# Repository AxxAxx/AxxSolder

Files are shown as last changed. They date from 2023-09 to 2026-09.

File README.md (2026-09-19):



<a href='https://ko-fi.com/axxaxx' target='_blank'>Donate  

Interested in purchasing an AxxSolder 3.2?  
On my website [5Dimensions](https://www.5dimensions.se/) you can purchase assembled and tested AxxSolder 3.2 boards with connectors and hardware.  

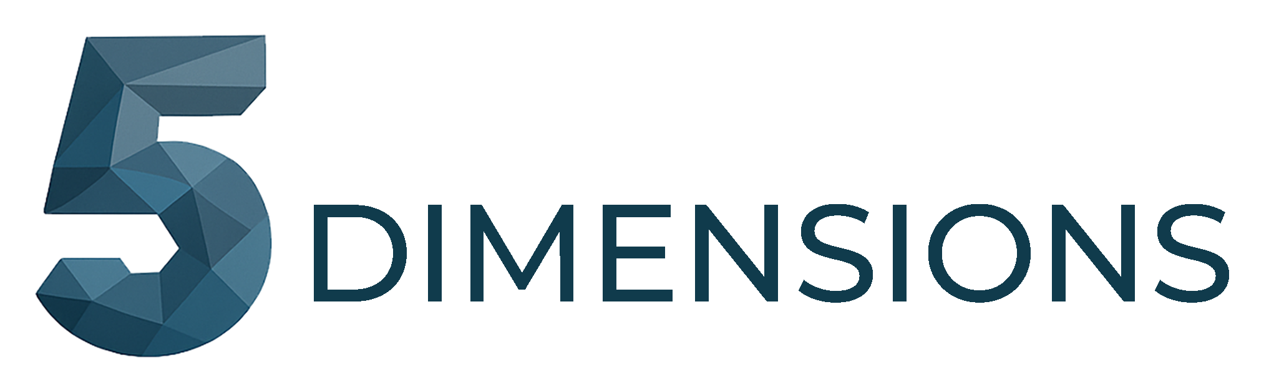
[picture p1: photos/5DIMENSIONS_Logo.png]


# AxxSolder Overview
AxxSolder is a STM32 based soldering iron controller for JBC C115, C210 and C245 style cartridges.  
Two different versions are designed around the same PCB and software - one soldering station based on the [JBC ADS stand](https://www.jbctools.com/ad-sf-stand-for-t210-t245-handles-product-2018.html) and one portable version. The AxxSolder hardware takes a DC input source of 9-24V OR a USB-C Power Delivery source. The recommended power supply is a Meanwell [LRS-150-24](#recommended-power-supply) which can power all compatible JBC irons at full power. If a 65W, 20V USB-PD supply is used then NT115 and T210 handles can be powered at full power and T245 at limited power. The power limiting is automatic and AxxSolder reads the power capability of the USB-PD source during the negotiating phase and reduces the output power accordingly.  
The software is written for the [STM32G431CBT6](https://www.st.com/en/microcontrollers-microprocessors/stm32g431cb.html) and implements a PID controller for temperature regulation, TFT display driver, sleep functions for when the handle is at rest and various user settings to name a few.  
Enclosures for both station and portable versions are 3D printed and design files are available under [/CAD](https://github.com/AxxAxx/AxxSolder/tree/main/CAD). A video showing the AxxSolder station can be found under [DEMO](#DEMO). A *bill of materials* (BOM) with individual component prices can be found under [/bom](https://github.com/AxxAxx/AxxSolder/tree/main/AxxSolder_hardware/bom).  
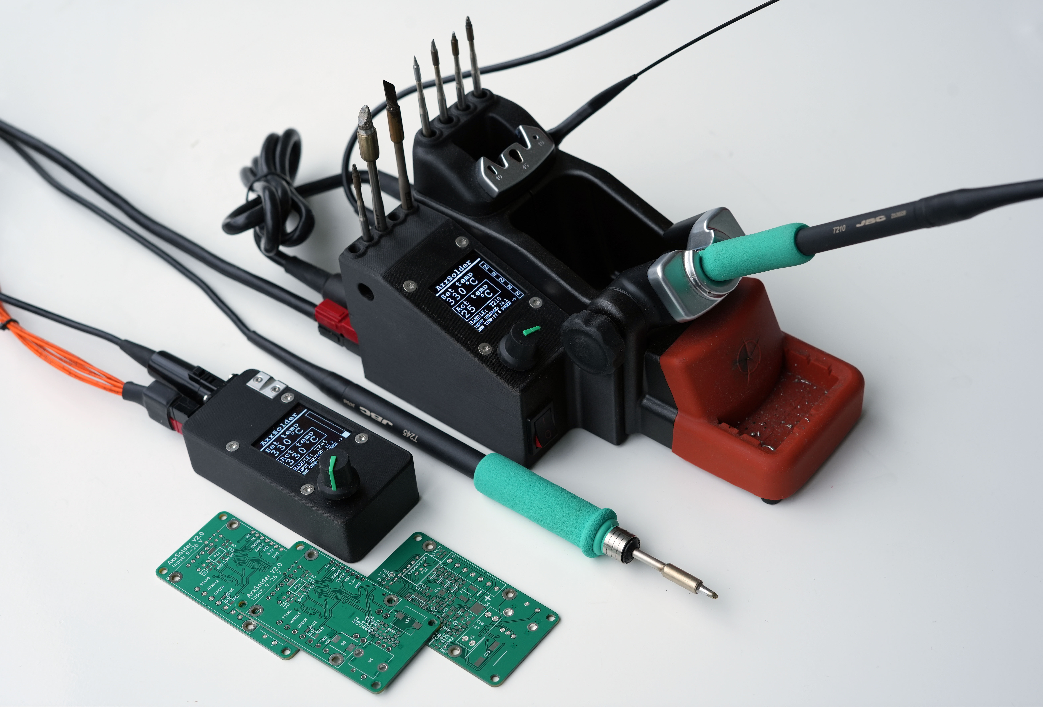
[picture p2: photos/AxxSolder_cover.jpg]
coverphoto


# Questions and support
Please use [Discord](https://discord.gg/AwpHEmsyKj) for build related and general questions.

# Table of Contents
- [AxxSolder Overview](#axxsolder-overview)
- [Questions and support](#questions-and-support)
- [Features](#features)
- [DEMO](#demo)
- [GRAPHING](#graphing)
- [Schematic](#schematic)
- [How AxxSolder works](#how-axxsolder-works)
- [PCB](#pcb)
- [AxxSolder Station](#axxsolder-station)
- [AxxSolder Portable](#axxsolder-portable)
- [Recommended power supply for tip grounding](#recommended-power-supply-for-tip-grounding)
- [Handle identification and connections](#handle-identification-and-connections)
- [Firmware update](#firmware-update)
- [First start up after build](#first-start-up-after-build)
- [Settings](#settings)
- [Profiles](#profiles)
- [PID control](#pid-control)
- [Cartridge differences](#cartridge-differences)
- [Temperature calibration](#temperature-calibration)
- [Temperature measurement](#temperature-measurement)
- [Current measurement](#current-measurement)
- [Disclaimer](#disclaimer)

# Features
- The tip temperature is set by a rotary encoder. Pressing the encoder puts AxxSolder into Sleep mode and heating is turned off, press again to wake up.  
- AxxSolder is capable of driving C115, C210 and C245 style cartridges from JBC. With two handle sense inputs AxxSolder can determine if the connected handle is either a NT115, T210 or T245 and adjust max output power accordingly. The max output power is software limited to 130 W for T245, 65 W for T210 and 22 W for NT115 handles.
- When the handle is put into the stand (connected to Stand_sense) AxxSolder goes into "Standby mode". On the portable version an aluminium plate is mounted in the case and allows the AxxSolder to go into Standby mode when the cartridge or handle rests against it. After 10 min in Standby mode AxxSolder goes into "Sleep mode" and heating is completely turned off. This is similar to what JBC calls [Sleep and Hibernation](https://www.jbctools.com/intelligent-heat-management.html).  
- If AxxSolder is left in normal running mode for longer than 30 min, the station automatically goes into sleep mode after 30 min as a safety feature.  
- Should the temperature ever go higher than 490 °C overheating is detected and the station goes into sleep mode in order to protect the tip.
- At start-up any USB-PD source is detected and the highest possible power is negotiated. AxxSolder limits the soldering iron output power to the max output power of the USB-PD source automatically. The maximum power output is displayed at the top of the power bar graph on the display.
- User settings are stored in non-volatile flash and can be configured via a settings menu described in [SETTINGS](#settings).
- The two buttons are used to store temperature presets, e.g. 330 °C and 430 °C. Both preset temperatures are configurable in the settings menu. The stored preset temperature can be updated to the current set temperature by long-pressing the preset button.
- There is a 3.3 V logic level output (GPIO4) that can be configured to go high when the iron is in Run mode, controlling e.g. fume extractor via a MosFET or relay.
- The TFT display used in this project is a 2 inch 320x240 Color TFT display [2.0" 320x240 Color IPS TFT Display](https://www.adafruit.com/product/4311) and shows information about:
  - Set temperature
  - Actual temperature
  - Current power as a bar graph
  - In case of sleep mode, the power bar shows "ZzZzZz"
  - In case of Standby mode, the power bar shows "STANDBY"
  - Input voltage
  - MCU temperature
  - Current detected handle type
  - Current max power output
  - Current power source USB-PD / DC
  - Graph showing set temperature, current temperature and power

# DEMO
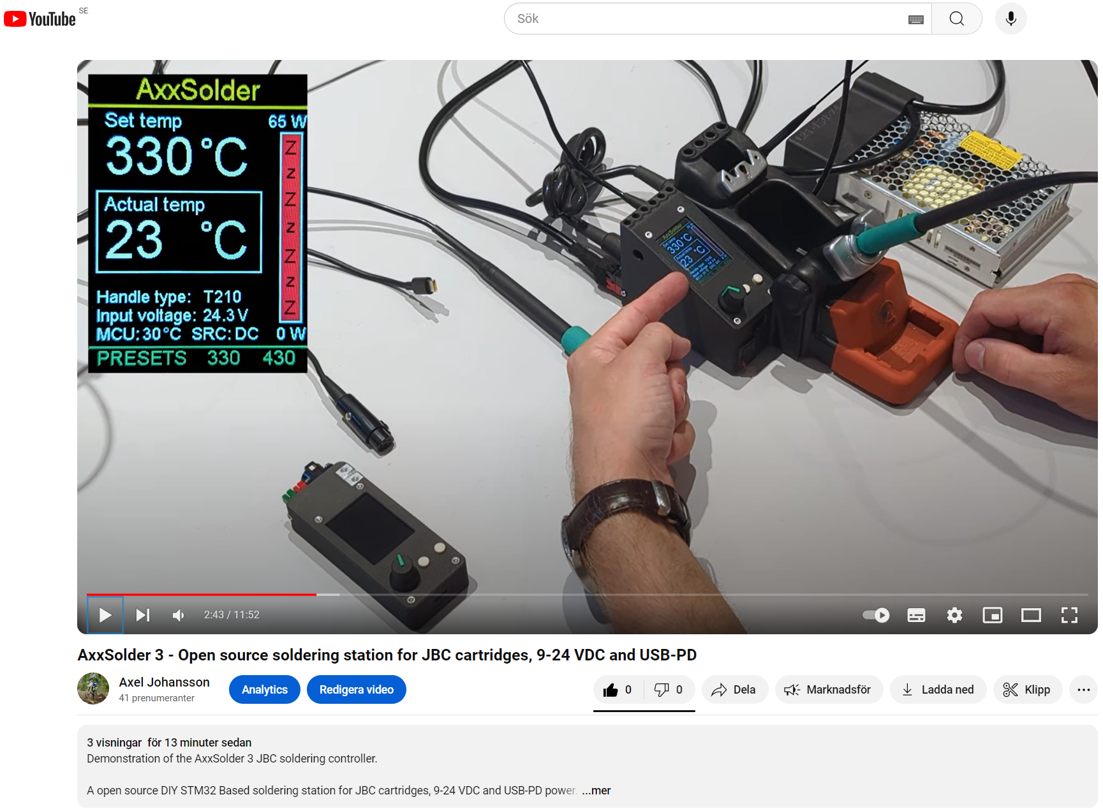
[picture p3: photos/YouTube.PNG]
YouTube (https://www.youtube.com/watch?v=I5uLvEM9wpY)
  
[https://www.youtube.com/watch?v=I5uLvEM9wpY](https://www.youtube.com/watch?v=I5uLvEM9wpY)

# GRAPHING
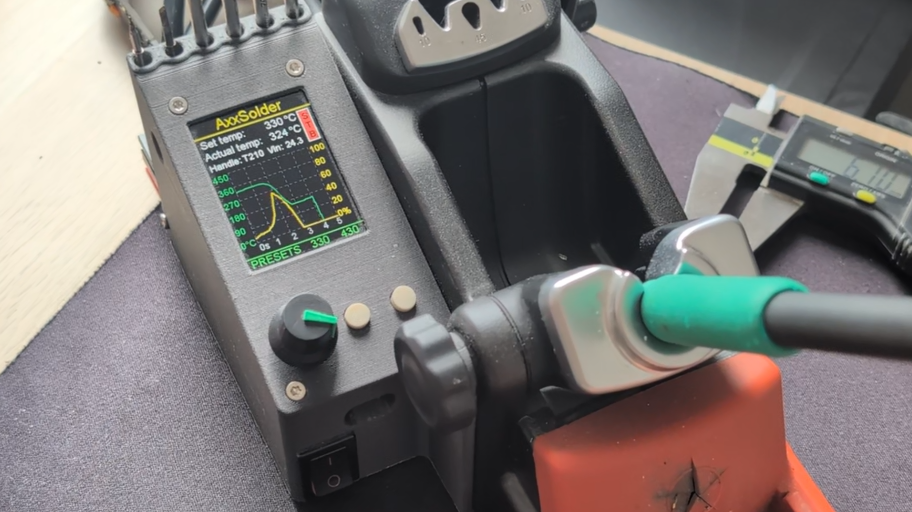
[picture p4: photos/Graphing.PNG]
YouTubeGraph (https://www.youtube.com/watch?v=BTZFAHj0sKs)
  
[https://www.youtube.com/watch?v=BTZFAHj0sKs](https://www.youtube.com/watch?v=BTZFAHj0sKs)

# Schematic
The schematic for AxxSolder is shown below. Both station and portable versions use the same PCB and software. The MCU is a [STM32G431CBT6](https://www.st.com/en/microcontrollers-microprocessors/stm32g431cb.html). 
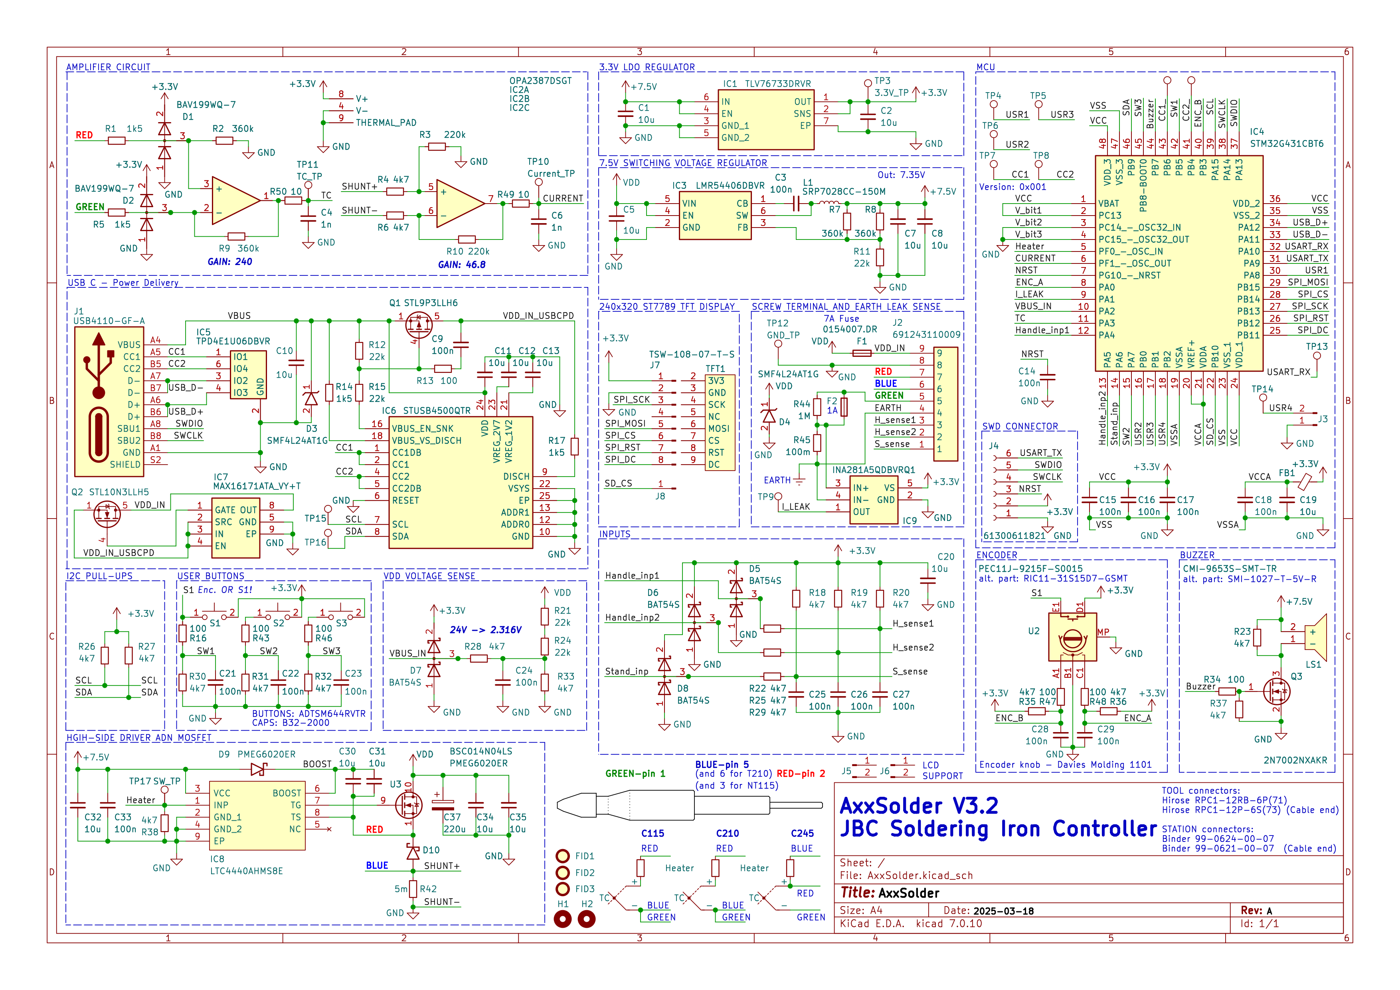
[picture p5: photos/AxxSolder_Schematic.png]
AxxSolder_station


# How AxxSolder works
All JBC cartridges contain a resistive heater element and a thermocouple. To determine how they are arranged internally, cross sections were made of a C210 and a C245 (see [Cartridge differences](#cartridge-differences)). These show that the heater and the thermocouple are connected in series and share the same wires out to the handle, so there is no separate sense pair. This means the station cannot heat and measure at the same time - the thermocouple output is only a few millivolts and is completely covered by the switching noise from the heater.

AxxSolder handles this by alternating between heating and measuring. Forty times a second a timer interrupt turns the heater off, waits 0.5 ms for the signal to settle, and triggers the ADC. The heater is switched back on as soon as the conversion is finished. The measurement window is short compared to the 25 ms between measurements, so very little heating power is lost and the control loop still gets a clean reading every cycle. On a scope you can see the PWM stop, a flat section appear, the ADC sample taken in the middle of it, and the switching resume. This is shown in detail under [Temperature measurement](#temperature-measurement).

## The amplifier
The thermocouple signal is amplified by one half of an **OPA2387** in a difference amplifier configuration, with 1.5 kΩ input resistors and 360 kΩ feedback resistors giving a gain of 240. Low-leakage BAV199 diodes clamp the input between ground and 3.3 V and protect the op-amp against transients from the heater switching. The OPA2387 is a zero-drift type, which matters at this gain: with an ordinary op-amp, the offset drift alone would add tens of degrees of error as the board heats up from the DC/DC converter next to it. The OPA2387 drifts around 0.01 µV/°C. The amplified value is converted to degrees by a second order polynomial fitted for each cartridge family against a Hakko FG-100 tip thermometer, and corrected further by up to six user calibration points, see [Temperature calibration](#temperature-calibration). Two sense pins in the handle connector tell the firmware which handle is connected and therefore which polynomial to use.

## The power stage
The heater is switched by a single **BSC014N04LS**, a 40 V, 1.4 mΩ N-channel MOSFET, on the high side: the drain sits on the supply rail and the source feeds the cartridge, which returns through a 5 mΩ shunt to ground. This is what makes the measurement possible. With the MOSFET off, no current flows and the whole cartridge is pulled to within a few millivolts of ground through the heater element, so the thermocouple sits at a common mode voltage the difference amplifier can work with. A low-side switch would leave the cartridge floating up to the supply rail whenever the MOSFET was off, which is exactly the moment the measurement has to be taken.

A high-side N-channel MOSFET needs a gate voltage above the supply rail, and this is provided by an **LTC4440A-5** bootstrap gate driver. It charges a capacitor from the 7.5 V rail through a Schottky diode while the MOSFET is off, and uses that charge to hold the gate about 7 V above the source when it turns on, with 1.1 A of peak pull-up current so the MOSFET crosses its linear region quickly. Conduction losses are low enough that no heatsink is needed anywhere on the board. The PWM frequency is 20 kHz, chosen to be just above the audible range so the bulk capacitors and the handle cable stay quiet.

## The microcontroller
The MCU is an **STM32G431CBT6**, a 170 MHz Cortex-M4F running from its internal RC oscillator. It is intended for motor control, which suits this application well: fast advanced-timer PWM, two independent 12-bit ADCs and enough DMA to keep sampling away from the CPU. ADC1 runs a circular DMA buffer with three interleaved channels - thermocouple, bus voltage and MCU temperature - which are averaged in software. ADC2 is used for the heater current shunt, so a current measurement can be started from the PWM timer's own interrupt without disturbing the temperature sampling, see [Current measurement](#current-measurement).

## Temperature regulation
Temperature is regulated by a PID controller computing a new output every 25 ms, with parameters stored per cartridge profile. The output sets the heater duty cycle and is bounded between zero and full power, and that bound is what makes a plain PID unsuitable here. A heat-up from room temperature is a 300 °C error, and the duty cycle stays at its maximum for the whole ramp regardless of what the controller asks for - the actuator is saturated. An unmodified integral term keeps accumulating error throughout, even though the additional output has no effect on the plant. This is integral windup. By the time the tip reaches the setpoint, the integral term holds a large value that can only be removed by accumulating error of the opposite sign, so the controller continues driving the heater past the setpoint until it has unwound. A soldering iron is also an asymmetric plant: heating is active, but cooling is only passive loss to the surroundings, so an overshoot takes considerably longer to recover from than an undershoot. Several anti-windup measures are therefore used. Conditional integration blocks the integral term entirely while the error is above 75 °C, so the ramp is driven by P and D alone. Clamping holds integration for a cycle if the update would push the output past its limits while the error is still driving in the same direction, and the accumulated term has its own limit separate from the output limit. The integral gain is raised for negative errors so that an overshoot is unwound faster than it was built up, and the derivative term acts on the measured temperature rather than the error to avoid a derivative kick when the setpoint is changed. A heat-up to 330 °C takes about 1.5 seconds on a C210-002 with very little overshoot, tuned using the firmware's serial stream of setpoint, temperature and the individual P, I and D contributions. The tuning parameters are listed under [PID control](#pid-control).

# PCB
The PCBs are designed in KiCad and manufactured by [PCBWay](https://www.pcbway.com/). PCBWay has sponsored this project with PCBs and stencils. The support and quality from PCBWay is great and therefore PCBWay is the recommended PCB supplier for this project. As some components have a rather fine pitch (0,5 mm as of the LQFP-48 package of the STM32) and some packages are "no lead" with a bottom thermal pad e.g. the WSON-8 package of the OPA2387 it is recommended to use a stencil to apply solder paste and then reflow the board using either a reflow oven or hot-plate. The boards on the image below were reflowed on a hot-plate (a homemade AxxPlate). A microscope is also recommended and helpful during assembly.
Printed Circuit Boards with assembled components are shown in the image below.
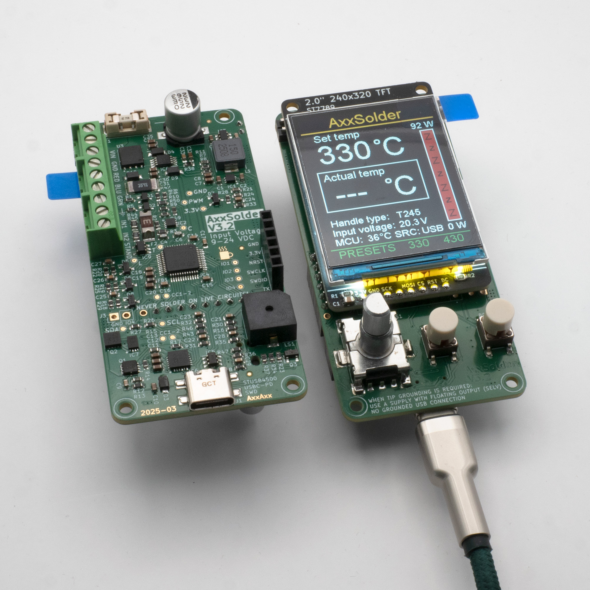
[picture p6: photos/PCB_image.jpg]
PCB_image

A 3D view (front and back) of the AxxSolder PCB is generated with KiCad and shown below. 
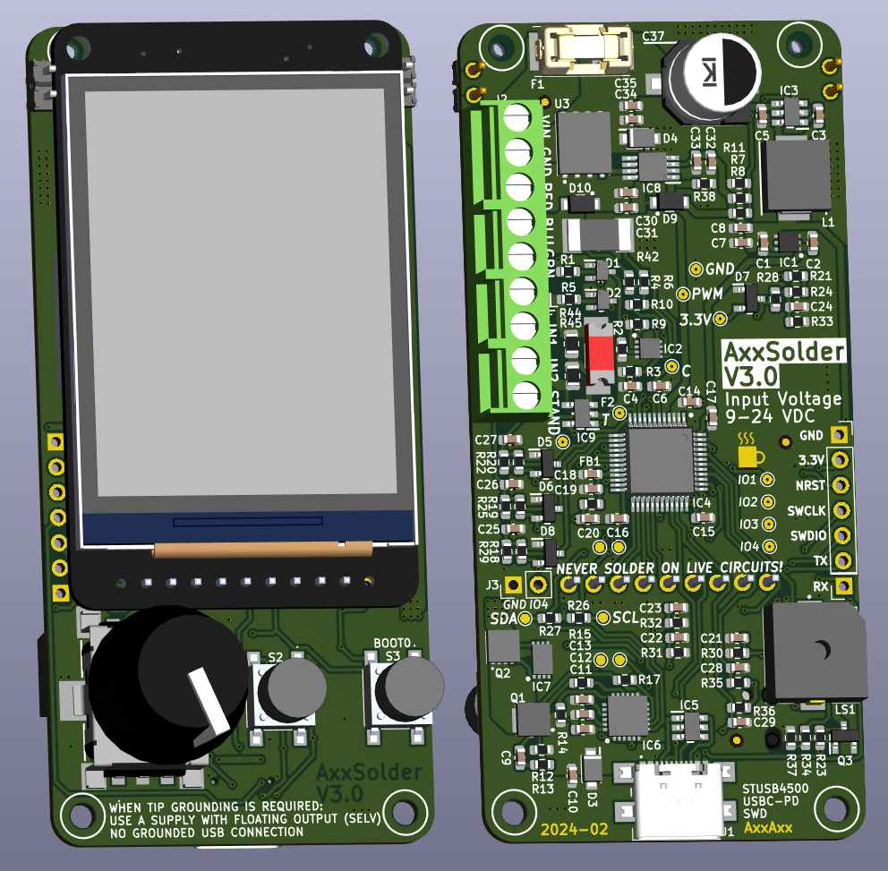
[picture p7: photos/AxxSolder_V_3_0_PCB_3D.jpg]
PCB_3D


# AxxSolder Station
The preferred setup is to pair AxxSolder with the [JBC ADS stand](https://www.jbctools.com/ad-sf-stand-for-t210-t245-handles-product-2018.html). This makes a very nice, compact and powerful soldering station. The JBC ADS stand is paired with a custom 3D printed enclosure for AxxSolder and the PCB is mounted with two mounting brackets. All 3D printed parts are available under [/CAD](https://github.com/AxxAxx/AxxSolder/tree/main/CAD). 
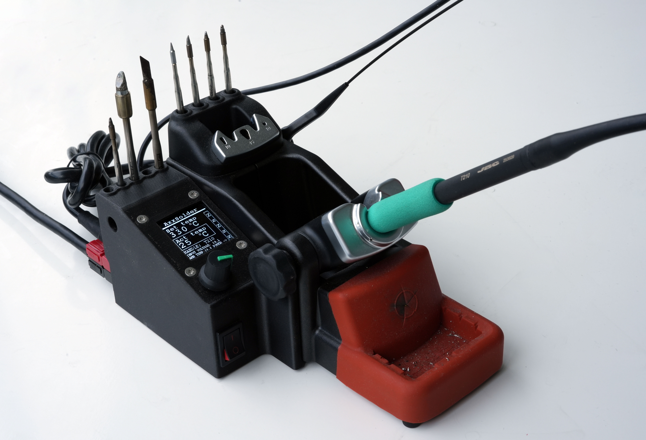
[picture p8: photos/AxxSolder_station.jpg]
AxxSolder_station
  
The JBC ADS stand comes with a silicone cable fitted with two Binder 99-0621-00-07 connectors. In order to use this cable a Binder 99-0624-00-07 is mounted into the AxxSolder enclosure and wired as the image below:  
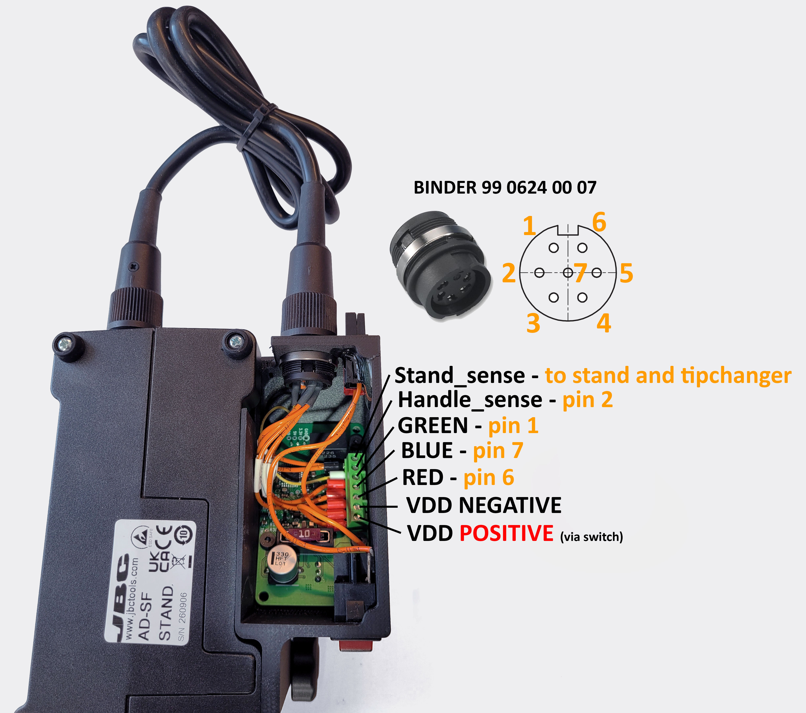
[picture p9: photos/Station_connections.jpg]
AxxSolder_station
  
By default, the stand separates the two signals coming from the "tool rest position" and the "tip change position" and does NOT have two separate connections for tip sensing 1 and 2 as is needed if NT115, T210 and T245 handles should all be automatically detected. Therefore, a modification is done to the PCB inside the JBC ADS stand in order to combine the "tool rest position" and the "tip change position" sense into one connection and separate the two tip sense connections. This is shown in the image above. The stand is held together with two PH0 screws from the side.  
NOTE: This modification of the stand is only needed if you want to be able to use NT115, T210 and T245 with your JBC ADS stand. If you know that you will only be using T210 and/or T245 you can change the user setting: Detect NT115 to "NO" in the settings in order for T210 and T245 to be automatically detected with a un-modified JBC ADS stand.
 
The JBC ADS stand is an expensive piece and thankfully there are many alternatives online for the one who wants to save some money. The community on the AxxSolder Discord channel has created many enclosures for alternative stands such as the GEEBOON SDC02, and some of the AiXun stands. Some of the models are available under [Alternative stands](https://github.com/AxxAxx/AxxSolder/tree/main/CAD/Alternative_enclosures_and_designs) .

# AxxSolder Portable
It is often nice to have a compact and portable soldering iron controller for when you are away from your comfortable desk. A neat powerful package with the same capabilities as your main soldering station. This is why AxxSolder Portable was designed. The only difference between AxxSolder station and Portable is the enclosure.  
As AxxSolder accepts an input of 9-24 V it is compatible with a range of battery options. The author usually use a battery pack consisting of 12 Samsung INR18650 35E in a 3S4P configuration which works very well.  
The portable version has an aluminium tab on the enclosure connected to the same input on the PCB as the "handle rest" on the station version. This allows the user to rest the iron onto the aluminium tab and automatically enter sleep mode.   
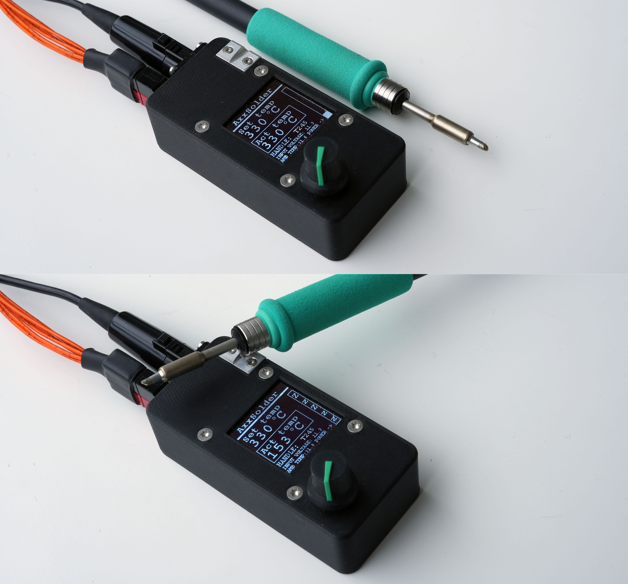
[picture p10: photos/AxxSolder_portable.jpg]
AxxSolder_portable

The connections from the handle to the PCB through the Hirose RPC1-12RB-6P(71) connector is shown below. The Stand_sense in the portable version is connected to the aluminium plate which tells the AxxSolder to go into sleep mode when in contact with the soldering iron.  
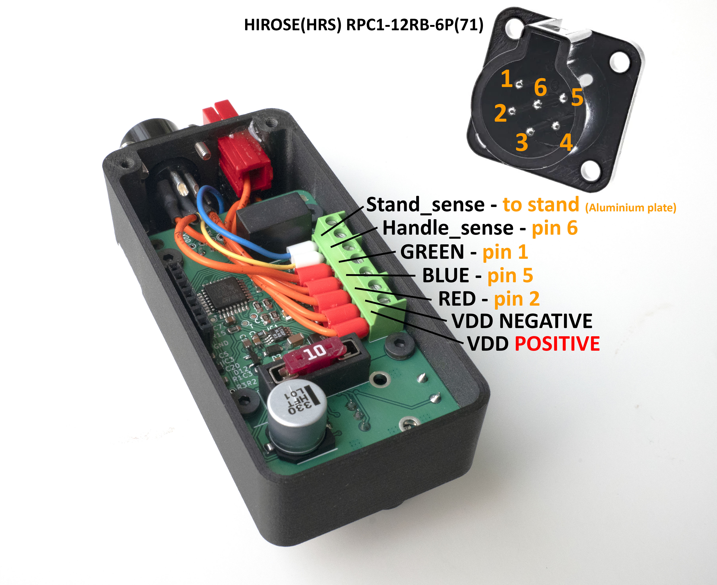
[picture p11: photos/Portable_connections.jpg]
AxxSolder_portable


# Recommended power supply for tip grounding
⚠️ WARNING: Do NOT use power supplies where the DC output is referenced to mains earth (PELV). Due to the internal construction of C245 tips, using a PELV supply can cause a short circuit through the soldering tip. This applies to both DC barrel jack and USB-C power.

In order to be able to ground the tip of the soldering iron the user MUST use a power supply with a floating output (SELV) and connect protective earth to the ground terminal on AxxSolder. No other devices should share this DC power other than AxxSolder itself. A well-suited power supply with floating output (SELV) is the Meanwell LRS-150-24. It is rated for 156 W at 24 V. By using this kind of power supply, AxxSolder can be connected directly its DC output and to mains earth thus keeping the tip of the soldering iron at earth ground potential. There is a 1A fuse after the earth terminal in parallel with a 1M resistor on the AxxSolder.  
A printable cover protecting the terminals of the for LRS-150-24 can be found under [/CAD](https://github.com/AxxAxx/AxxSolder/tree/main/CAD).  
LRS-150-24
Another suitable power supply is the Meanwell XLG-150-24 or the GSM160A24-R7B which has a slightly different form factor, does not have the switching noise as the LRS-150-24 and is fully enclosed.

## USB-C power
Most USB-C chargers have floating outputs and work fine. However, some chargers connect the USB-C shell to mains earth — these must not be used as they create the same problem as a PELV DC supply.
  
# Handle identification and connections
In order for AxxSolder to know which type of handle (NT115, T210, T245) is attached specific pins inside the handle connector must be connected (bridged with a jumper wire). By default, the original JBC handle T245 has NO bridged pins while inside the connector of the original JBC T210 the pins 5 and 6 are bridged with a jumper wire. The original NT115 handle from JBC has a different connector and must be modified accordingly. All the necessary connections are shown in the image below.  
When powering on AxxSolder for the first time after doing these connections inside the handle connector it is wise to attach a handle without its cartridge and ensure that AxxSolder detects and shows the correct handle type on the display.  
Failing to detect the handle type may cause permanent damage to the cartridge as the temperature calibration and max allowed power will be wrong.  
❗WARNING❗ It has been discovered that some JBC clones have different pins bridged by the manufacturer. For example: Some AiXun T210 handles have pin 1 and 6 bridged, instead of pin 5 and 6 as AxxSolder requires for T210 handles. It is however easy to open up the connector and do the required pin connection.      
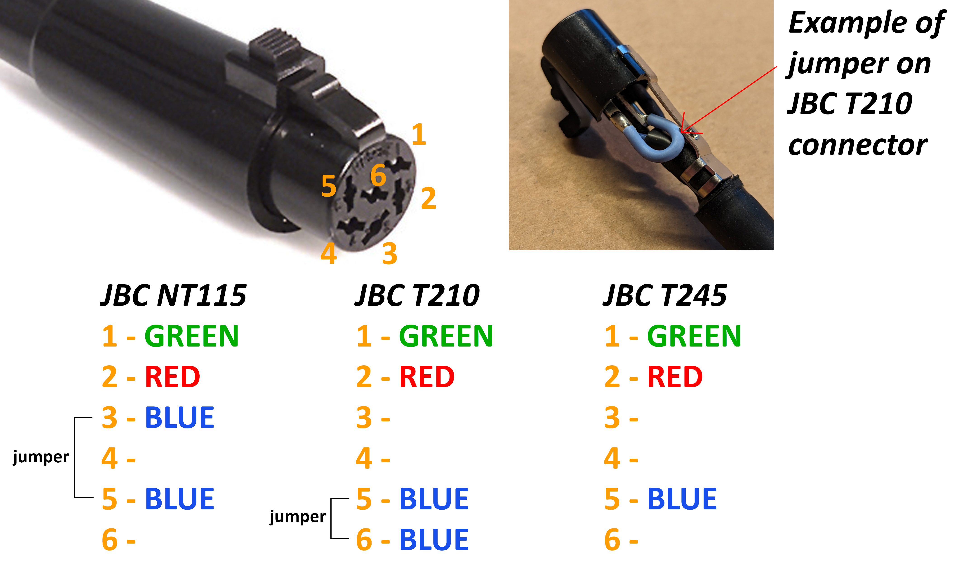
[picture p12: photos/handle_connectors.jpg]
Handle_connections


# Firmware update
Flashing or updating the firmware on the STM32 MCU can be done in two ways, by using a SWD programmer or directly via USB. 

## SWD programmer

These come in a variety of models and are available from several different places online. In the below example a [STLINK-V3MINIE](https://www.st.com/en/development-tools/stlink-v3minie.html) SWD programmer is used. The MCU is programmed by the following steps:
1. Disconnect any soldering iron handles from AxxSolder during the firmware update process.
2. Download the latest `AxxSolder.bin` file from [Releases](https://github.com/AxxAxx/AxxSolder/releases)
3. Connect your SWD programmer to the target MCU with GND, 3.3V, (N)RST, SWCLK and SWDIO (see table below)
4. If your SWD programmer *can not* supply 3.3V it is necessary to power the AxxSolder from an external supply.
5. Start your programming software. [STM32CubeProgrammer](https://www.st.com/en/development-tools/stm32cubeprog.html) is used in this example.
6. Connect to the target by selecting *ST-LINK* and click on *Connect*
7. Load the latest `AxxSolder.bin` downloaded in *Step 2* by clicking *Open file* and select the downloaded binary file.
8. Write the firmware to the MCU by clicking *Download*.
9. If you get the message *File download complete* everything succeeded and the SWD programmer can be disconnected and AxxSolder power cycled once and AxxSolder should boot.
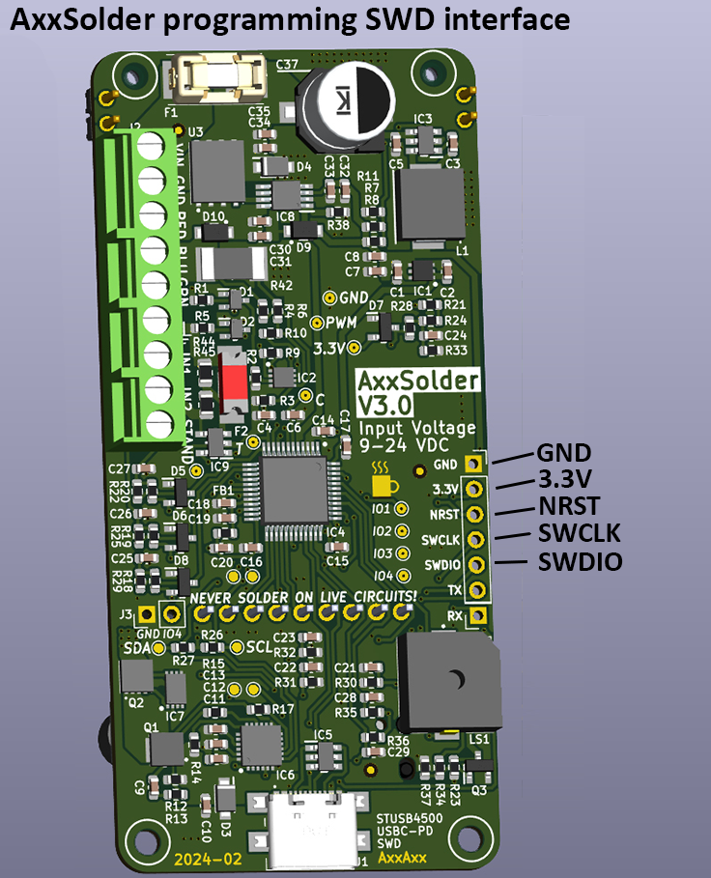
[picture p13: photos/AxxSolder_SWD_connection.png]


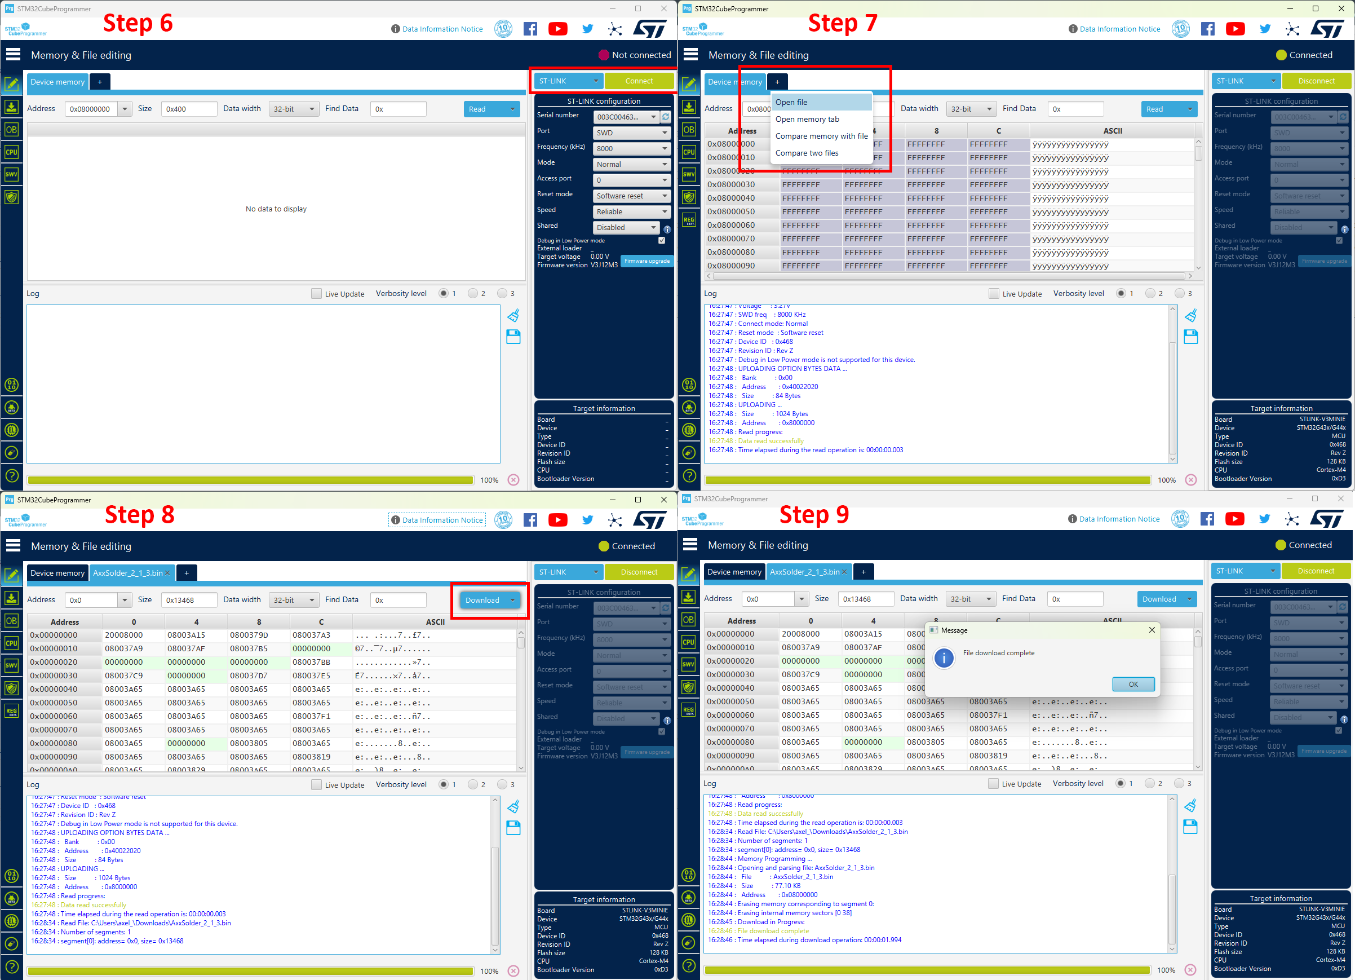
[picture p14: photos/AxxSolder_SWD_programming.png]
AxxSolder_SWD_programming


| STLINK-V3MINIE CN2 | AxxSolder J4 |
|---|---|
| GND | GND |
| VCC | 3.3V |
| RST | (N)RST |
| CLK | SWCLK |
| TMS | SWDIO |

## USB (DFU mode)

1. Disconnect any soldering iron handles from _AxxSolder_ during the firmware update process.
2. Download the latest `AxxSolder.bin` file from [Releases](https://github.com/AxxAxx/AxxSolder/releases)
3. Connect the AxxSolder via USB to a computer that runs [STM32CubeProgrammer](https://www.st.com/en/development-tools/stm32cubeprog.html) - hold down the rightmost button (S3) while plugging in the USB connector in order to enter DFU mode (your safest bet is to use a USB-A to USB-C cable, because in some cases the PD negotiation may mess things up - a USB-C to C cable that is known to **not** support PD negotiation (CC lines unconnected) can alternatively be used).
5. Connect to the target by selecting *USB* and click on *Connect*
6. Load the latest `AxxSolder.bin` downloaded in *Step 2* by clicking *Open file* and select the downloaded binary file.
7. Write the firmware to the MCU by clicking *Download*.
8. If you get the message *File download complete* everything succeeded and the USB cable can be disconnected.
9. Power cycle once and AxxSolder should boot.

# First start up after build
The first start up after you have built your AxxSolder can be intense. Double check all solder connections under a loupe/microscope before applying power. Especially the OPA2387, LTC4440 and the STM32G431 are all small packages with tight pad spacing and can have solder bridges. Do also double check the connections to the soldering iron/stand which are shown in this document under [AxxSolder Station](#axxsolder-station) and [AxxSolder Portable](#axxsolder-portable).  
The first thing to do after you have double-checked everything is to follow the steps under [Firmware update](#firmware-update). It is wise to do the first programming of AxxSolder without any handle piece and with only 3.3 V, not VDD. After the programming is done you can now power up AxxSolder again via 3.3 V, this time you can also attach your handle. This allows you to test that your handle type is detected correctly (the detected handle type NT115/T210/T245 is shown in the display). The Standby feature can also be tested by touching the stand (STAND Input).  
If the handle is detected correctly, the Standby function works and the display works you proceed to test the 7.35V DC/DC. This is done by once again disconnecting the handle, but this time apply current limited 9-24 V VDD. 100 mA at 24 V is enough to check that the display starts and that you can measure the three bus voltages; 3.3 V, 7.35 V and VDD. If the bus voltages looks good and the display shows the main screen you are ready to apply full VDD power and attach the soldering handle.  
If you are not 110% sure about your soldering/connections it is wise to be on the safe side and keep your soldering tip in a water bath in order to prevent it from over-heating in an uncontrolled manner. During the development of AxxSolder this method was used and saved a few of those expensive JBC cartridges..

# Settings
To access the user settings the user holds down the encoder button at start-up or long-press the encoder button. A SETTINGS text is then presented and the button can be released. While in the settings there are several parameters available grouped together under MODE, PRESETS, PROFILES, DISPLAY, SOUND and SYSTEM.
| Group | Setting | Description  | Unit | Default |
|----|---|---|---|---|
|MODE|Startup Temp °C|Default temperature selected after boot|°C|330|
|MODE|Temp Offset °C|Temperature offset applied to measured temperature|°C|0|
|MODE|Standby Temp °C|Temperature to go to after handle is set in stand|°C|150|
|MODE|Standby Delay [s]|Time between putting the handle in the stand to going into standby mode|seconds|0|
|MODE|Standby Time [min]|Time for which standby temperature is held before cooling down|minutes|10|
|MODE|Sleep Time [min]|Time that the iron can be ON before cooling down (safety feature)|minutes|30|
|SOUND|Buzzer Enable|Enable or Disable the buzzer|YES/NO|YES|
|PRESET|Preset Temp 1|Preset temperature for button 1|°C|330|
|PRESET|Preset Temp 2|Preset temperature for button 2|°C|430|
|MODE|GPIO4 ON at run|Enable 3.3V output on GPIO4 when the iron is in run mode|YES/NO|NO|
|DISPLAY|Screen rotation|Rotate the screen|0°, 90°, 180°, 270°|0°|
|MODE|Momentary stand|Use the stand as momentary switch to go between modes (useful on AxxSolder Portable)|YES/NO|NO|
|MODE|I measurement|Measure the heater current|YES/NO|YES|
|SOUND|Startup beep|Beep after startup|YES/NO|YES|
|DISPLAY|Temperature unit|Show temperatures in Celcius or Fahrenheit|°F/°C|°C|
|MODE|Serial DEBUG|Print debug over serial|YES/NO|NO|
|DISPLAY|Displayed temp filter|Moving average filter length|Length|5|
|MODE|Startup temp is previous temp|Startup temp is previous used temp|YES/NO|NO|
|MODE|3-button mode|Use 3-button mode|YES/NO|NO|
|SOUND|Beep at set temp|Beep at set temp|YES/NO|YES|
|SOUND|Beep tone|Beep tone|0,1,2,3|0|
|DISPLAY|Show power|Current power under the bar graph is displayed in this unit|W/%|W|
|MODE|Detect NT115|Detect NT115 handles or not. Useful to turn OFF for un-modified JBC SDA stands|YES/NO|YES|
|TIPS|Limit Power T245 [W]|Limit the output power|"0"=no user limit, "5"=5 W, "10"= 10 W, "15"= 15 W ...|0|
|TIPS|Limit Power T210 [W]|Limit the output power|"0"=no user limit, "5"=5 W, "10"= 10 W, "15"= 15 W ...|0|
|TIPS|Limit Power NT115 [W]|Limit the output power|"0"=no user limit, "5"=5 W, "10"= 10 W, "15"= 15 W ...|0|
|TIPS|Limit Power No name [W]|Limit the output power|"0"=no user limit, "5"=5 W, "10"= 10 W, "15"= 15 W ...|0|
|DISPLAY|Display graph|Display the Graph view|YES/NO|NO|
|MODE|Delta T detect|Detect too large delta temperatures and stop heating|YES/NO|YES|
|MODE|Profile on tip chg.|Show popup when changing tip asking for tip preset|YES/NO|NO|
|MODE|Change Enc. dir.|Changes the direction of the encoder|YES/NO|NO|
|MODE|Enc. step|Changes amount of steps per encoder tick|1,2,5,10|2|
|MODE|Heat at startup|If enabled AxxSolder starts to heat at startup|YES/NO|NO|
|SYSTEM|-Load Default-|Load default parameters|N/A|N/A|
|SYSTEM|-Save and Reboot-|Exit and Save|N/A|N/A|
|SYSTEM|-Exit no Save-|Exit without Save|N/A|N/A|

# Profiles
Under the setting menu Profiles the user can select, adjust and create new profiles for the supported cartridge types. name, PID parameters, calibration data and power limits can be set individually for each profile and are saved to flash. A more detailed instruction can be found under [PROFILES.md](./docs/PROFILES.md)
# PID control
The thermal mass and heat convection differs between different tip designs. Therefore the PID parameters should in theory be adjusted to each different cartridge. This can be done byutilizing custom profiles. The default PID parameters for the supported cartridges has however shown good thermal performance and are a good baseline.

```c
/* Cartridge type specific PID parameters */
#define KP_NT115        5
#define KI_NT115        2
#define KD_NT115        0.3
#define MAX_I_NT115     300

#define KP_T210         7
#define KI_T210         4
#define KD_T210         0.3
#define MAX_I_T210      300

#define KP_T245         8
#define KI_T245         2
#define KD_T245         0.5
#define MAX_I_T245      300

/* General PID parameters */
#define PID_MAX_OUTPUT          500
#define PID_UPDATE_INTERVAL     25
#define PID_ADD_I_MIN_ERROR     75
double PID_NEG_ERROR_I_MULT =   7;
double PID_NEG_ERROR_I_BIAS =   1;

/* Max allowed power per handle type */
#define NT115_MAX_POWER         22
#define T210_MAX_POWER 	        65
#define T245_MAX_POWER 	        130
```
The PID parameters are adjusted to achieve a fast response with minimum overshoot and oscillation. The below image is showing the set temperature, actual temperature response as well as the P, I and D contributions during a heat-up cycle from 25 °C to 330 °C. This heat-up sequence takes ~1.5 seconds for a C210-002 cartridge.  

The below screenshot if from the serial terminal software [AxxTerm](https://github.com/AxxAxx/AxxTerm)  

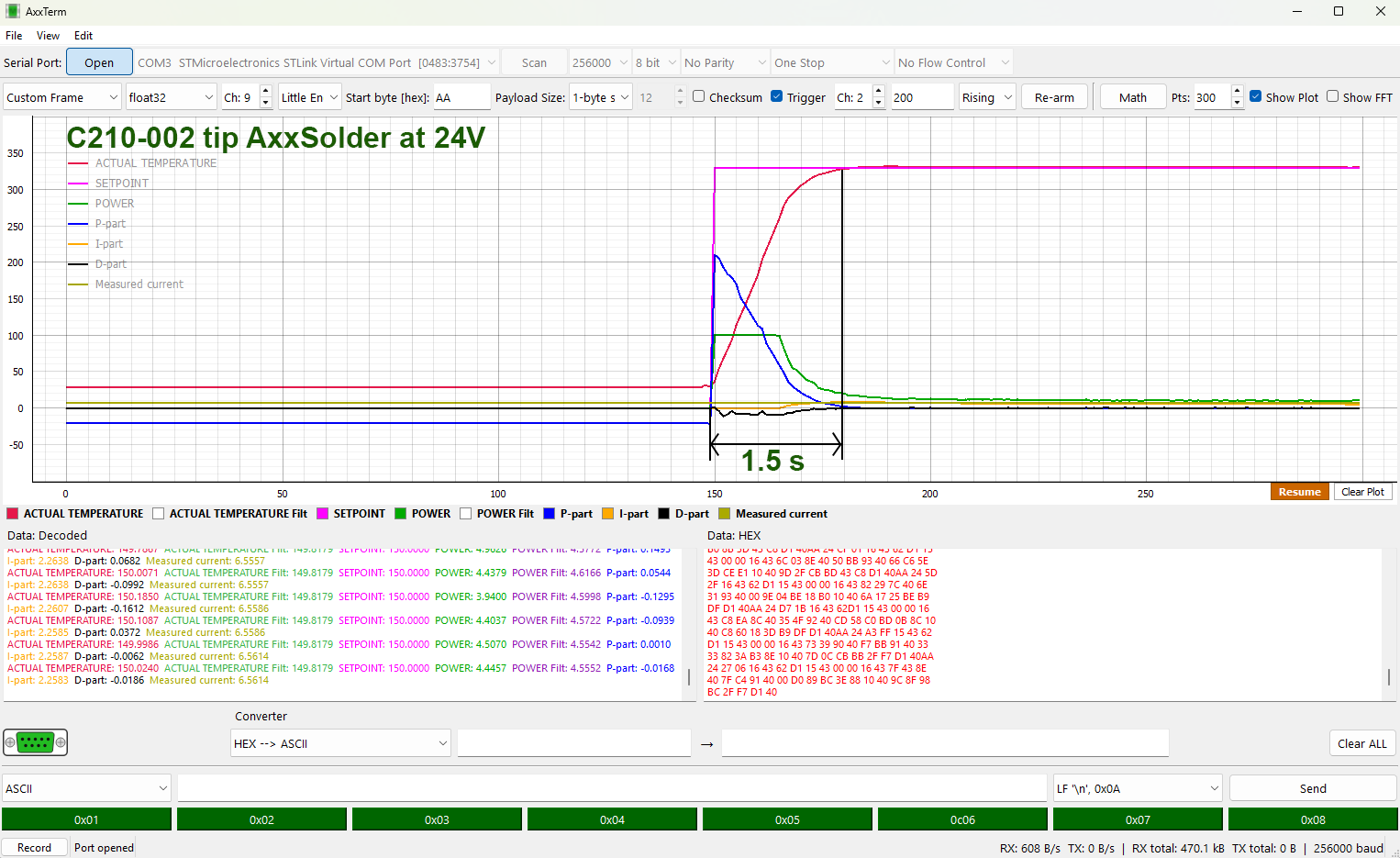
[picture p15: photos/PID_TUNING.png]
AxxSolder_pid
 

# Cartridge differences
Cartridges from JBC do all contain a thermocouple element to read the tip temperature and a resistive heater element. The configuration of thermocouple and heater element differ slightly between cartridge models. In order to determine the internal configuration of the cartridges two cross sections were done. These show clearly how the C210 and C245 cartridges are constructed internally. The images can be seen here: [https://www.eevblog.com/forum/projects/axxsolder-jbc-soldering-controller](https://www.eevblog.com/forum/projects/axxsolder-jbc-soldering-controller/msg5124267/#msg5124267).  
As the thermocouple output also differs (see my measurements [Temperature calibration](#temperature-calibration)) the correct handle/cartridge type has to be set. This is done automatically be the inputs "Handle_sense_1" and "Handle_sense_2" This can be done thanks to the design of the handle connector. For the JCB T210 handle pin 5 and 6 are connected internally in the connector and for NT115 pin 3 and 5 should be connected. This allows AxxSolder to sense which handle is connected and assign correct thermocouple correction, PID parameters and max output power.
 
# Temperature calibration
The voltage from the thermocouple embedded inside the cartridge is amplified by an OPA2387 operational amplifier and then read by the ADC of the MCU. To correlate the measured ADC value to the cartridge temperature experiments were done. A constant power was applied to the heating element of the cartridge and the ADC value was read as well as the actual tip temperature. The tip temperature was measured by a "Soldering Tip Thermocouple" used in e.g. the Hakko FG-100.   
The measured data was recorded and plotted for both the C115, C210 and C245 cartridges. The specific cartridges used were the C115112, C210-007 and C245-945. The measured data were fitted to polynomial equations:  
$Temp_{C115}[deg] =  5.10e^{-5} * ADC^2 + 0.42* ADC + 20.15$  
$Temp_{C210}[deg] =  4.22e^{-6} * ADC^2 + 0.32* ADC + 20.97$  
$Temp_{C245}[deg] = -4.73e^{-7} * ADC^2 + 0.12* ADC + 23.78$  
These are then used in the software to retrieve correct tip temperatures.
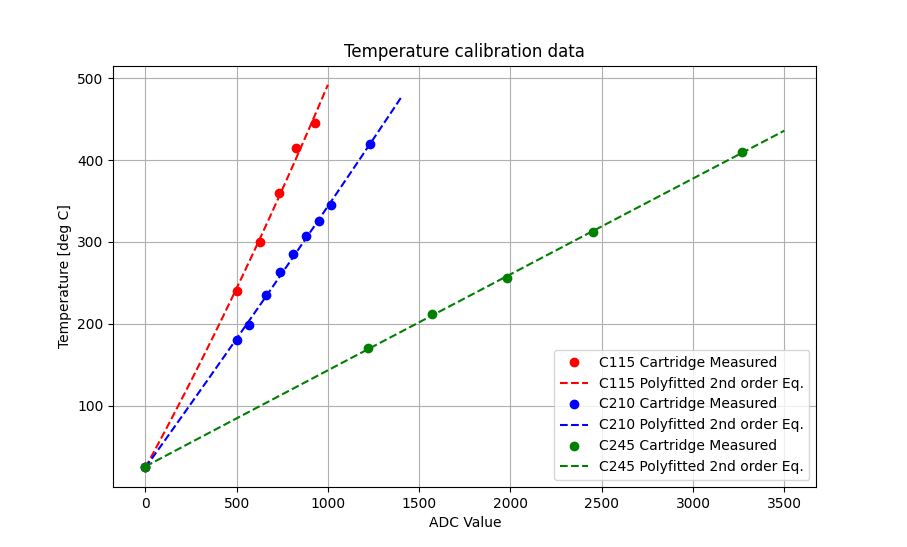
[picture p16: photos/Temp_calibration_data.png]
Temp_calibration


The user can adjust the temperature calibration at 6 points in order to compensate for variations in the cartridge thermocouple.  
To calibrate temperature(s):
- Make sure that the temperature calibration values are at their default nominal values in the settings.
- Set AxxSolder to the temperature that you want to calibrate. for example 300 °C.
- When AxxSolder stabilizes around the setpoint, measure the actual tip temperature by using a soldering tip thermocouple, for example the HAKKO FG-100B.
- Input the actual measured temperature, let's say 302 °C into the 300 °C calibration setting ("Temp cal 300" = 302).
  
AxxSolder will then use this calibration point and correct the temperature accordingly. It will do so linearly between all calibration points.

# Temperature measurement
As the thermocouple and heater element is connected in series inside the JBC cartridges and the thermocouple voltage measures over the same pins as the heating element we have to be careful when to do the temperature measurement. In order to not disturb the thermocouple measurement with heater element switching, the switching is turned off for 0.5 ms just before the temperature measurement is taken. The 0.5 ms delay ensures that the switching is turned off and the thermocouple signal is stabilized around a stable voltage.  
The measured signal over the thermocouple is clamped to 3.3V with a BAV199 low-leakage switching diode in order to protect the op-amp OPA2387. The voltage measurement is taken by the internal ADC in DMA mode with a circular buffer. The buffer holds several measurements which are averaged and filtered in software.  
The yellow curve in the image below (Channel 1) shows the PWM signal driving the gate of the MOSFET.  
The green curve shows the amplified voltage between GREEN and RED wire in the JBC handle at 330 °C and 10% power, and the cyan curve at 100 °C and 100% power (the tip cooled down trying to heat up).  
The blue pulse indicates the wait time of 0.5 ms and the magenta pulse is where the ADC is sampled.
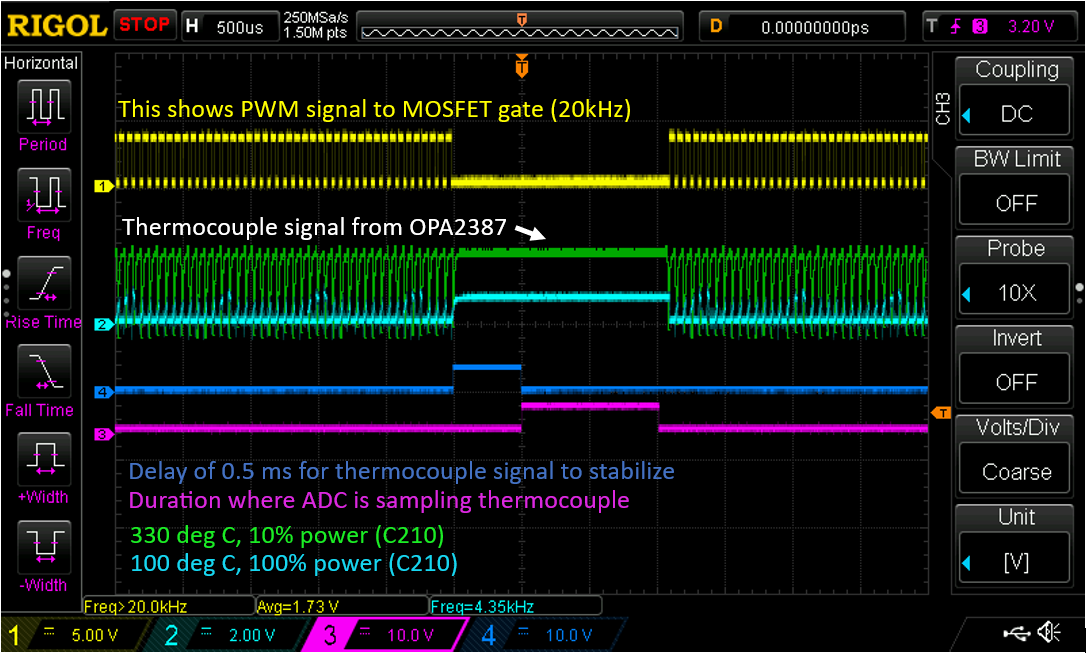
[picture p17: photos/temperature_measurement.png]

# Current measurement
The current is sampled four times per second by a 30 us current pulse through the heater. This is done both to check if there is a functioning tip in the handle (otherwise the display shows "---" at current temp) and to be able to calculate the power drawn by the heater. By knowing how much the heater draws in ampere the actual power can be calculated by knowing the bus voltage and pulse duty cycle. to measure the current the gate to the MOSFET is turned on, 10 us later the voltage over the current shunt is sampled by the ADC and the result is converted. This is shown the image below.
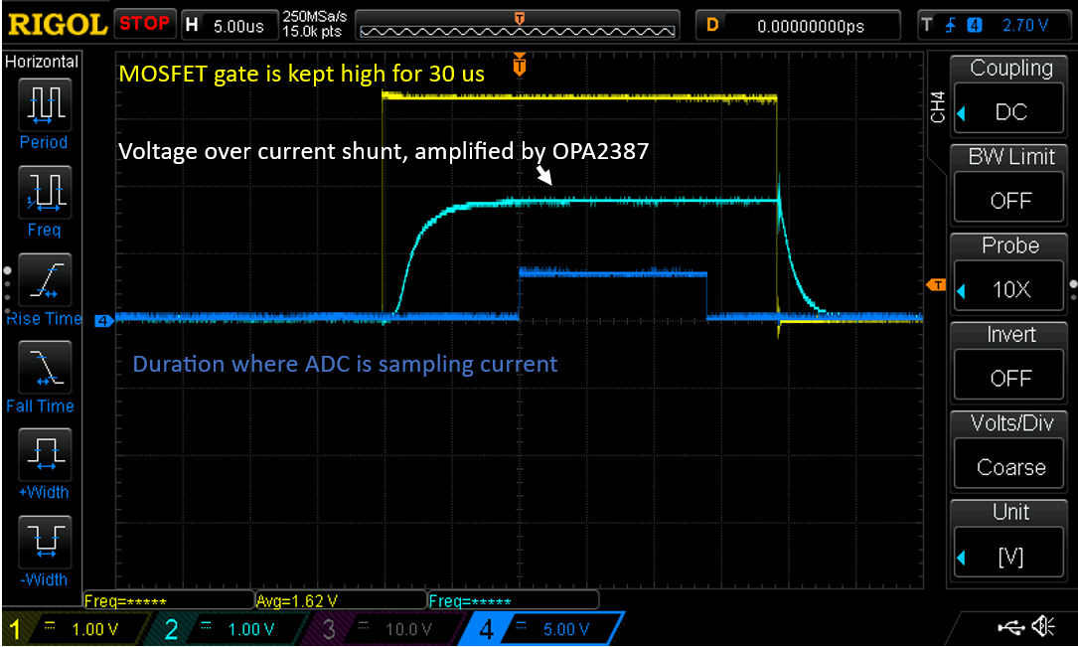
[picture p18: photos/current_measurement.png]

# Disclaimer
AxxSolder is an open source project and has absolutely no warranty, or guarantees on functionality or reliability! The authors of this project accept absolutely no liability for any harm or loss resulting from its use. That said, have fun. :)
## Stargazers over time
Stargazers over time (https://starchart.cc/AxxAxx/AxxSolder)

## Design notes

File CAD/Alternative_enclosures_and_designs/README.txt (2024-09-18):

In this folder you can find alternative CAD models of enclosures that others have designed.

The owner (AxxAxx) of the AxxSolder repo do not take credit nor provide support for these designs. 
But they are probably very nice and of good quality if they have been merged into here! :)

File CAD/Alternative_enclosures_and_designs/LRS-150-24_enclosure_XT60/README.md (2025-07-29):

# Alternative LRS150 enclosure

A slightly different enclosure for MeanWell LRS150, 24 volts in particular.

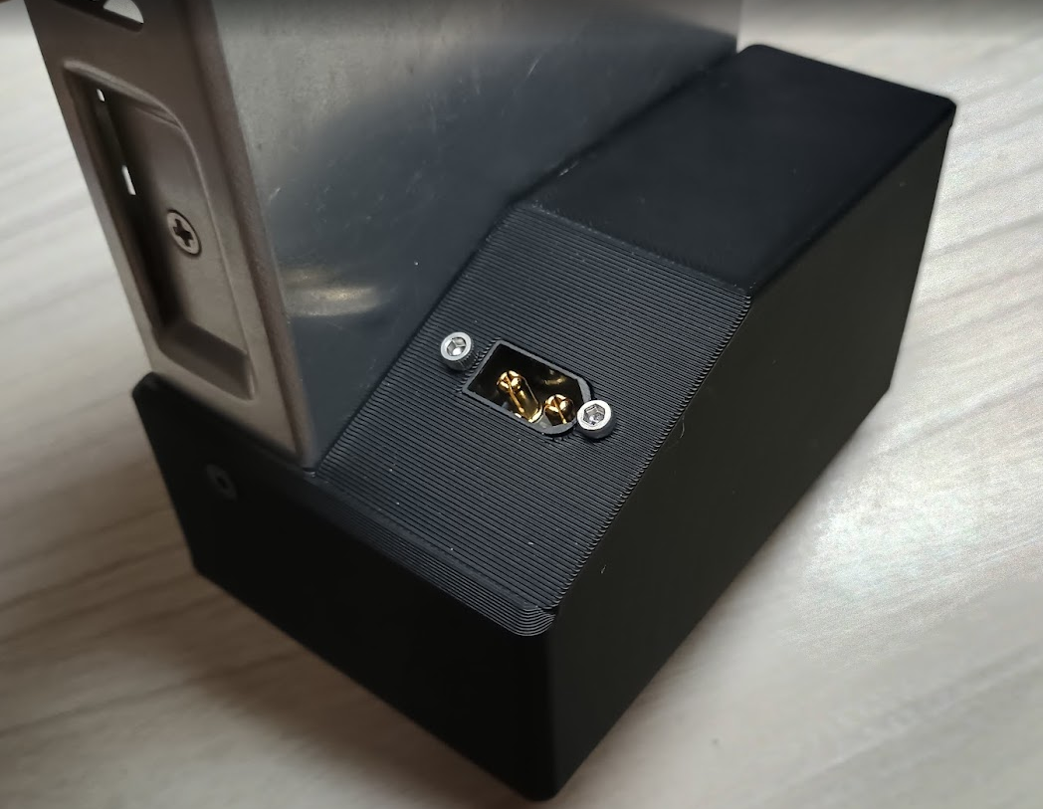
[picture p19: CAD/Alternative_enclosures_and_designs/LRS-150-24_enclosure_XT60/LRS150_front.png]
Front

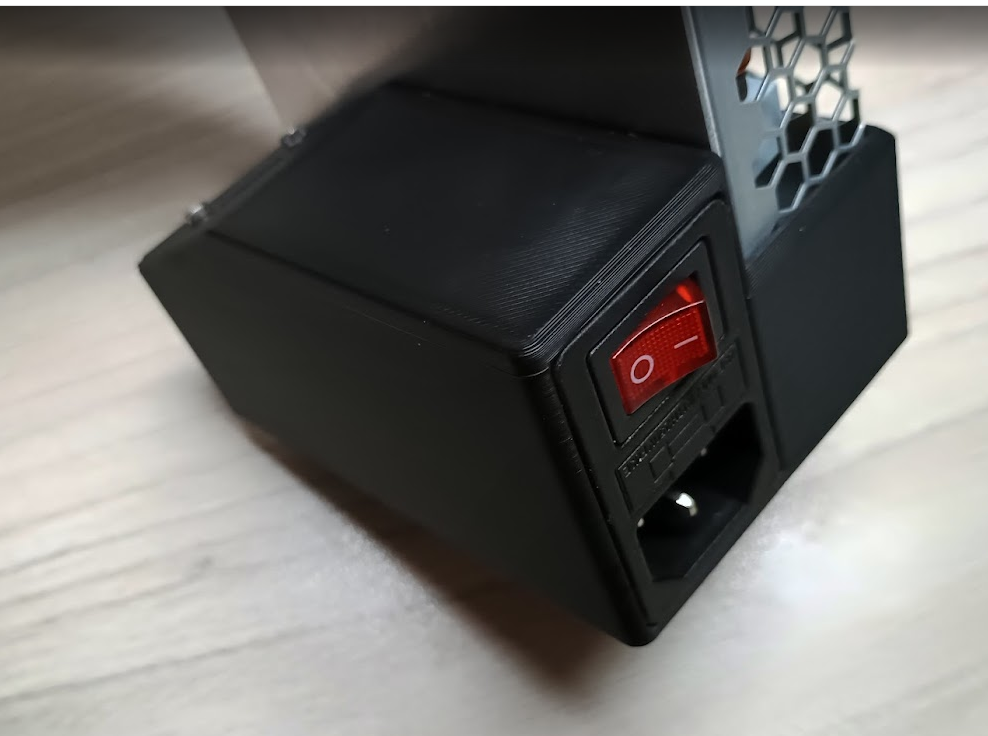
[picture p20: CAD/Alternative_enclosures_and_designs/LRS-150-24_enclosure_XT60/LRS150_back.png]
Back


Designed in FreeCAD.

Modeled around [IEC320 Fused Socket](https://www.sunrom.com/p/ac-power-inlet-socket-with-indicator-switchfuse-holder-snap-mount-iec-60320-c14-2500w-250vx10a) and [XT60(i)M socket](https://www.tme.eu/en/details/xt60ie-m/dc-power-connectors/amass/) to output 24 volts. Requres 1x M3x6 FHCS and 2x M2.5x8 SHCS in addition to sockets (and LRS150 of course). 4x 8mm (diameter) anti-slip pads can be added into slots at the bottom.

Print as is (ABS advised - scale 1% up to adjust for shrinking for ABS), solder wires to XT60 and crimp them on the other side (approx 60mm in length). Insert XT60m and affix it with M2.5x6mm or M2.5x8mm. Wire things up, insert LRS150 into its slot and fix LRS150 with M3x6mm FHCS screw. Glue on pads at the bottom.

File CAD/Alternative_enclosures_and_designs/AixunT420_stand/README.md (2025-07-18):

# Enclosure for Aixun T420 stand

This enclosure is generic enough but was primarily designed for Aixun T420 which I bought at some point.

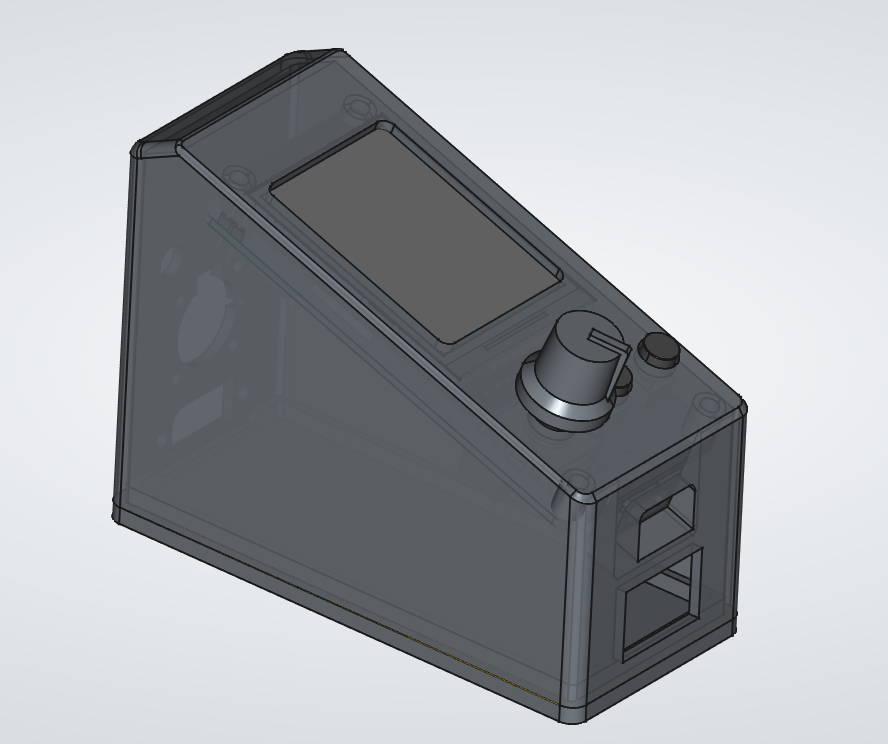
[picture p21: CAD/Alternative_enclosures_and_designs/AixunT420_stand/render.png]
Render


Design was done in FreeCAD. STEP file was generated off original PCB in KiCAD.

## BOM

Links are to sellers where each component was bought. Cheaper options may be available from alternative sources.

| Item | AliExpress Link | Comments |
|---|---|---|
| XT60M | https://www.aliexpress.com/item/1005006996906406.html | Used as power plug |
| C245 replacement socket | https://www.aliexpress.com/item/1005002522875446.html | Found like-hirose connection. Original part was hard to source |
| 2mm banana socket | https://www.aliexpress.com/item/1005008119262551.html | Design was done for M6 thread |
| Aixun T420 Stand | https://www.aliexpress.com/item/1005005982469885.html | Potentially any stand with similar connector will work |
| Aixun Handle | https://www.aliexpress.com/item/1005005081918036.html | Choose option for T420 |
| KCD2 202 6P switch | https://www.aliexpress.com/item/1005008336906735.html | Mounting hole is is 19.2mm x 13mm |
| 8mm anti-slip pads | sourced locally | Mounting pockets are 8mm diamter, 0.6 mm deep |
| M2x3.5x3.0 Heat Insert | https://www.aliexpress.com/item/1005008309060936.html | 4 needed, holes are 3.2mm diameter |
| M2 BHCS | Sourced as part of set | 2x4mm and 2x8 for PCB, 4x8mm and 4 nuts for C245 socket |
| M2.5x8 SHCS | Sourced as part of set | 2 needed to mount XT60M to enclosure |
| 2.8mm Crimp Terminals | https://www.aliexpress.com/item/4000964054489.html | 5 needed |

## Printing Notes

Print in ABS scaling by 1% (i.e. 101% size) to accommodate shrinking . Other materials may work. Can be printed without supports LCD face on the build plate.

## Build Notes

18 AWG has been used for wiring (except stand sense where 22 AWG was used).

Stand doesn't have grounding and banana socket is used to wire stand sense. On Stand side M4x5 has been used to mount wire which plugs into stand sense.

Wiring might be a bit cramped. Solder 2 wires (around 100mm each) to XT60M and crimp them on the other side. These will be used to connect power input from XT60M to rocker switch.

Crimp another pair (approx 100mm each) on one side - they will be used to connect rocker switch to VIN/GND terminals on PCB. Insert rocker switch. Connect rocker switch to pcb.

Cut 50 mm of 22AWG to connect banana socket. Crimp it on one side.
Insert banana socket and affix it to enclosure. Connect crimped wire from step above to PCB.

Cut 50 mm of coloured cable and solder them to C245 connector. Do this outside of enclosure.
Insert C245 Socket. Connect pre-soldered wires to PCB. Carefully insert M2 screws (tweezers recommended) and screw with M2 nuts. Do one at a time. This step is tricky and requires patience.

Insert XT60M (with presoldered and crimped wires) and affix it using M2.5 screws. Connect crimped wires to switch terminals.

Dobule check polarity and check that rocker switch connection is correct.

Attach a length of 22AWG wire and 2mm banana plug to your stand.

Glue in anti-slip pads to the case bottom.

Glue in bottom to the top part.

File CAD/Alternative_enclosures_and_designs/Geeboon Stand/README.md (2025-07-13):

# Geeboon SDC02 Enclosure

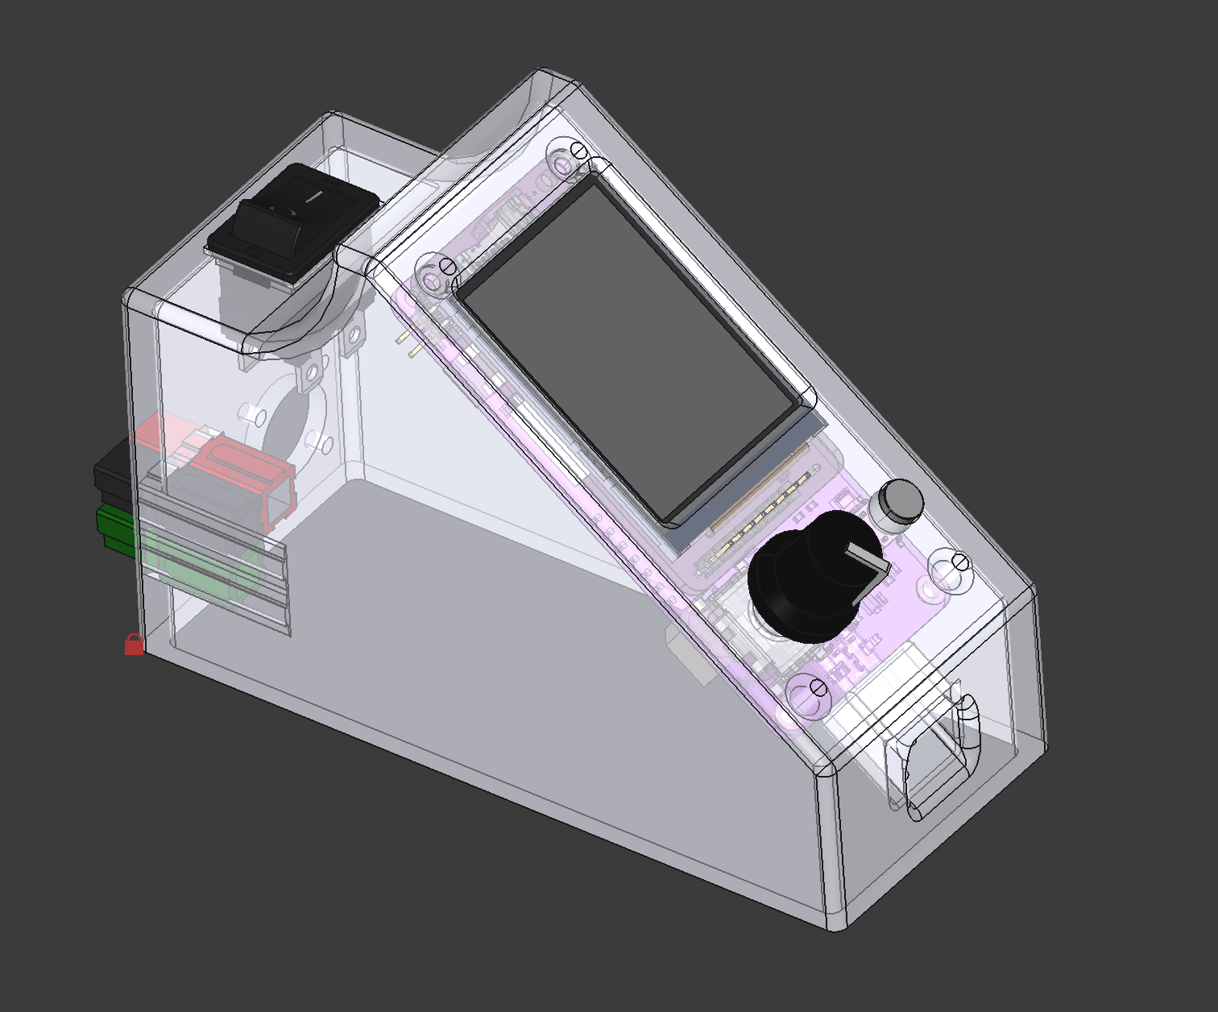
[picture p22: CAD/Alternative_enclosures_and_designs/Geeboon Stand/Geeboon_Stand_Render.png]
Stand_Render


This is an enclosure for AxxSolder which fits the [Geeboon SDC02 handpiece stand](https://www.aliexpress.us/item/3256808635827814.html).

It was [designed in FreeCAD](https://www.freecad.org)

I first fabricated it using an Elegoo Mars 4 DLP resin 3D printer. The Mars 4
DLP has a 50 μm minimum feature size. I don't know how well it'll work if
printed with an FDM 3D printer; fortunately the CAD files and FreeCAD are open
source, and you can modify it to your needs.

I decided a "plain" stand was boring, so I also searched for 3D printable
tabletop diorama terrain, and used my slicer to merge this enclosure with a
wall texture, which I then painted as the Red Rock sandstone in the Colorado
Plateau.

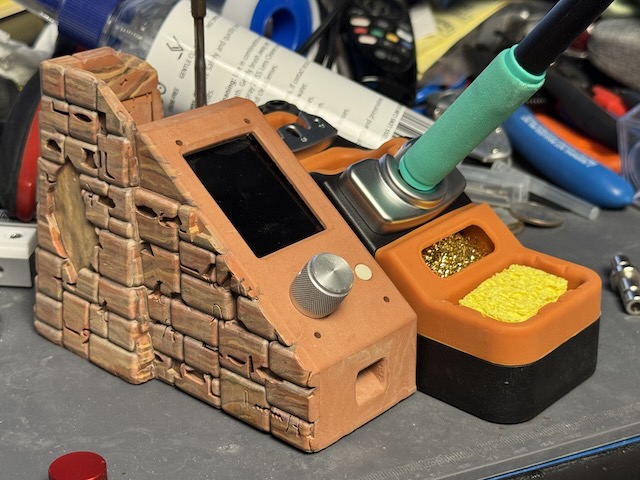
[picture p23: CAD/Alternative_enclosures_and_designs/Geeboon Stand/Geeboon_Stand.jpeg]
Fancy_Stand


I also created a slightly different enclosure for the LRS-150-24, which is able
to accomodate a 14 AWG grounded plug pigtail (as is easily found in a Big Box
Store in North America).

## Hardware Notes:

- This stand uses the same Hirose Connector as the AxxSolder Portable, as the
  Geeboon SDC02 has a plug which connects to the Hirose connector.
- As with the JBC ADS stand, this uses Anderson Power Poles to connect an external power supply
- It's capable of accepting a USB-PD plug in the front of the enclosure.

## Alternative Handpieces:

* The Sugon T-115 handpiece (**without** buttons) needs to be rewired to match the contacts listed in the AxxSolder README. It takes a few minutes.
* The Sugon T-210 and T-245 handpieces (again **without** buttons) are find out of the box.

## Geeboon Stand Rewiring:

The Geeboon Stand doesn't _quite_ follow the standard JBC pinout. 

To open the Geeboon SDC02 stand:
1. Remove the rubber feet. Each rubber foot covers a screw.
2. In the center of the bottom label, there's an indentation. Cut or punch a hole in the label, and the final screw is underneath.

The pinout for the Geeboon Stand (as-sold) is as follows:

AxxSolder Pinout | Geeboon Stand Internal | Geeboon Stand Handpiece Output |
|---|---|---|
1 (Green) | Green | 1
2 (Red) | Clear | 2
3 (Handle_sense_2) | Yellow: Sleep - Metallic contacts for cradle, back-screw for T115 | No Connection
4 (Stand_Sense) | Red: Shutdown for Changing Tips | No Connection
5 (Blue)| White | 5
6 (Handle_Sense_1) | Black | 6

The AxxSolder doesn't have a "Shutdown" pin, and needs to use pin 3 to identify the handpiece. 

Start by desoldering the wire from the "Sleep" pad and the "Shutdown" pads on the PC Board.

We'll fix the handpiece identification by moving the Geeboon's yellow "input" wire so it connects to Pin 3 on the output connector directly.

Next, we need to rewire pin 4 -- the "shut" (shutdown) pad on the PCB -- to connect to the "Sleep" pad on the PCB. This will allow the sleep function on the AxxSolder to work. 

Additionally: The tip changing section has a contact (Geeboon uses it to shutdown the tip when changing tips). AxxSolder doesn't have an equivalent contact, and it makes sense to have the AxxSolder go to sleep when it contacts the tip changer, so I added a jumper wire from the "shut(down)" net to to the "sleep" net on the PC Board.

When done, it should look like the following: 

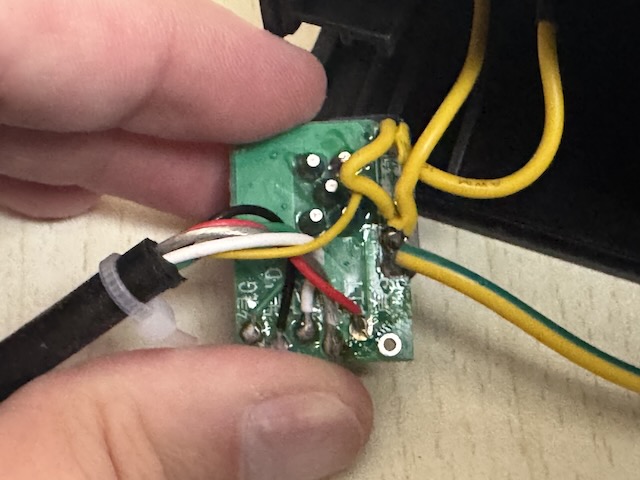
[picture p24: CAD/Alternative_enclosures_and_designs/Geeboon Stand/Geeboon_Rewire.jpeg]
Geeboon Rewired


The pinout should be:

AxxSolder Pinout | Geeboon Stand Internal | Geeboon Stand Handpiece Output |
|---|---|---|
1 (Green) | Green | 1
2 (Red) | Clear | 2
3 (Handle_sense_2) | None | Handle_Sense
4 (Stand_Sense) | Sleep + Shutdown (joined) | No Connection
5 (Blue)| White | 5
6 (Handle_Sense_1) | Black | 6

TODO: Update the LRS-150-24 enclosure to swap which side the wire hump is on.

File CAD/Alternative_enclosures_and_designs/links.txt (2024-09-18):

https://www.printables.com/model/894013-mini-iron-man-soldering-station-for-jbc-handpieces
https://www.printables.com/model/875115-25u-19-inch-rack-front-panel-mount-for-axxsolder-3

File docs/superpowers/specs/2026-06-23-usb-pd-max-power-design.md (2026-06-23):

# USB-PD: negotiate the maximum power the charger can provide

Date: 2026-06-23
Status: Approved
Area: `AxxSolder_firmware` — `power_source.c`, `stusb4500.c/.h`

## Problem

The STUSB4500 exposes only **3 sink PDOs**, and PDO1 is forced to 5 V by spec.
The current firmware advertises a fixed-current ladder:

- PDO3 = 20 V / 5 A
- PDO2 = 15 V / 5 A
- PDO1 = 5 V / 3 A

USB-PD only matches a sink PDO when the source can supply the **requested
current** at that voltage. A 20 V / 3 A (60 W) charger cannot satisfy 20 V/5 A
*or* 15 V/5 A, so negotiation falls all the way to PDO1 and the iron runs at
**5 V**. With only two usable high-voltage slots, a fixed-current ladder cannot
cover every charger's current rating.

A previous dynamic implementation read the source capabilities and rewrote PDO2,
but when the capability poll returned nothing it wrote a **0 V PDO** and
soft-reset again, thrashing the contract and **browning out marginal boards**
(iron powered up, then died). That regression is why the dynamic path was
removed.

## Goal

Request the **highest-power** profile the charger actually advertises, capped at
the STUSB4500's 20 V ceiling — without ever writing a 0 V / empty PDO.

Expected results: 20 V/5 A charger → 100 W, 20 V/3 A → 60 W, 15 V/3 A → 45 W,
dead-comms charger → safe 5 V, DC barrel → unchanged.

## Decisions

- **Selection metric:** highest power (V × I), capped at V ≤ 20 V.
- **Fallback when source caps cannot be read:** hold a guaranteed 5 V/3 A
  contract (USB powered, low power). Never write a 0 V PDO. The iron simply will
  not reach high power until reconnected.

## Design

### `power_source_init()` flow

1. **Connect / init / attach checks** — unchanged. Return `POWER_DC` if the
   STUSB4500 is absent or no sink is attached.
2. **Baseline contract** — write PDO1 = 5 V/3 A, valid count = 1, one
   `stusb_soft_reset()`. Guarantees a safe 5 V rail (MCU stays powered) and
   triggers the source to (re)send its capabilities.
3. **Poll source capabilities** — call `poll_source()` in a retry loop with a
   ~500 ms timeout until it captures the source PDO list (`numPDOs > 0`).
4. **Select & request best (caps read OK):** choose the highest-wattage source
   PDO with V ≤ 20 V, write it into PDO2, valid count = 2, one
   `stusb_soft_reset()`. Then run the existing VBUS-settle loop, confirm an
   explicit RDO contract (`Object_Pos != 0`), prime the bus-voltage filter, and
   derive the heater power limit from **measured VBUS × negotiated current**.
5. **Safe fallback (caps unreadable):** leave the 5 V/3 A baseline in place
   (`POWER_USB`, low power), never write a 0 V PDO, log a warning.

Worst case is two soft-resets (baseline → high power), both to valid non-zero
contracts.

### Driver change (`stusb4500.c` / `.h`)

Add one encapsulated selection function so `power_source.c` never touches the
driver's internal `pdos` global:

```c
/* Scan the last-received source capabilities; return the highest-power
 * fixed PDO at or below max_voltage_mv. false if none / none read. */
bool stusb_find_highest_power_pdo(uint16_t max_voltage_mv,
                                  uint16_t *voltage_mv, uint16_t *current_ma);
```

Reuses the existing wattage math; converts units (source PDO is 50 mV / 10 mA).

Remove the now-redundant `stusb_set_highest_pdo()` (currently unused, lacks the
20 V cap, performs its own delay/reset) to avoid two competing selection paths.

### Unchanged

VBUS settle loop, voltage-filter priming (`sensors_prime_bus_voltage` /
`sensors_get_bus_voltage`), RDO-based power-limit derivation, and
`USB_PD_POWER_REDUCTION_FACTOR`.

## Testing / verification

No host test harness (bare-metal STM32G4). Verification is on-hardware:

- 100 W (20 V/5 A) charger → negotiates 20 V, ~100 W limit shown.
- 60 W (20 V/3 A) charger → negotiates 20 V, ~60 W limit shown.
- ~45 W (15 V/3 A) charger → negotiates 15 V, ~45 W limit shown.
- Marginal / dead-comms charger → stays at 5 V, no brown-out cycling.
- DC barrel input → `POWER_DC`, unchanged behavior.

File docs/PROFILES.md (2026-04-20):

# Tip Profiles

Tip profiles let you save per-tip PID tuning, power limits, and temperature calibration points. Each profile is bound to a handle type and can be set as the active profile for that handle.

---

## Data model

### `TipProfile` (72 bytes)

| Field | Type | Description |
|---|---|---|
| `name` | `char[24]` | Display name |
| `handle_type` | `uint8_t` | `NT115 / T210 / T245 / No_name` |
| `kp / ki / kd` | `float` | PID coefficients |
| `max_i` | `float` | Integrator clamp (±) |
| `power_limit` | `float` | Watts cap; `0` = use the global setting |
| `temp_cal[6]` | `float[6]` | Calibration offsets at 100 / 200 / 300 / 350 / 400 / 450 °C |

### `ProfileStore` (1744 bytes)

Stored in flash as a single block:

```
magic (4) | version (1) | count (1) | active_idx[4] (4) | reserved (6) | TipProfile[24] (1728)
```

- `magic` = `0x54495031` ("TIP1") — used to detect an uninitialised page.
- `count` — number of valid profiles (0–24).
- `active_idx[4]` — one active profile index per handle slot (`0xFF` = none).
  - slot 0 → NT115, slot 1 → T210, slot 2 → T245, slot 3 → No_name.

Up to **24 profiles** total across all handle types (`MAX_PROFILES = 24`).
Total store size: 16 + 24 × 72 = **1744 bytes** — fits in the 2 KB `PROFILES` flash page.

---

## Storage

Profiles are stored in a dedicated flash section (`PROFILES` linker region, 2 KB). The backend is selected at build time via a CMake cache variable:

```cmake
cmake -DSTORAGE_PROFILES=FLASH ..   # default
cmake -DSTORAGE_PROFILES=EEPROM ..
cmake -DSTORAGE_PROFILES=SDCARD ..
```

On first boot (magic mismatch or version change), four built-in default profiles are written — one per handle type.

The flash write driver appends an 8-byte CRC after the payload. The internal write buffer is 2048 bytes, which covers the full `ProfileStore` (1744 bytes data + 8 bytes CRC = 1752 bytes).

---

## Initialisation

```c
tip_profiles_init(const StorageDriver *drv);
```

Called from `main()` after the storage driver is ready. Reads the stored block; falls back to defaults if the block is missing or version-mismatched.

---

## Active profile per handle

Each handle type has one active profile index stored in `active_idx[]`.

```c
tip_profiles_set_active(enum handles h, uint8_t idx);
uint8_t tip_profiles_get_active(enum handles h);   // returns 0xFF if none
```

When a handle is detected:
- `tip_profiles_apply_pid()` — loads `kp / ki / kd / max_i` into the PID controller.
- `tip_profiles_get_power_limit()` — returns the per-profile watt cap.
- `tip_profiles_get_cal(h, cal_index)` — returns the calibration value for a given temperature point (0 = 100 °C … 5 = 450 °C).

If no profile is active for a handle, the functions fall back to the first profile whose `handle_type` matches, then to identity values.

---

## CRUD API

```c
uint8_t     tip_profiles_count(void);
TipProfile *tip_profiles_get(uint8_t index);
StoreResult tip_profiles_add(const TipProfile *p);      // STORE_ERR_FULL if count == MAX_PROFILES
StoreResult tip_profiles_update(uint8_t index, const TipProfile *p);
StoreResult tip_profiles_delete(uint8_t index);
StoreResult tip_profiles_save(void);
```

All writes operate on the in-RAM cache. Call `tip_profiles_save()` to persist to flash.

### Delete behaviour

When the deleted profile is the active one for a handle slot, `tip_profiles_delete` automatically reassigns that slot to the first remaining profile with the same handle type. If no such profile exists the slot is cleared (`0xFF`). Remaining `active_idx` references with higher indices are decremented to stay valid after the array compaction.

---

## Menu

### Profiles menu (`Settings → Profiles`)

Lists all profiles. Each entry shows the profile name; the currently active profile for the attached handle is marked `[A]`. The header shows `[count:max]` (e.g. `[4:24]`) right-aligned.

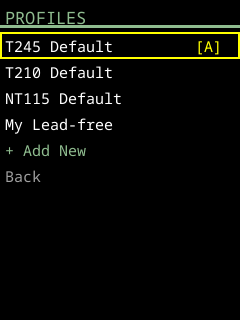
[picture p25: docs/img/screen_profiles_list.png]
Profiles list


| Action | How |
|---|---|
| Open profile editor | Press encoder on a profile |
| Add new profile | Select `+ Add New` (hidden when 24 profiles exist) |
| Return | Select `Back` |

A new profile is pre-filled with T245 defaults and named `Profile N`. All fields can be changed in the editor before saving.

### Profile editor fields

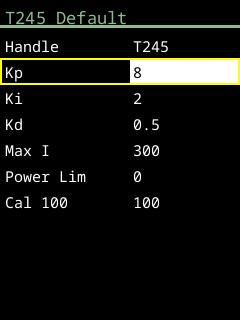
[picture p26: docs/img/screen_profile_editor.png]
Profile editor


| Field | Behaviour |
|---|---|
| Name `[...]` | Press to open the name editor (see below) |
| Handle | Cycles NT115 → T210 → T245 → No_name on press |
| Kp / Ki / Kd / Max I / Power Lim | Encoder increments/decrements; press to confirm |
| Cal 100 … Cal 450 | Same encoder edit |
| `-Set Active-` | Saves edits and sets this profile as active for its handle |
| `-Delete-` | Deletes the profile; active slot is reassigned automatically |
| `Back` | Saves edits, returns to the profile list |

### Name editor

A full-screen character-by-character editor. The current character is shown inverted; a scrolling 12-character window (using the standard menu font) keeps the cursor visible for names up to 23 characters long. `[...]` indicators appear at the left or right edge when the name extends beyond the visible window.

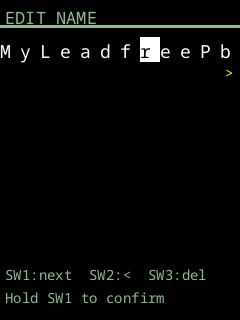
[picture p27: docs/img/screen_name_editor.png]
Name editor


Character set: `(space) A–Z a–z 0–9 - _ .`

| Control | Action |
|---|---|
| Encoder | Cycle through character set at cursor position |
| SW_1 (short) | Accept character, advance cursor right |
| SW_2 (short) | Move cursor left |
| SW_3 (short) | Delete character at cursor (shift tail left) |
| SW_1 (long) | Confirm name and exit |

Trailing spaces are trimmed on exit. An empty result is replaced with `"Profile"`.

### Quick-select popup

When a new handle is detected and `Profile on tip chg` is enabled in Settings, a popup lists all profiles matching the new handle type:

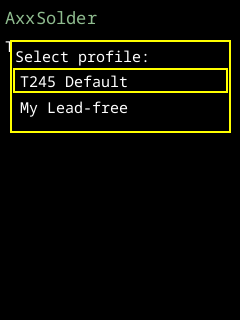
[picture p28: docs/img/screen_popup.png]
Quick-select popup


- **1 match** — selected automatically, no popup shown.
- **2+ matches** — popup appears; encoder chooses, press confirms. SW_2 cancels (keeps current active profile).
- **0 matches** — popup skipped.

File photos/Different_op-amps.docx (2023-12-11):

Current – OPA2333 – 12V (2.5 mOhm)

Current – OPA2333 – 12V (5 mOhm)

Current – OPA2333 – 24V (2.5 mOhm)

Current - New Op-Amp – 12V (5 mOhm)

Current - New Op-Amp – 24V (5 mOhm)

Current – OPA2333 – 24V (5 mOhm)

PWM signal

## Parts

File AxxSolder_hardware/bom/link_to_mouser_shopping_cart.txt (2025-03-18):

https://eu.mouser.com/ProjectManager/ProjectDetail.aspx?AccessID=aea6f0f97b

Note that this is components for the PCB + caps for tactile switches and rotary encoder. 

You might need to purchase components other than these, eg. power connectors, connectors for the soldering iron and screws. See BOM for a complete list.

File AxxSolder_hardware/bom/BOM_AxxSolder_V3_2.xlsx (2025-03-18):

AxxSolder V3.2 | Prises as per 2024-02-20 | Parts for AxxSolder Portable
 |  | Parts for AxxSolder Station
References | Value | Footprint | Manufacturer | MPN | Mouser Part Number | Quantity | Price per part | Price total | Price total inc tax
C3, C9, C14, C15, C16, C17, C18, C21, C22, C23, C24, C25, C26, C27, C28, C29, C33 | 100n | C_0603_1608Metric | KEMET | C0603C104J5RACTU | 80-C0603C104J5R | 17 | 0.04 € | 0.73 € | 0.91 €
C1, C2, C5, C7, C8, C10, C11, C12, C13, C19, C20, C30, C31, C32, C34, C35 | 10u | C_0603_1608Metric | Murata Electronics | GRM188R6YA106MA73J | 81-GRM188R6YA106MA3J | 16 | 0.18 € | 2.83 € | 3.54 €
C4, C6 | 1n | C_0603_1608Metric | KEMET | C0603C102K3GAC | 80-C0603C102K3G | 2 | 0.09 € | 0.19 € | 0.23 €
C37 | 220u | CAPAE830X1050N | KEMET | EEV227M035A9MAA | 80-EEV227M035A9MAA | 1 | 0.61 € | 0.61 € | 0.77 €
R4, R6, R18, R19, R20, R22, R23, R25, R26, R27, R28, R29, R30, R31, R32, R33, R35, R36, R37, R38 | 4k7 | R_0603_1608Metric | Panasonic | ERJ-3RBD4701V | 667-ERJ-3RBD4701V | 20 | 0.12 € | 2.50 € | 3.12 €
R11, R12, R15, R21, R24 | 22k | R_0603_1608Metric | Panasonic | ERJ-UP3J223V | 667-ERJ-UP3J223V | 5 | 0.14 € | 0.70 € | 0.88 €
R1, R5, R14, R17 | 1k5 | R_0603_1608Metric | Panasonic | ERJ-H3ED1501V | 667-ERJ-H3ED1501V | 4 | 0.21 € | 0.86 € | 1.07 €
R2, R7, R8, R9 | 360k | R_0603_1608Metric | Panasonic | ERJ-3RED3603V | 667-ERJ-3RED3603V | 4 | 0.12 € | 0.48 € | 0.60 €
R3, R10 | 220k | R_0603_1608Metric | Panasonic | ERJ-3RED2203V | 667-ERJ-3RED2203V | 2 | 0.12 € | 0.24 € | 0.30 €
R13, R16, R34, R43, R46, R47, R48 | 100 | R_0603_1608Metric | Panasonic | ERJ-P03F1000V | 667-ERJ-P03F1000V | 7 | 0.31 € | 2.15 € | 2.69 €
R42 | 5m | RESC6432X89N | Vishay | WSLP25125L000FEA | 71-WSLP25125L000FEA | 1 | 0.75 € | 0.75 € | 0.94 €
R44 | 1M | R_0805_2012Metric | Panasonic | ERJ-6GEYJ105V | 667-ERJ-6GEYJ105V | 1 | 0.09 € | 0.09 € | 0.12 €
R45 | 100m | R_0805_2012Metric | Panasonic | ERJ-6DSFR10V | 667-ERJ-6DSFR10V | 1 | 0.41 € | 0.41 € | 0.51 €
R49,R50 | 10 | R_0603_1608Metric | Panasonic | ERJ-3RED10R0V | 667-ERJ-3RED10R0V | 2 | 0.12 € | 0.24 € | 0.30 €
L1 | SRP7028CC-150M | INDPM7366X300N | Bourns | SRP7028CC-150M | 652-SRP7028CC-150M | 1 | 0.75 € | 0.75 € | 0.94 €
D5, D6, D7, D8 | BAT54S | SOT95P230X110-3N | Diotec Semiconductor | BAT54S | 637-BAT54S | 4 | 0.11 € | 0.45 € | 0.56 €
D1, D2 | BAV199WQ-7 | SOT65P210X110-3N | Diodes Incorporated | BAV199WQ-7 | 621-BAV199WQ-7 | 2 | 0.20 € | 0.39 € | 0.49 €
D3, D4 | SMF4L24AT1G | SODFL3619X98N | LITTELFUSE | SMF4L24AT1G | 576-SMF4L24AT1G | 2 | 0.40 € | 0.80 € | 1.00 €
D9, D10 | PMEG6020ER | PMEG6020ER115 | Nexperia | PMEG6020ER,115 | 771-PMEG6020ER-115 | 2 | 0.37 € | 0.74 € | 0.93 €
TFT1 | Adafruit_240x320_TFT | Adafruit_240x320_TFT | Adafruit | 4311 | 485-4311 | 1 | 18.55 € | 18.55 € | 23.19 €
U2 | RIC11-31S15D7-GSMT | RIC11-31S15D7-GSMT | CUI Devices (https://eu.mouser.com/manufacturer/cui-devices/) | RIC11-31S15D7-GSMT | 179-RIC1131S15D7GSMT | 1 | 2.37 € | 2.37 € | 2.96 €
U3 | BSC014N04LS | BSC014N04LS | Infineon Technologies | BSC014N04LSATMA1 | 726-BSC014N04LSATMA1 | 1 | 1.60 € | 1.60 € | 2.00 €
F1 | 0154007.DR | 0154100DR | LITTELFUSE | 0154007.DR | 576-0154007.DR | 1 | 2.55 € | 2.55 € | 3.19 €
F2 | SF-2410FP100W-2 | SF2410FP100W2 | Bourns | SF-2410FP100W-2 | 652-SF-2410FP100W-2 | 1 | 0.72 € | 0.72 € | 0.91 €
S2, S3 | ADTSM644RVTR | ADTSM644RVTR | Apem | ADTSM644RVTR | 642-ADTSM644RVTR | 2 | 0.55 € | 1.10 € | 1.37 €
FB1 | BLM18HE601SN1D | R_0603_1608Metric | Murata Electronics | BLM18HE601SN1D | 81-BLM18HE601SN1D | 1 | 0.18 € | 0.18 € | 0.22 €
IC1 | TLV76733DRVR | SON65P200X200X80-7N | Texas Instruments | TLV76733DRVR | 595-TLV76733DRVR | 1 | 0.38 € | 0.38 € | 0.48 €
IC2 | OPA2387DSGT | SON50P200X200X80-9N | Texas Instruments | OPA2387DSGT | 595-OPA2387DSGT | 1 | 4.40 € | 4.40 € | 5.50 €
IC3 | LMR54406DBVR | SOT95P280X145-6N | Texas Instruments | LMR54406DBVR | 595-LMR54406DBVR | 1 | 0.97 € | 0.97 € | 1.21 €
IC4 | STM32G431CBT6 | QFP50P900X900X160-48N | STMicroelectronics | STM32G431CBT6 | 511-STM32G431CBT6 | 1 | 5.65 € | 5.65 € | 7.06 €
IC5 | TPD4E1U06DBVR | SOT95P280X145-6N | Texas Instruments | TPD4E1U06DBVR | 595-TPD4E1U06DBVR | 1 | 0.33 € | 0.33 € | 0.41 €
IC6 | STUSB4500QTR | QFN50P400X400X100-25N-D | STMicroelectronics | STUSB4500QTR | 511-STUSB4500QTR | 1 | 2.52 € | 2.52 € | 3.15 €
IC7 | MAX16171ATA_VY+T | SON50P300X200X80-9N | Analog Devices | MAX16171ATA/VY+T | 700-MAX16171ATA/VY+T | 1 | 2.64 € | 2.64 € | 3.30 €
IC8 | LTC4440AHMS8E | SOP65P490X110-9N | Analog Devices | LTC4440AHMS8E-5#PBF | 584-C4440AHMS8E-5PBF | 1 | 5.22 € | 5.22 € | 6.52 €
IC9 | INA281A5QDBVRQ1 | SOT95P280X145-5N | Texas Instruments | INA281A5QDBVRQ1 | 595-INA281A5QDBVRQ1 | 1 | 2.74 € | 2.74 € | 3.43 €
LS1 | CMI-9653S-SMT-TR | CMI9653SSMTTR | CUI Devices | CMI-9653S-SMT-TR | 490-CMI-9653S-SMT-TR | 1 | 2.71 € | 2.71 € | 3.39 €
Q1 | STL9P3LLH6 | STL9P3LLH6 | STMicroelectronics | STL9P3LLH6 | 511-STL9P3LLH6 | 1 | 0.99 € | 0.99 € | 1.24 €
Q2 | STL10N3LLH5 | STL10N3LLH5 | STMicroelectronics | STL10N3LLH5 | 511-STL10N3LLH5 | 1 | 0.97 € | 0.97 € | 1.21 €
Q3 | 2N7002NXAKR | SOT95P230X110-3N | Nexperia | 2N7002NXAKR | 771-2N7002NXAKR | 1 | 0.13 € | 0.13 € | 0.16 €
J5, J6 | TSW-102-07-T-S | TSW-102-XX-YY-S | SAMTEC | TSW-102-07-T-S | 200-TSW10207TS | 2 | 0.09 € | 0.19 € | 0.23 €
J1 | USB4110-GF-A | USB4110GFA | GCT | USB4110-GF-A | 640-USB4110-GF-A | 1 | 1.26 € | 1.26 € | 1.57 €
J2 | 691243110009 | 691243110009 | Wurth Elektronik | 691243110009 | 710-691243110009 | 1 | 3.70 € | 3.70 € | 4.62 €
J4 | 61300611821 | RHDR6W97P0X254_1X6_1574X250X865P | Wurth Elektronik | 61300611821 | 710-61300611821 | 1 | 0.34 € | 0.34 € | 0.42 €
J7 | TSW-108-07-T-S | TSW-108-XX-YY-S | SAMTEC | TSW-108-07-T-S | 200-TSW10807TS | 1 | 0.59 € | 0.59 € | 0.74 €
SUM Components |  |  |  |  |  |  |  |  | €98.40
Hardware |  |  |  |  |  |  | Price inc tax
PCB (Development was done with PCBs from PCBWay, 2 layer, Immersion gold(ENIG) (1U")) + stencil |  |  |  | 1 | €12.62 | €12.62 | €15.77
Connector for JBC stand (binder 99-0624-00-07) |  |  |  | 1 | €5.11 | €5.11 | €6.39
Connector for soldering iron (HIROSE(HRS) RPC1-12RB-6P(71)) |  |  |  | 1 | €6.11 | €6.11 | €7.64
Power connector (Anderson PP15) BLACK | https://eu.mouser.com/ProductDetail/Anderson-Power-Products/1395G1?qs=yoCgdRjoRtHp7gSzhBTdjg%3D%3D |  |  | 2 | €0.95 | €1.90 | €2.37
Power connector (Anderson PP15) RED | https://eu.mouser.com/ProductDetail/Anderson-Power-Products/1395?qs=yoCgdRjoRtFIuHO4SWqMZA%3D%3D |  |  | 2 | €1.37 | €2.74 | €3.43
Power connector (Anderson PP15) GREEN | https://eu.mouser.com/ProductDetail/Anderson-Power-Products/1395G3?qs=yoCgdRjoRtE1BBke6hIRPA%3D%3D |  |  | 2 | €0.84 | €1.68 | €2.10
Rotary encoder knob | https://eu.mouser.com/ProductDetail/Davies-Molding/1101?qs=byeeYqUIh0PVJzrDf6EcyQ%3D%3D |  |  | 1 | €0.88 | €0.88 | €1.09
Tactile button caps | https://eu.mouser.com/ProductDetail/Omron-Electronics/B32-2000?qs=ZP3UR5XsUocRMlsFF2GtPw%3D%3D |  |  | 2 | €0.86 | €1.71 | €2.14
Rocker Switch | https://eu.mouser.com/ProductDetail/Wurth-Elektronik/471001264143?qs=YCa%2FAAYMW03bZZ%252BoQThfXw%3D%3D |  |  | 1 | €3.45 | €3.45 | €4.31
3D printed housing |  |  |  | 1 | €5.00 | €5.00 | €6.25
Screws - M2.5x12mm countersunk | To mount the PCB to enclosure |  |  | 4 | €0.10 | €0.40 | €0.50
Screws - M2.5x20mm | To mount PP15 connectors |  |  | 1 | €0.10 | €0.10 | €0.12
Screws - M4x8mm | For enclosure to JBS stand |  |  | 1 | €0.20 | €0.40 | €0.50
Screws - M2.5x6mm | To mount HIROSE(HRS) RPC1-12RB-6P(71) |  |  | 4 | €0.10 | €0.40 | €0.50
Screws - M2x8mm + nuts | For the aluminium rest |  |  | 2 | €0.10 | €0.20 | €0.25
Aluminium plate 15x10x2 mm | For the aluminium rest (not mandatory) |  |  | 1 | €1.00 | €1.00 | €1.25
SUM Hardware (portable) |  |  |  |  |  |  | €43.42
JBC stand
JBS Stand | https://www.jbctools.com/ad-sf-stand-for-t210-t245-handles-product-2018.html | https://eleshop.eu/jbc-ad-sf-stand-for-t245-and-t210.html |  | 1 | €171.40 | €171.40 | 214.25
Non-genuine Stand
Non-brand Stand | https://www.aliexpress.com/i/1005005756505193.html |  |  | 1 | €17.00 | €17.00 | €21.25
JBC T210 handle piece
T210 handle piece | https://www.jbctools.com/t210-a-precision-handle-product-48.html |  |  | 1 | €66.34 | €66.34 | €82.93
c210-008 tip | https://www.jbctools.com/c210008-chisel-cartridge-13-x-06-product-183.html |  |  | 1 | €38.34 | €38.34 | €47.93
Non-genuine JBC T210 handle piece
Aixun T210 handle piece | https://www.aliexpress.com/item/1005005081918036.html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 |  |  | 1 | €18.00 | €18.00 | €22.50
Aixun c210-008 tip | https://www.aliexpress.com/item/1005005879501637.html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 |  |  | 1 | €17.00 | €17.00 | €21.25

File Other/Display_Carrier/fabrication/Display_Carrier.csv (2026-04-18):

Reference | Value | Footprint | Manufacturer_Part_Number | Qty
C1 | 10u | Capacitor_SMD:C_0805_2012Metric | EMK212BB7106KG-T | 1
R1 | 10k | Resistor_SMD:R_0805_2012Metric | CR0805-FX-1002ELF | 1
R2 | 10 | Resistor_SMD:R_0805_2012Metric | CR0805-FX-10R0ELF | 1

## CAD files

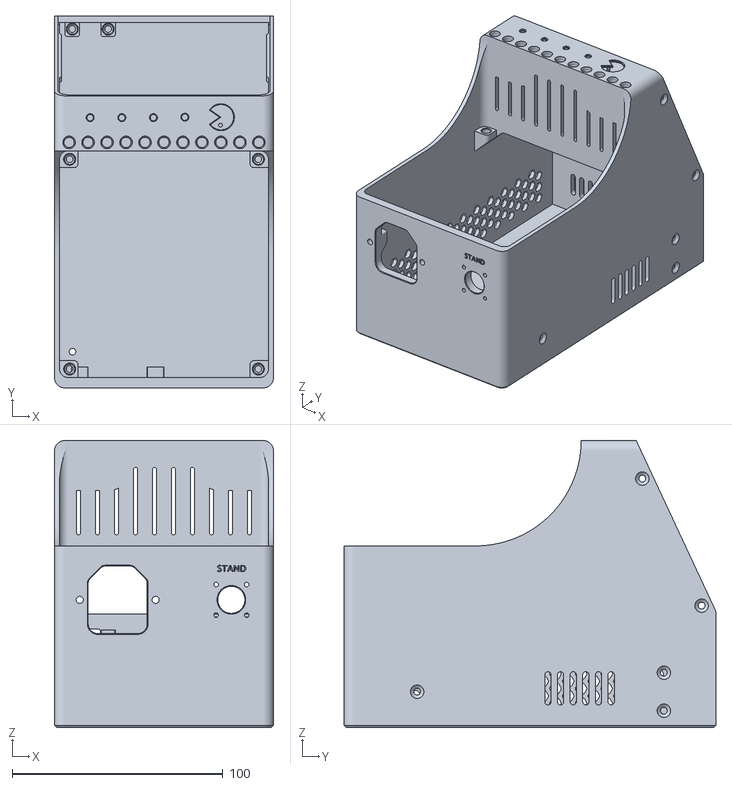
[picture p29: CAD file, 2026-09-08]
CAD/Alternative_enclosures_and_designs/AxxSolder-SDC02-Stand/STLs/main_body.stl
103.9 x 176.4 x 136.1

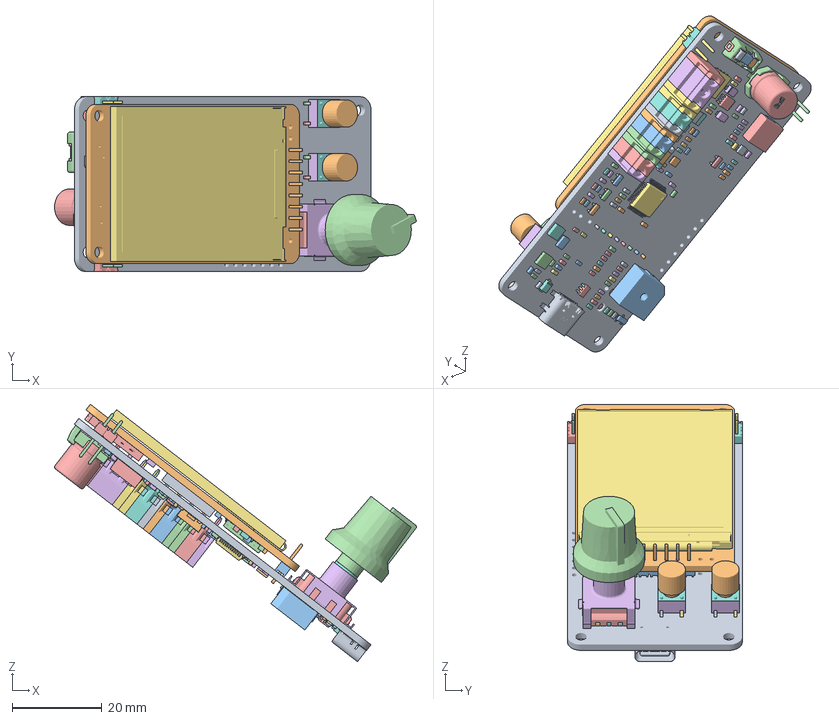
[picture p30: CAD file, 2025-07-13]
CAD/Alternative_enclosures_and_designs/Geeboon Stand/Geeboon_Stand-AssemblyAxxSolder.3mf
80.8 x 39.1 x 57.5 mm

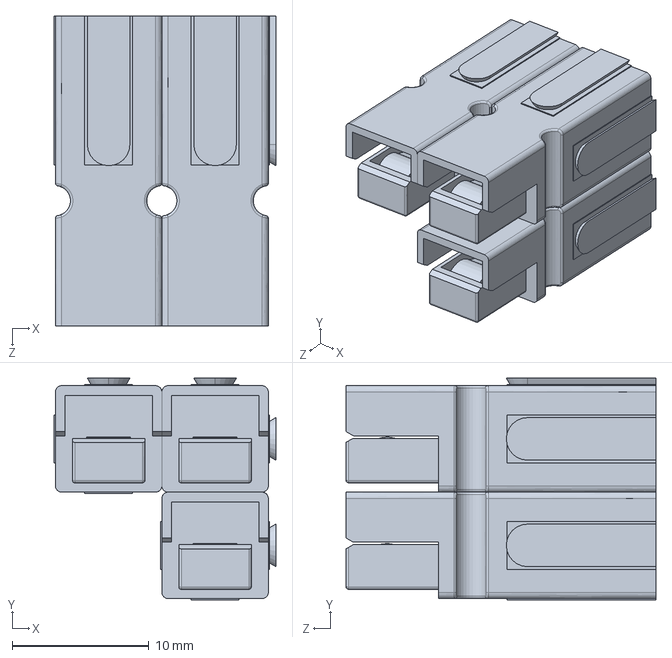
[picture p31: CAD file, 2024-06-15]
CAD/AxxSolder_JBC-ADS_stand/Anderson_PowerPole.SLDASM
16.2 x 16.2 x 22.7 mm
powerpole 15-45A housing.step x 3

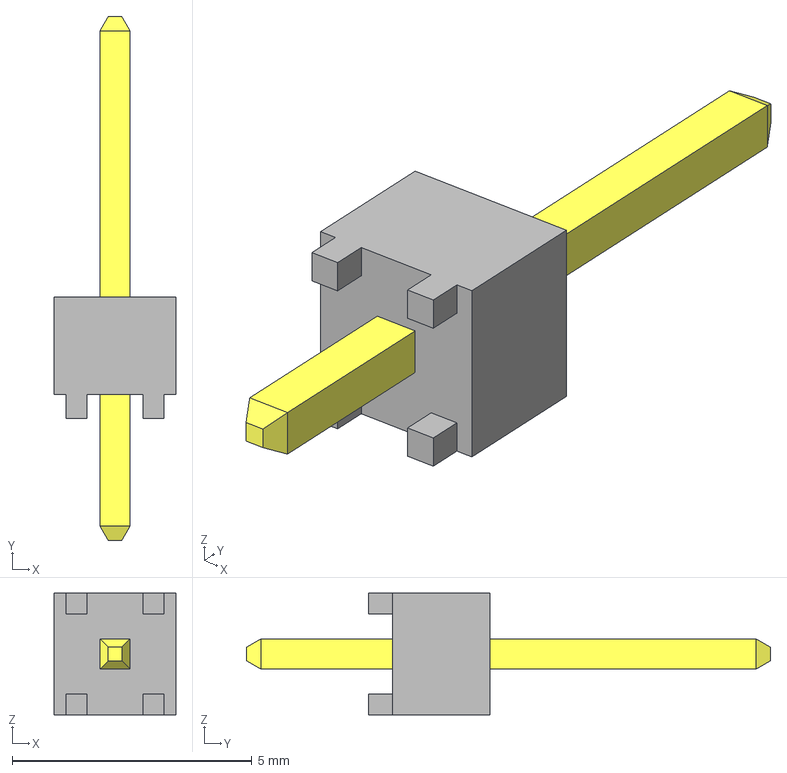
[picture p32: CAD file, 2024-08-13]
AxxSolder_hardware/3rd-parties-libraries/3D-models/TSW-101-07-T-S.stp
2.54 x 10.9 x 2.54 mm
TSW-101-07-L-S_body
T-1S6-07-TSW-1-07-1-S

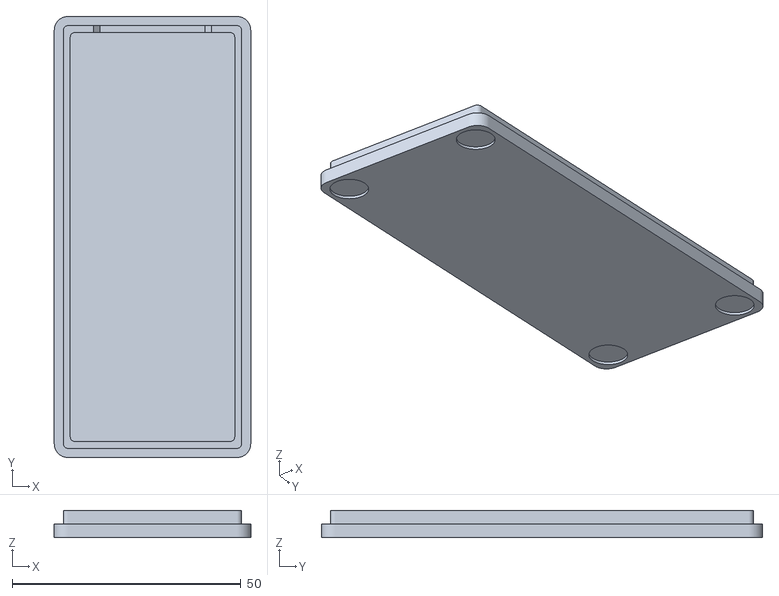
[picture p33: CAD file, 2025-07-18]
CAD/Alternative_enclosures_and_designs/AixunT420_stand/axxsolder_bottom.stl
43.0 x 96.5 x 6.00

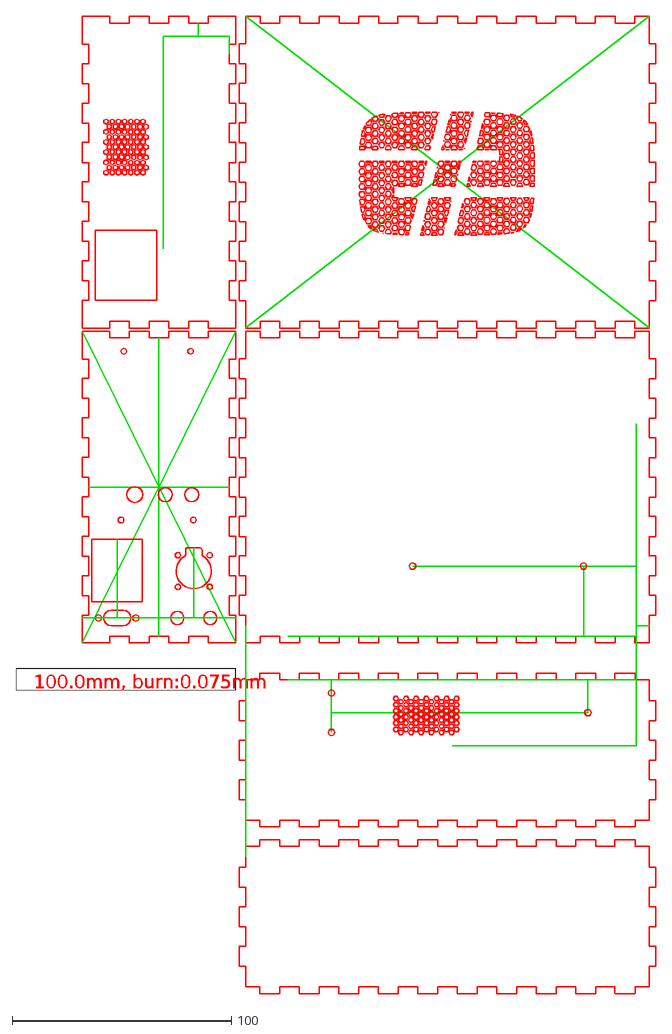
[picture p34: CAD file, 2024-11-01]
CAD/Alternative_enclosures_and_designs/AxxSolder-LaborStation/axxsolder-laborstation.dxf
100.0mm, burn:0.075mm

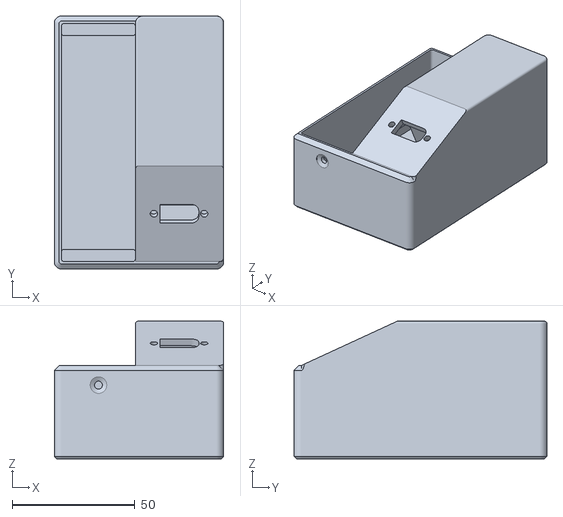
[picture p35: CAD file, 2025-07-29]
CAD/Alternative_enclosures_and_designs/LRS-150-24_enclosure_XT60/lrs150_stand-StandV1.stl
69.0 x 103.0 x 56.0

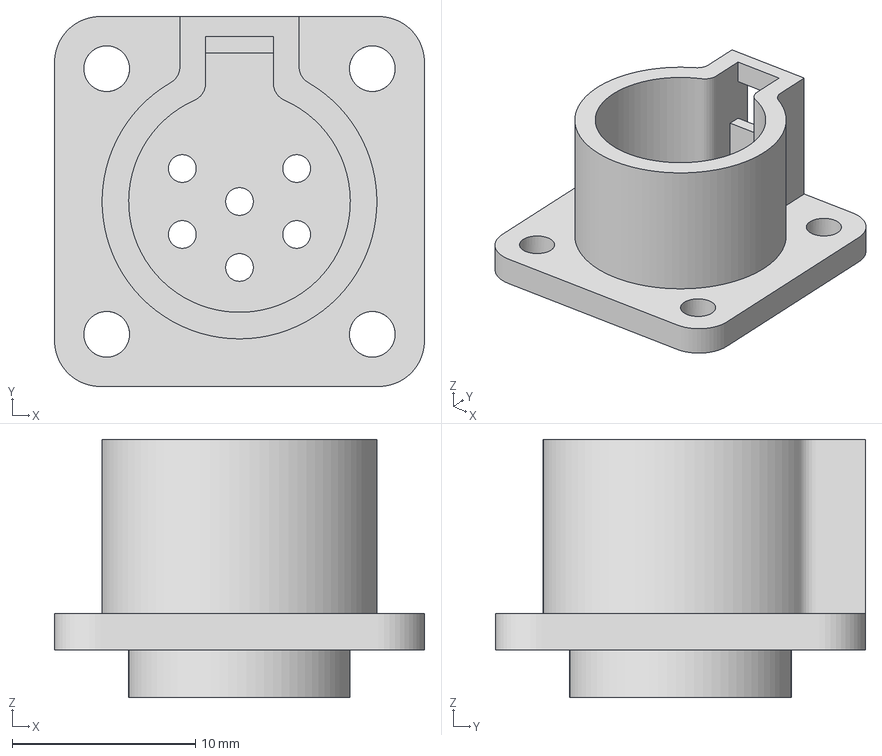
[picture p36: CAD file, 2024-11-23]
CAD/Alternative_enclosures_and_designs/RPC1-12RB-6P_3D_print/RPC1-12RB-6P.3mf
20.2 x 20.2 x 14.1 mm

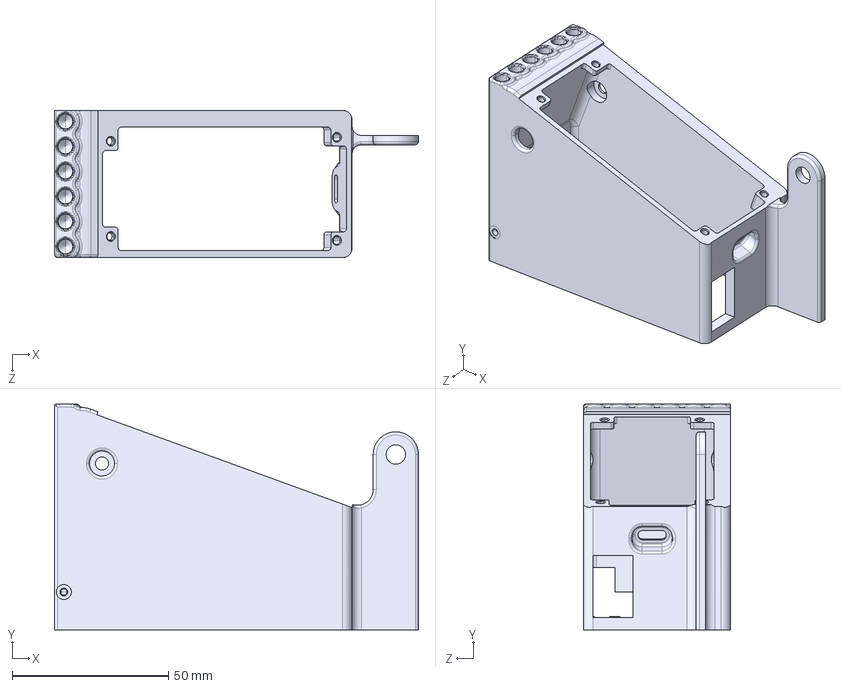
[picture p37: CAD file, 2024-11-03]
CAD/AxxSolder_JBC-ADS_stand/Encolsure_JBC-AD-SF_SEPARATED_TOP_bottom.STEP
116.5 x 72.2 x 47.1 mm

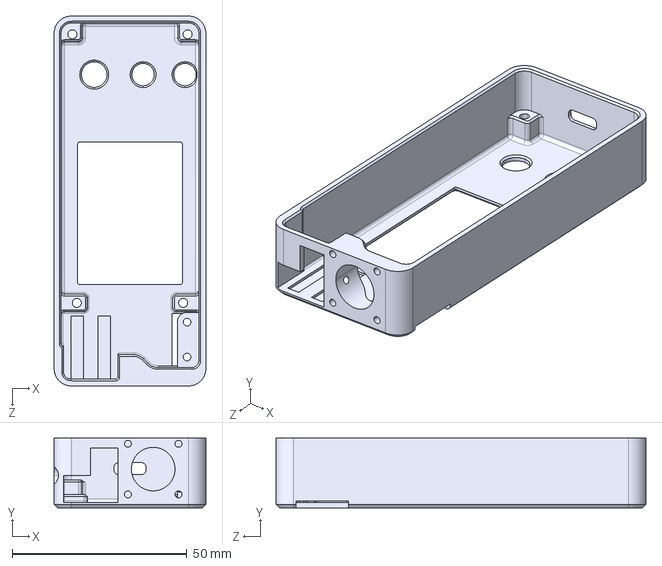
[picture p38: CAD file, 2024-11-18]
CAD/AxxSolder_Portable/AxxSolder_Encolsure_Portable_Top_Earth_Stand.STEP
43.5 x 20.0 x 106.0 mm

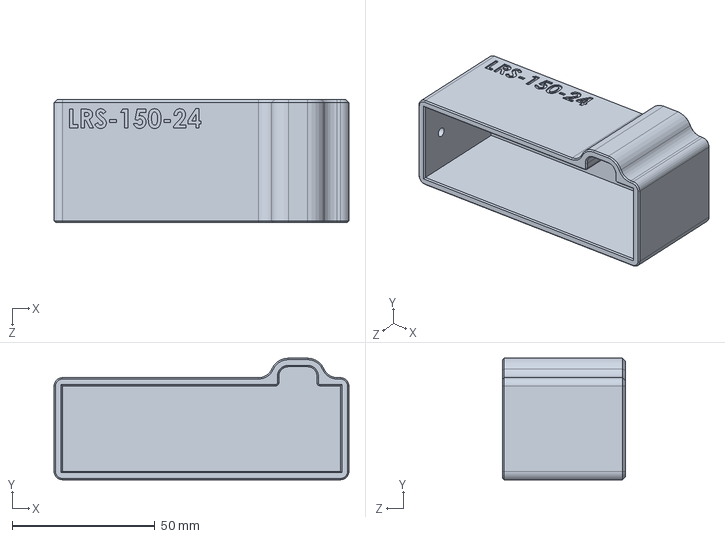
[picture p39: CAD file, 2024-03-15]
CAD/LRS-150-24_enclosure/LRS-150-24_case.SLDPRT
103.5 x 42.7 x 43.0 mm

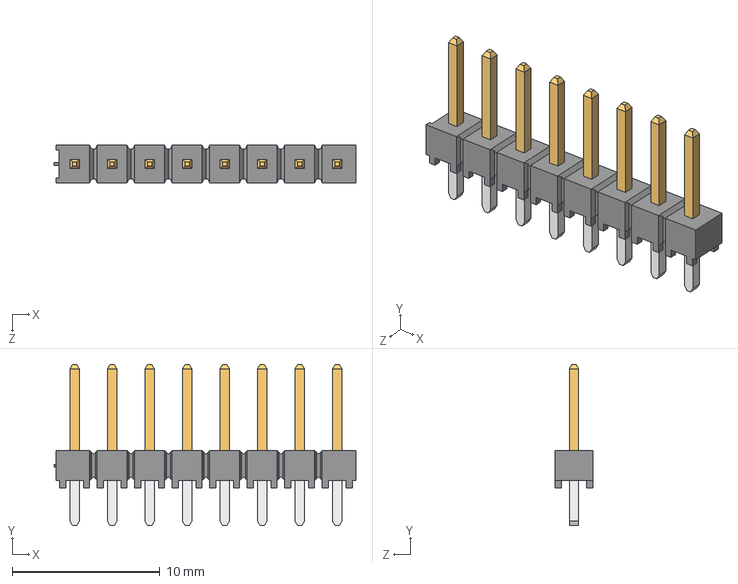
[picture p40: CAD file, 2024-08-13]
AxxSolder_hardware/3rd-parties-libraries/3D-models/TSW-108-07-T-S.stp
20.4 x 10.9 x 2.54 mm
T-1S6-07-TSW-1-07-8-S
TSW-108-07-F-S_body

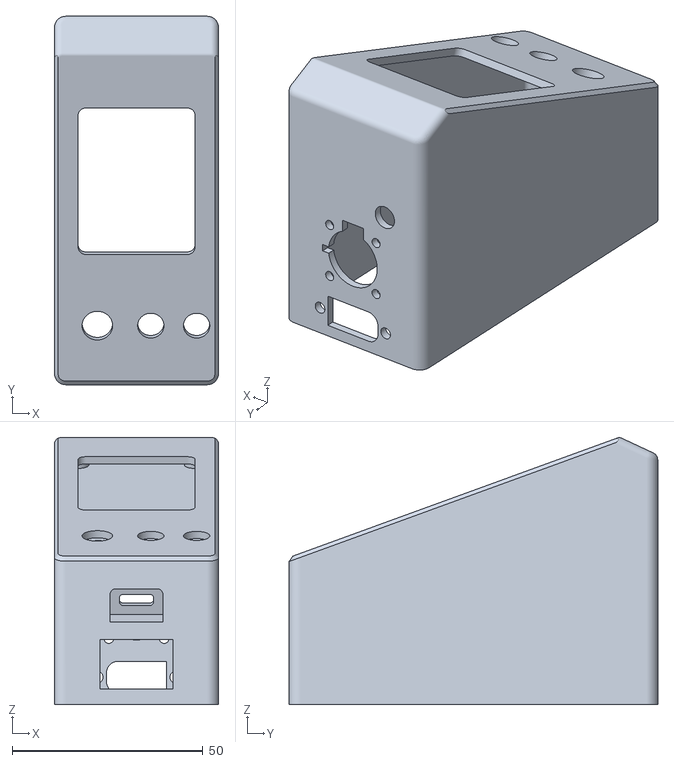
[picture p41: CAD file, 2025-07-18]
CAD/Alternative_enclosures_and_designs/AixunT420_stand/axxsolder_top.stl
43.0 x 96.5 x 69.9

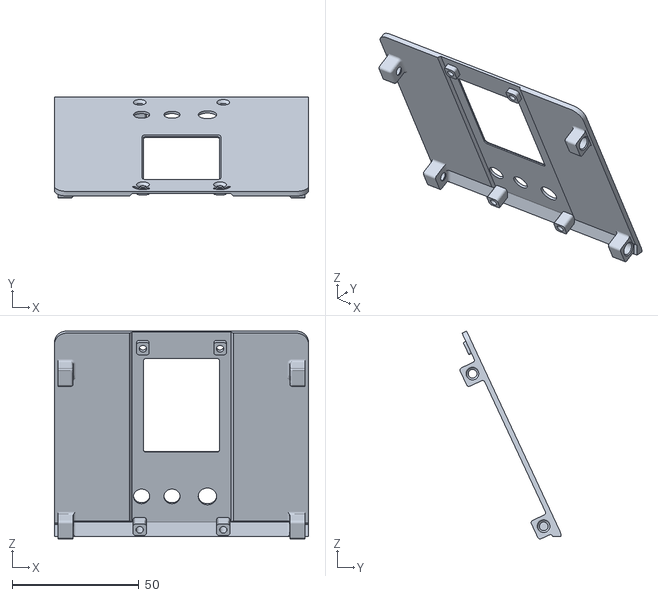
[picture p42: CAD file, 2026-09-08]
CAD/Alternative_enclosures_and_designs/AxxSolder-SDC02-Stand/STLs/faceplate.stl
100.3 x 39.9 x 82.1

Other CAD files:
CAD/AxxSolder_Portable/Anderson_PowerPole.SLDASM
CAD/Alternative_enclosures_and_designs/Geeboon Stand/Geeboon_Stand-0.3.3mf
CAD/Alternative_enclosures_and_designs/LRS-150-24_enclosure_XT60/lrs150_stand.FCStd
CAD/AxxSolder_JBC-ADS_stand/Encolsure_JBC-ADS.SLDPRT
AxxSolder_hardware/3rd-parties-libraries/3D-models/0154007.DRTL.stp
AxxSolder_hardware/3rd-parties-libraries/3D-models/0476001.MRSN.stp
AxxSolder_hardware/3rd-parties-libraries/3D-models/2N7002NXAKR.stp
AxxSolder_hardware/3rd-parties-libraries/3D-models/61300611821.stp
AxxSolder_hardware/3rd-parties-libraries/3D-models/691243110008.stp
AxxSolder_hardware/3rd-parties-libraries/3D-models/691243110009.stp
AxxSolder_hardware/3rd-parties-libraries/3D-models/ADTSM6.STEP
AxxSolder_hardware/3rd-parties-libraries/3D-models/ADTSM6.stp
AxxSolder_hardware/3rd-parties-libraries/3D-models/BAT54S,215.stp
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

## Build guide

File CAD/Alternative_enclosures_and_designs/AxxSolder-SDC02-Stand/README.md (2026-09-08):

# Axxsolder SDC02 Stand

<table>
  <tr>
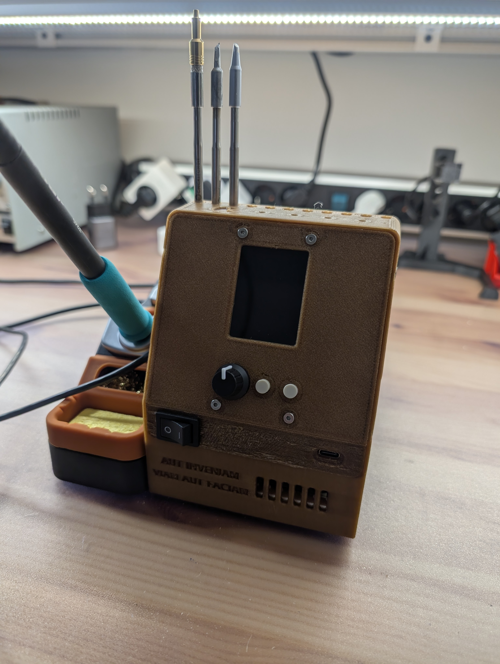
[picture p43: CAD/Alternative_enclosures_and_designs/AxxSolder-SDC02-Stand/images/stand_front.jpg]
Axxsolder Stand Front
    <td></td>
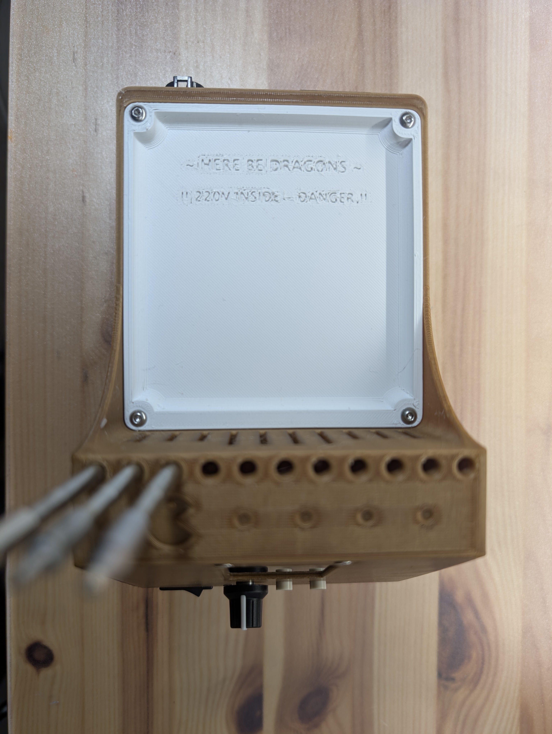
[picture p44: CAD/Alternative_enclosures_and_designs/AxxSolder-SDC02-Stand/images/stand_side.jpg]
Axxsolder Stand Side
    <td></td>
  </tr>
</table>

## Description

This is an enclosure for the [Axxsolder](https://github.com/AxxAxx/AxxSolder/tree/main) soldering iron (v3.5.2) which works with the [Geeboon SDC02](https://aliexpress.com/item/1005008822142566.html) stand.

In order to minimise the amount of clutter and cables, the enclosure integrates not only the Axxsolder electronics but also a MeanWell LRS-150-24 power supply.

The stand includes a handy tray to store soldering wicks or soldering wire, as well as a place on top to store any soldering tips that are not in use.

> **⚠️ Warning:** This project requires you to work with 230V power. **A mistake can potentially create a fire hazard at best or be life-threatening at worst.** If you do not know what you are doing, then please seek the support from a knowledgeable person or do not attempt to do this at all.

## AxxSolder

Axel has done an amazing job putting together an open-source, reasonably priced, high-performance soldering iron that is compatible with the JBC cartridge ecosystem.

Pleasesupport the creator of the AxxSolder by purchasing an assembled PCB from his website, [https://www.5dimensions.se/](https://www.5dimensions.se/). 

## 3D Printed Parts

The STL and STEP files can be found in this repository. All parts can be printed without supports, just make sure that your 3D printer has enough cooling to print the long bridge on the base of the stand. Most printers do.

The sample pictures were printed on a Voron/DoomCube 2.4 with the A4T toolhead.

### Suggested Print Settings

- **Material:** PLA (have not tested with others, but ABS/ASA is likely prone to significant warping due to the length of the base)
- **Brim:** on the main body, only if you have warping issues (recommended for ASA/ABS)
- **Perimeters:** 3 or 4
- **Layer height:** 0.2 - 0.3 mm
- **Infill:** 20-30%
- **Top/bottom layers:** 3-5

Note that the design in the pictures is from the prototype version, where the rocker switch was incorporated in the faceplate. As this was very hard to print with good quality (you can see the blistering on the sample pictures), and was tricky to assemble, I have modified the stand to have the rocker switch on the base plate (current version 1.0).

## Tools Required

The following tools are required to build this stand:

- Soldering iron + soldering consumables
- M3 heat insert tip (preferred, but you can use most soldering iron tips)
- Hex keys (size 1.5, 2, 2.5)
- Wire stripper
- Ferrule crimping tool (optional)
- Insulated terminal crimping tool

## Bill of Materials

| Item | Quantity  | Link | Comment |
| :--- | :--- | :--- | :--- |
| Hirose Connector | 1 | [AliExpress](https://aliexpress.com/item/1005005894421782.html) | |
| IEC Socket with fuse | 1 | [Mouser](https://eu.mouser.com/ProductDetail/Qualtek/719W-00-04?qs=jRuttqqUwMRju8%2Fk0Jvsog%3D%3D) | Qualtek 719W-00-04 or equivalent |
| LRS-150-24 | 1 | [Mouser](https://eu.mouser.com/ProductDetail/MEAN-WELL/LRS-150-24?qs=vDxCgdWo2h%252Bym5KOpEI%252Bpw%3D%3D) | |
| Axxsolder PCB | 1 | [GitHub](https://github.com/AxxAxx/AxxSolder?tab=readme-ov-file) | |
| Rocker switch | 1 | [Mouser](https://eu.mouser.com/ProductDetail/710-471001264143) | Wurth 471001264143 |
| USB-C breakout board (optional) | 1 | [Mouser](https://eu.mouser.com/ProductDetail/SparkFun/BOB-15100?qs=0lSvoLzn4L%2Fxowego0yb1A%3D%3D) | Optional, if you want to use USB-C |
| M3 x 6 mm CSK screws | 4 | | Faceplate to base |
| M3 x 6 mm CSK screws | 3 | | Base to power supply |
| M3 x 6 SCHS/SBHS | 2 | | Base to USB-C breakout board |
| M3 x 12 mm CSK/SBHS | 4 | | Tray to base |
| M3 x 12 mm CSK/SBHS | 2 | | IEC plug to base |
| M2.5 x 12 mm CSK screws | 4 | | Faceplate to Axxsolder PCB |
| M2.5 x 8 mm SCHS | 4 | | Base to Hirose connector |
| M3 x 5 x 4 heatset inserts | 10 | [CNC Kitchen](https://cnckitchen.store/products/made-for-voron-gewindeeinsatz-threaded-insert-m3x5x4-100-stk-pcs) | |
| M2.5 hex nuts | 4 | | Faceplate to Axxsolder PCB |
| 22 or 24AWG wire | as needed | | For the 24V and signal wiring |
| 16 or 18 AWG wire | as needed | | For the 230V wiring |
| Quick connect insulated terminals (for 16 or 18AWG wire) | 5 | | For 230V wiring |
| Spade insulated terminals (for all wire gauges) | 6 | | For power supply wiring (230V and 24V) |
| Ferrules for AWG22 or 24 wires (optional) | 9 | | For 24V and signal wiring connection to Axxsolder terminal block |
| Low-profile right-angle USB cable (optional) | 1 | [Amazon](https://www.amazon.nl/dp/B08HWKVHMK) | To connect Axxsolder USB to USB breakout board |
| 90 Degree USB-C adapter (optional) | 1 | [Amazon](https://www.amazon.nl/dp/B0CNGFZ1JD) | To connect Axxsolder USB to USB breakout board. Only necessary if you cannot find a low-profile right-angle cable with less than 13mm thickness. |

**Abbreviations:**

- **SBHS** = Socket Button Head Screw
- **SCHS** = Socket Cap Head Screw
- **CSK** = Counter Sunk Screw

## Preparing the SDC02 Stand

The SDC02 stand needs to be rewired, as in its as-sold configuration it does not support the Axxsolder's sleep features, as it doesn't really follow the same pinout as the more expensive JBC stand.

The first step is to disassemble the stand. This can be done by removing the four rubber feet and unscrewing the 4 underneath screws, plus the screw that is below the label at the bottom of the stand (the label needs to be pierced with the screwdriver).

Once the stand is open, expose the small PCB that we will need to re-wire.

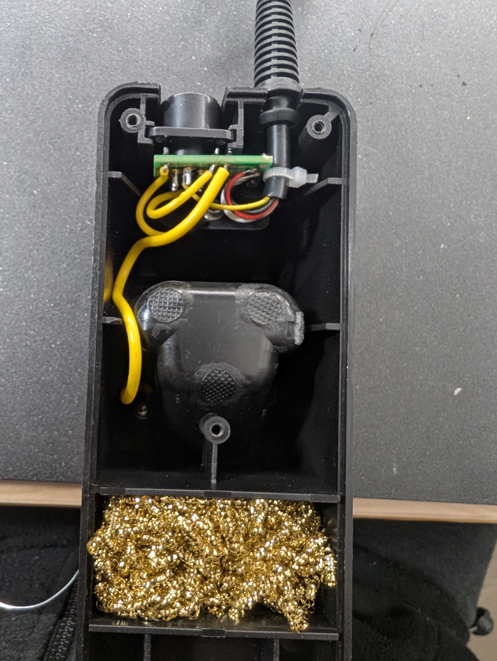
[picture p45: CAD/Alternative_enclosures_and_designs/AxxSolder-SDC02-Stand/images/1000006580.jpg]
SDC02 PCB


### Original Pinout (As-Sold)

[Thanks to ttelford for figuring this out](https://github.com/AxxAxx/AxxSolder/tree/main/CAD/Alternative_enclosures_and_designs/Geeboon%20Stand)

| AxxSolder Pinout | SDC02 Stand | SDC02 Stand Handpiece Output |
| :--- | :--- | :--- |
| 1 (Green) | Green | 1 |
| 2 (Red) | Clear | 2 |
| 3 (Handle_sense_2) | Yellow ("sleep") | n/a |
| 4 (Stand_Sense) | Red ("shutdown") | n/a |
| 5 (Blue) | White | 5 |
| 6 (Handle_Sense_1) | Black | 6 |

### Modifications

Make the following modifications:

1. Desolder the yellow wire from the PCB pad and solder it directly to pin 3 on the Hirose connector.
   - This fixes the handpiece identification.
2. Shunt the "shutdown" and "sleep" nets by soldering a metallic wire between the pad with the red wire and the pad which previously had the yellow wire.
   - Since the Axxsolder does not support shutdown, this modification makes it so that when the tip contacts the tip changer part of the stand, the Axxsolder goes into sleep. This modification is optional if you do not want the sleep on tip change function.

The final result should look like the pictures below:

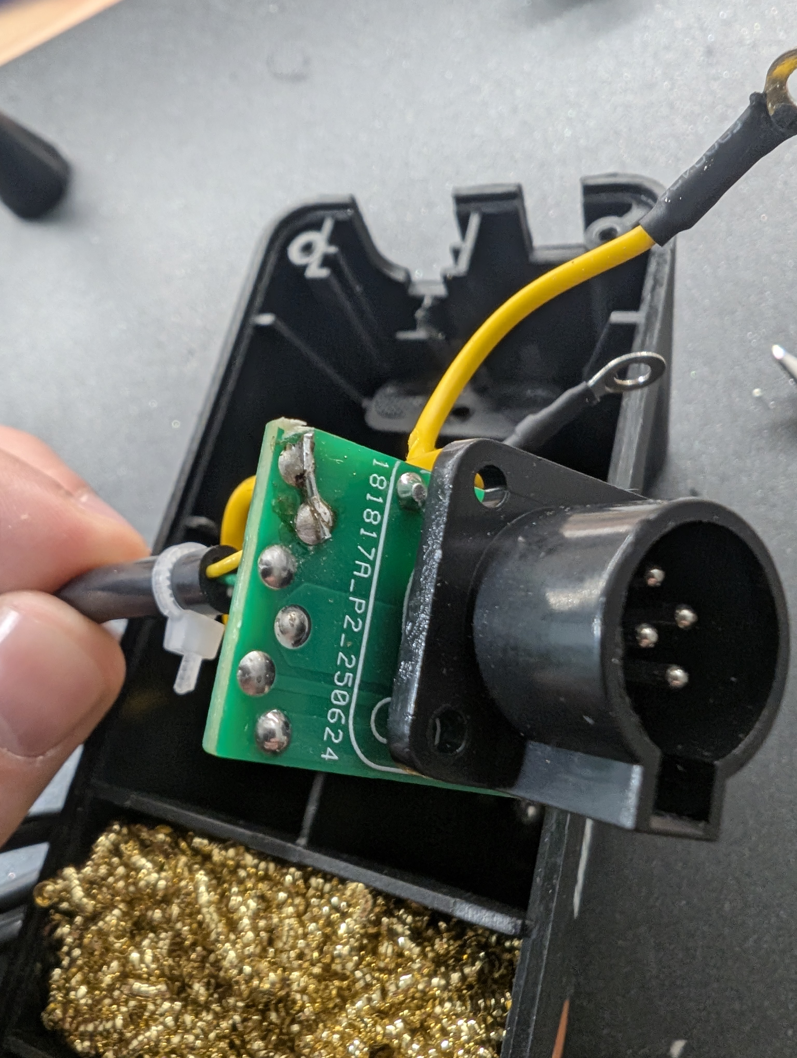
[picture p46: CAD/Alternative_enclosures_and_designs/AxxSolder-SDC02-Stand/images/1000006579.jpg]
Modified PCB 1

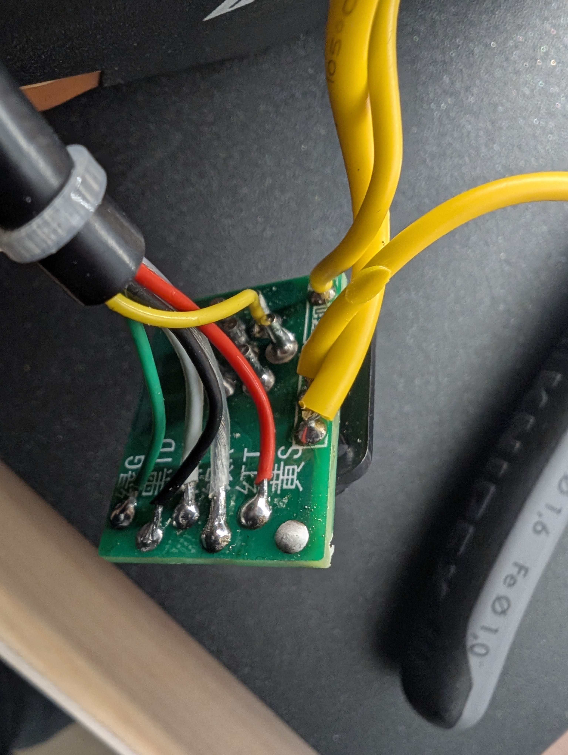
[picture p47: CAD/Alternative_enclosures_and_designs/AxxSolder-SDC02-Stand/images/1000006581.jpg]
Modified PCB 2


### Final Pinout

| AxxSolder Pinout | SDC02 Stand | SDC02 Stand Handpiece Output |
| :--- | :--- | :--- |
| 1 (Green) | Green | 1 |
| 2 (Red) | Clear | 2 |
| 3 (Handle_sense_2) | None | Handle_Sense (pin 3) |
| 4 (Stand_Sense) | Sleep + Shutdown (joined) | 4 |
| 5 (Blue) | White | 5 |
| 6 (Handle_Sense_1) | Black | 6 |

Once done, close the SDC02 stand and we can move on to the assembly of the 3D printed stand.

## Preparing the Base

**Before installing the different components**, it's necessary to prepare the base by inserting all the M3 heatset inserts.

Using a soldering iron at 190°C, insert the 10 heatset inserts into the different locations in the stand (shown below).

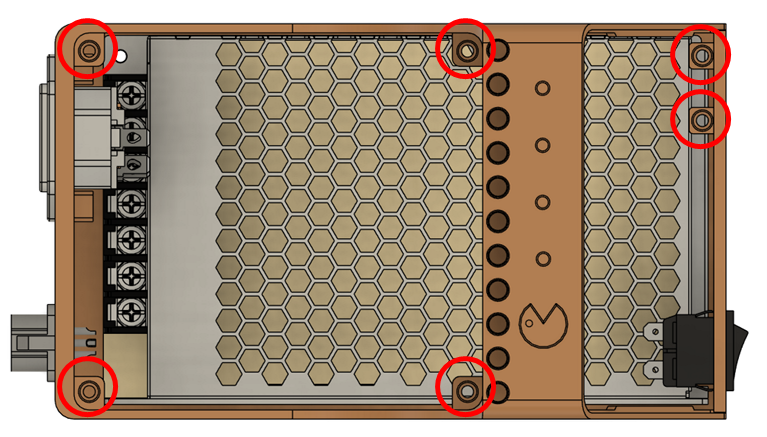
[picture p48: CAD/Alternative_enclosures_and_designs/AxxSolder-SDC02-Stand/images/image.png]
Base heatset locations 1

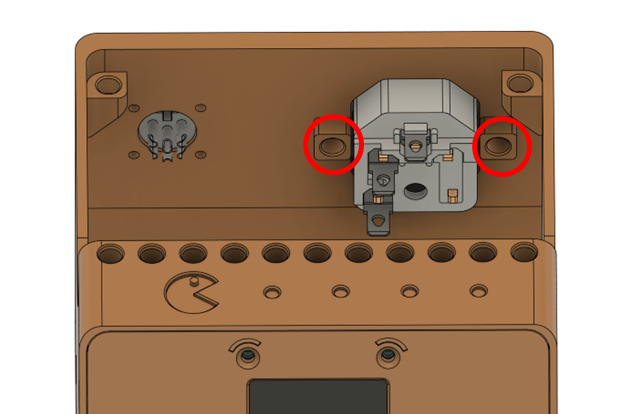
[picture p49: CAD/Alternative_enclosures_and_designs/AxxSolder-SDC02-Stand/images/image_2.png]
Base heatset locations 2

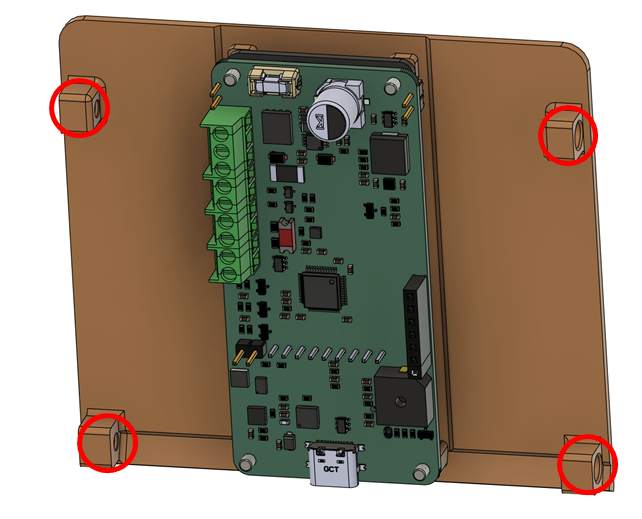
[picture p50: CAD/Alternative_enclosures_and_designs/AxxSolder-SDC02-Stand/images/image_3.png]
Base heatset locations 3


## Wiring Diagram

The wiring of the stand is shown in the diagram below.

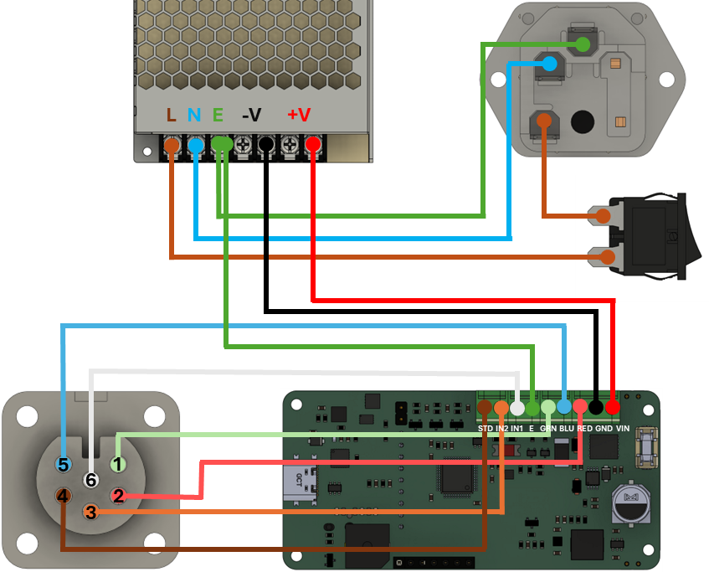
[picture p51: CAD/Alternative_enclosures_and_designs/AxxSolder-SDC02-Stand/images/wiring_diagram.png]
Wiring Diagram


### Important Notes

- It is recommended to use ferrules to connect the wires to the Axxsolder terminal blocks.
- It is mandatory to use proper insulated terminals for the 230V wiring! Never clamp just the wire to the PSU or to the IEC plug/rocker switch, and do not attempt to solder to the plug/switch unless you know exactly what you are doing. Any mistakes can result in injury or fire.
- Make sure all 230V connections are properly secured before switching anything on.
- Earth connection should be provided to the Axxsolder, but it is optional.

## Installing the 24V PSU

Connect all the necessary harness to the PSU terminals, and then slide the PSU in through the back opening of the stand.

### PSU Terminal Connections

| PSU Terminal | Wire | Color (recommended) |
| :--- | :--- | :--- |
| V+ | 24V to AxxSolder | Red |
| V- | GND to AxxSolder | Black |
| Earth | Earth to AxxSolder + Earth to IEC plug | Green and Green/Yellow |
| L | Line to Rocker Switch | Brown |
| N | Neutral to IEC Plug | Blue |

Make sure to verify that the connections are properly done and will not come out easily. **Any loose cables could create a safety hazard!**

Secure the PSU with **3 M3 x 6 mm CSK screws**, installed from the left side of the stand.

## Installing the Hirose Connector

The wiring of the Hirose connector should be done following the pinout of the SDC02 stand. See the picture below for the expected result.

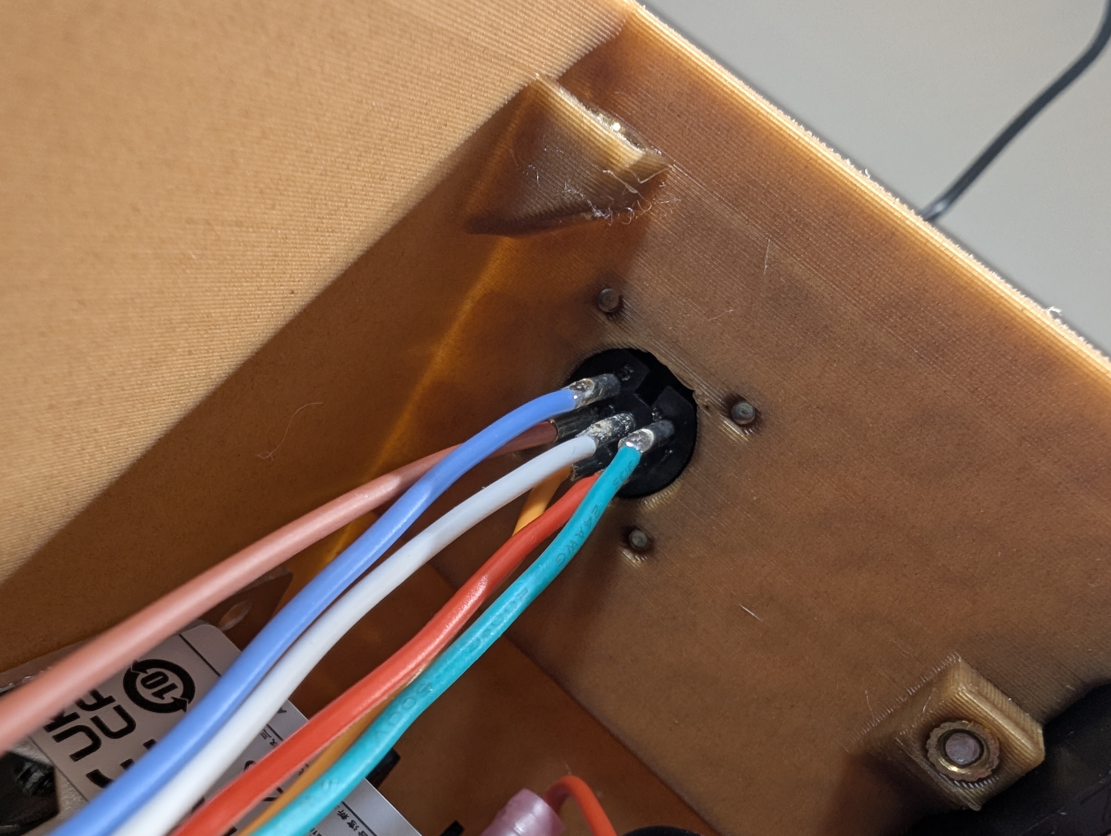
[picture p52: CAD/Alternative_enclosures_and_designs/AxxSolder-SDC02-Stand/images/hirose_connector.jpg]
Hirose Connector Wiring


| Hirose Connector Pin Number | Axxsolder Pin  | Wire Color (in picture above) |
| :--- | :--- | :--- |
| 1 | Green | Green |
| 2 | Red | Red |
| 3 | Handle_Sense_2 | Orange |
| 4 | Stand_Sense | Brown |
| 5 | Blue | Blue |
| 6 | Handle_Sense_1 | White |

Once the wires have been soldered, install the connector on the stand using **4 M2.5 x 8 mm SCHS**. As the screws are threading into plastic, be careful not to overtighten them.

If you do overtighten them, simply install longer screws and use M2.5 nuts.

## Installing the IEC Plug

Slide in the IEC plug and secure it with **2 M3 x 12 mm CSK/SBHS screws** to the stand.

Then, wire the IEC plug as shown below.

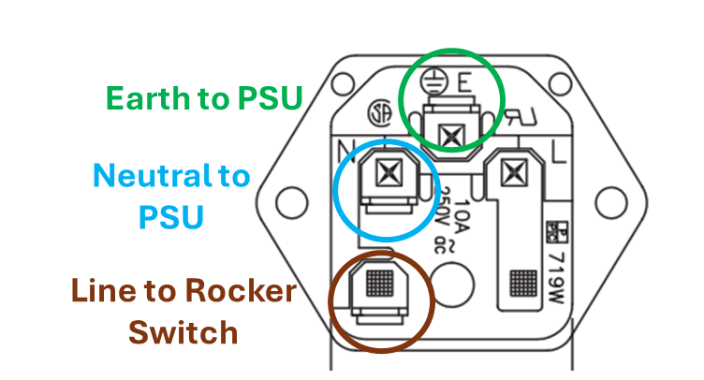
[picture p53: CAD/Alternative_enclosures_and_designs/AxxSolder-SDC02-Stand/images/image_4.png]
IEC Plug Wiring Diagram

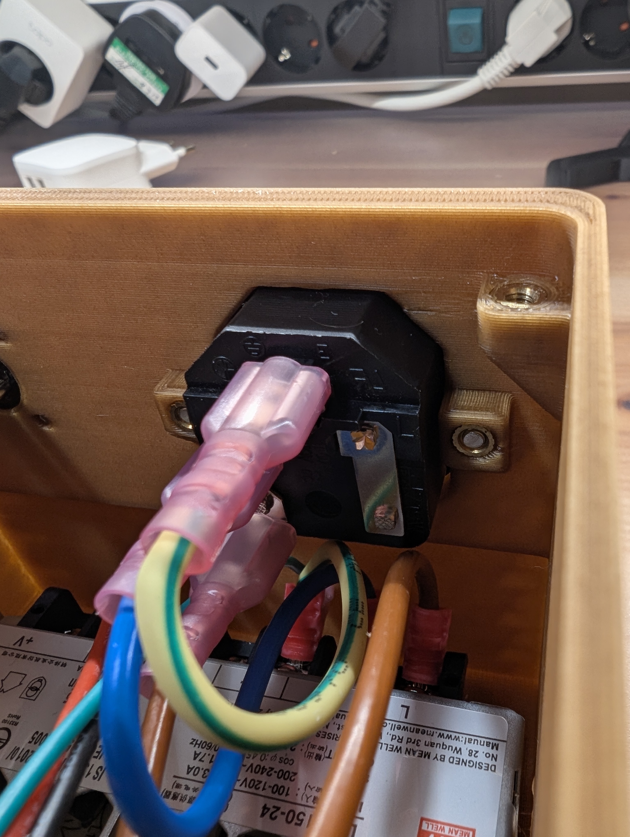
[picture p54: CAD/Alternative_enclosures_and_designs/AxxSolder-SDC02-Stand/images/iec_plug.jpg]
IEC Plug Installed


Make sure to verify that the connections are properly done and will not come out easily. **Any loose cables could create a safety hazard!**

At this point the assembly should look roughly like the pictures below.

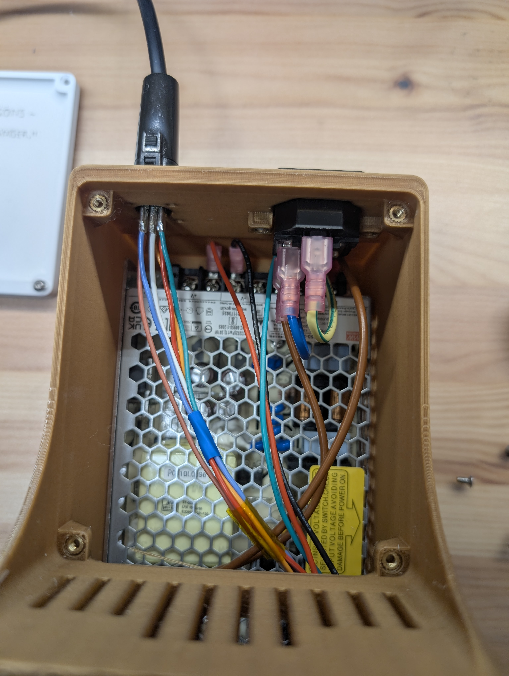
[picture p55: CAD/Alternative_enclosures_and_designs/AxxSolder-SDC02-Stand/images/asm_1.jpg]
Assembly Progress 1

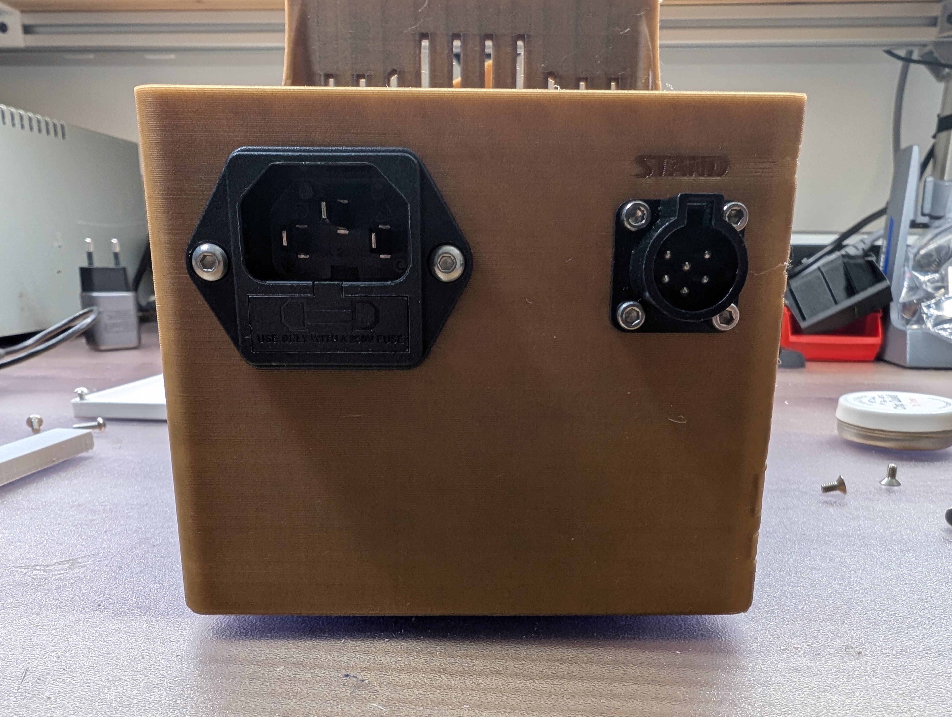
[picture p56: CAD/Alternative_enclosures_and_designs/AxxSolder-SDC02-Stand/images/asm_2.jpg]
Assembly Progress 2

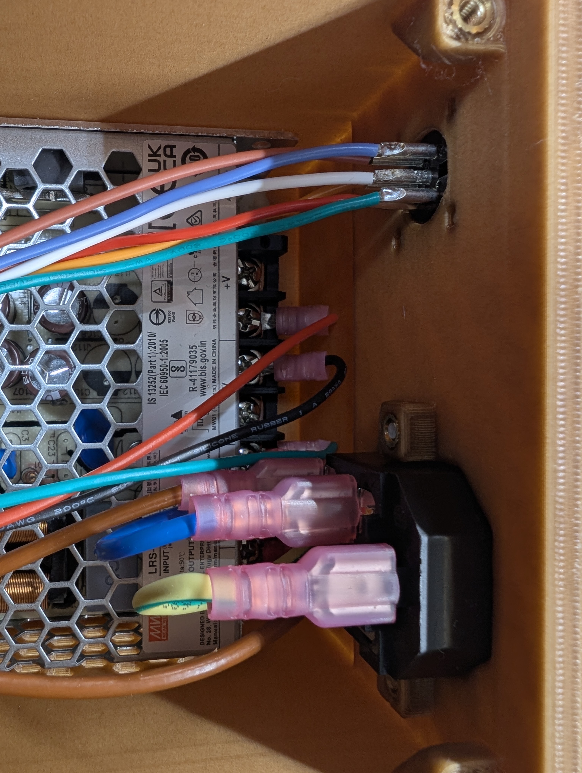
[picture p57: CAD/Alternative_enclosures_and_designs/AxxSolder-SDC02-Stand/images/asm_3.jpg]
Assembly Progress 3


## Installing the Rocker Switch

Install the rocker switch on the stand by pressing it in from the outside until it clicks into place. Verify that it is not loose.

Once done, **connect the two Line (brown wires) coming from the IEC plug and the 24V PSU to the rocker switch.**

As the switch is simply on/off, it does not matter which wire goes in which pin.

> **⚠️ Important:** Do not connect using the Neutral (blue wire)!! If for some reason there is a failure of the insulation on the switch, this could be dangerous.

## (Optional) Installing the USB-C Breakout

There is space in the stand to install a USB-C breakout board, which can then be connected to the Axxsolder via a USB-C cable.

This enables:

- Easier firmware updates, as you do not have to disassemble the lid to connect the USB cable to the AxxSolder directly.

I am using a USB-C breakout board as that is what I had available and I did not want to spend more funds on this project. There are simpler solutions, such as panel-mounted USB-C modules that come already with the cable, but you will need to modify the CAD to fit those (should be very simple).

If you do not need this capability, keep it simple and skip this step.

The USB-C does not work for power delivery (yet), as the breakout board I am using only supports 5V 1.5A connections, and the AxxSolder needs 19-24V. This is for the next version.

### Step 1 - Prepare the Cable

Find a short (10-15cm), low-profile (< 13mm) right-angle cable that will fit in the space between the AxxSolder and the stand.

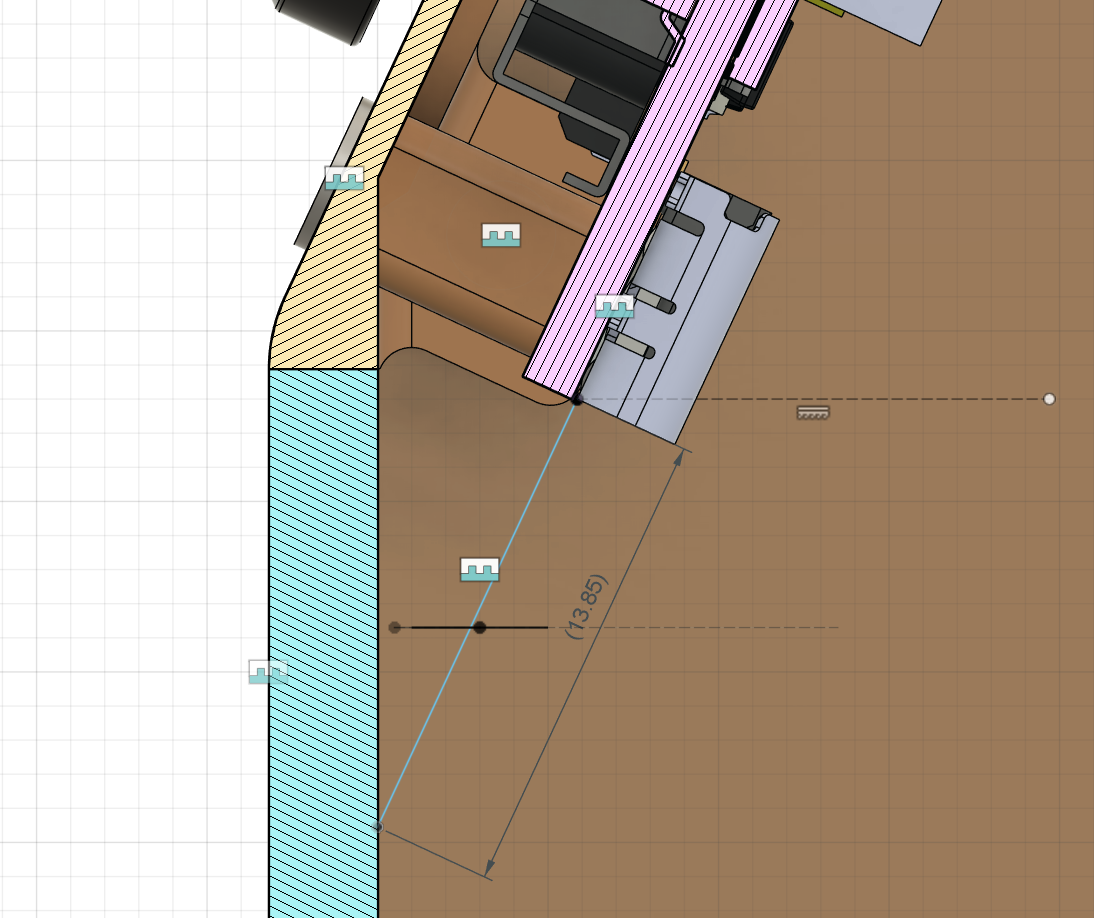
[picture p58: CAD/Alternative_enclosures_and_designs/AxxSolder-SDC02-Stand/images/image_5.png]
USB Cable Clearance


I have placed a suggestion in the BOM. If you cannot find such a cable, another option is using a 90-degree USB-C adapter and then using a regular cable.

Cut the cable to the right length and strip one end of it, then solder the wires to the breakout board as per the USB-C standard pinout.

### Step 2 - Install the USB-C Breakout Board

Install the USB-C board to the stand by using **2 M3 x 6 SCHS/SBHS screws**.

### Step 3 - Connect the Cable to the AxxSolder

Connect the USB-C cable to the AxxSolder.

## Installing the Axxsolder

Now that the base is wired, the last step is to install the Axxsolder PCB and complete the connections for the stand.

Prior to the installation of the AxxSolder, ensure that the firmware has already been flashed, either via USB or via the STLink Programmer. For more information, check the [Axxsolder readme](https://github.com/AxxAxx/AxxSolder).

To begin with, install the AxxSolder PCB to the faceplate with **4 M2.5 x 12 mm CSK screws and 4 M2.5 nuts**. Do not overtighten to prevent damage.

Then, cut the wires coming from the Hirose connector and from the PSU, strip them and optionally crimp them with ferrules (recommended).

### Axxsolder Terminal Connections

| AxxSolder Pin | Wire Origin  | Wire Color |
| :--- | :--- | :--- |
| VIN | PSU V+ | Red |
| GND | PSU V- | Black |
| RED | Hirose Pin 2 | Red |
| BLU | Hirose Pin 5 | Blue |
| GRN | Hirose Pin 1 | Green |
| EARTH | PSU EARTH | Green |
| IN1 | Hirose Pin 6 | White |
| IN2 | Hirose Pin 3 | Orange |
| STAND | Hirose Pin 4 | Brown |

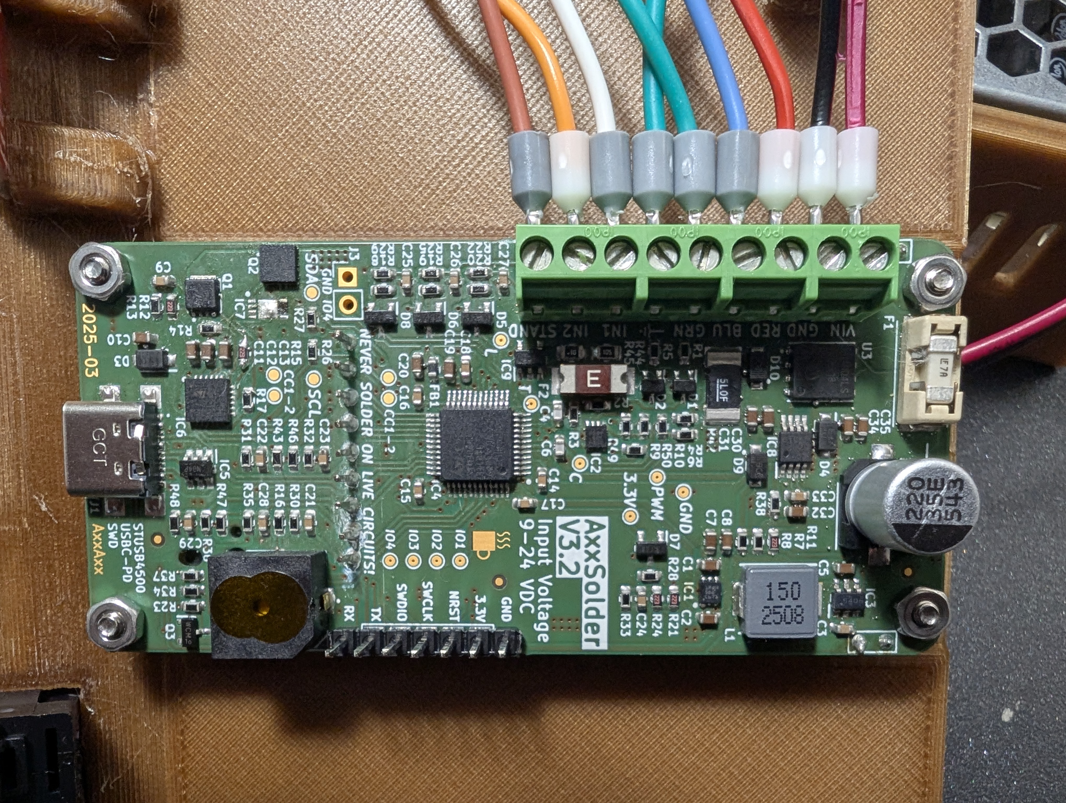
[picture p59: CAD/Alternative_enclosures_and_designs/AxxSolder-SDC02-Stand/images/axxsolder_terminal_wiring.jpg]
Axxsolder Terminal Wiring


Next, install the faceplate on the stand using the **4 M3 x 6 mm CSK screws**, to be installed from the side of the stand.

Finally, install the encoder and button caps.

## Installing the Tray

The final step is to install the tray. This can be done with **4 M3 x 12 mm CSK/SBHS screws**.

This tray has two functions:

1. It allows you to store solder, soldering wick, etc, on top of the stand for easy access.
2. It provides easy access to the wiring in case of need, for inspection or modifications, all while preventing users from touching the 230V wiring during operation.

**⚠️ Safety Warning:** For your safety, **NEVER open the tray while the AxxSolder is plugged in to the MAINS!!**

**This completes the assembly of the AxxSolder SDC02 stand with integrated PSU.**

<table>
  <tr>
    <td>Completed Stand Front</td>
    <td>Completed Stand Side</td>
  </tr>
</table>

## TODO

- [ ] Change USB design to enable USB-C power delivery to be able to take the stand on-the-go with a compatible power bank. Need to find or make a proper USB-C PD break-out board.

## Credits

- Axxsolder design by [AxxAxx](https://github.com/AxxAxx/AxxSolder)
- SDC02 stand pinout figured out by [ttelford](https://github.com/AxxAxx/AxxSolder/tree/main/CAD/Alternative_enclosures_and_designs/Geeboon%20Stand)

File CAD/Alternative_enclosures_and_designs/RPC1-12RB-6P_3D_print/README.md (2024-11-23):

# 3D Printed Housing
The parts can be sources from JLC3DP.com With the following parameters:
- MJF (NYLON)
- with PA12-HP Nylon
 
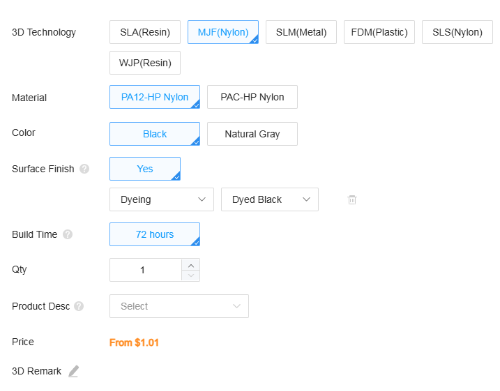
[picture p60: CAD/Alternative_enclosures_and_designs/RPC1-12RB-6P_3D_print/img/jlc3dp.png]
3d print at JLC3DP


# PCB
The gerber files and Easy EDA PCB is available in the PCB subfolder. There is no corresponding schematic, this was done by just placing vias on the PCB directly. The PCB is a 2 layer board, thickness 1.6mm.

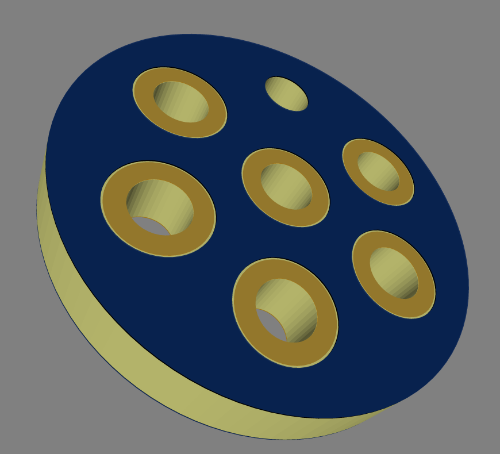
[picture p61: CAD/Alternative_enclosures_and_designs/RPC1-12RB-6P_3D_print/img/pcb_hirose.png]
pcb


## Pins
Mill-Max 1460-9-00-80-00-00-03-0 can be used to connect the PCB to the housing. The pins are available at 
[Mouser](https://www.mouser.de/ProductDetail/Mill-Max/1460-9-00-80-00-00-03-0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).

# Assembly
You have to make sure that the pins connect to the handle connector properly while not preventing the housing from being pushed all the way in.
A connector can be pushed into the 3D printed part for aligning the pins and the PCB. While still having everything put together the pins can soldered to the PCB. When having a HT Nylon part, the housing should be able to withstand soldering quickly.

Assembling the PCB apart from the housing is not recommended, since the tolerances of the housing and the handpiece connector are quite tight. It would be hard to get everything aligned properly. 

After assembly just use some wire cutters and trim the pins to the desired length.

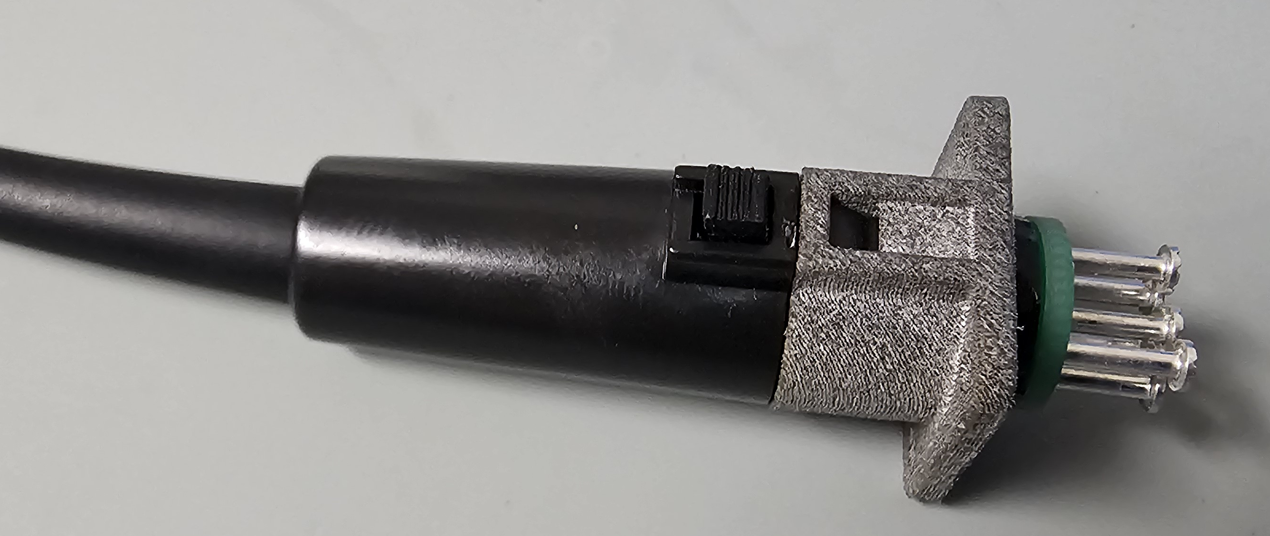
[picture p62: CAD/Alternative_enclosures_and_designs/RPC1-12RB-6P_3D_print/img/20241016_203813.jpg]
connector assembled

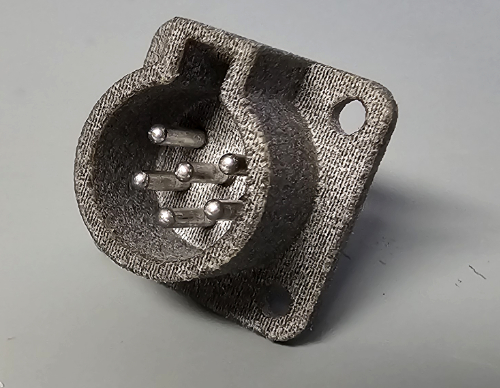
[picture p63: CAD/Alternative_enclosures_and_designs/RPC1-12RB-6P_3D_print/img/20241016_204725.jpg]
connector front

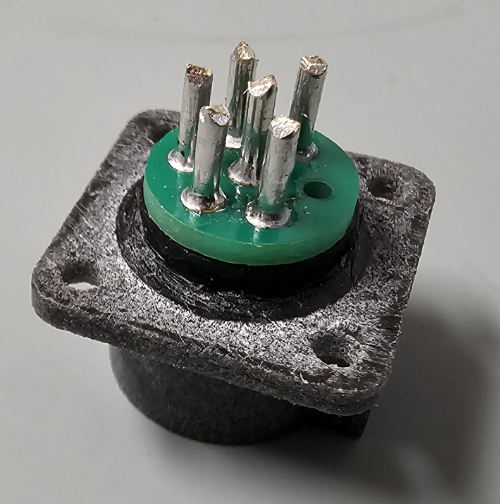
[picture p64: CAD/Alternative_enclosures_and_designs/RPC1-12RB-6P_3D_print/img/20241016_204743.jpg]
connector back


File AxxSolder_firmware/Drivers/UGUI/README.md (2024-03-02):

This is a forked version adding several enhancements:<br>
- Code reworked using [0x3333](https://github.com/0x3333/UGUI) UGUI fork.
- New font structure and functions.<br>
Fonts no longer require sequential characters, now they can have single chars and ranges, also support UTF8.<br>
This allows font stripping, saving a lot of space.<br>
- Add triangle drawing
- Add bmp acceleration (So the bmp data can be send using DMA), or use FILL_AREA driver if available.<br>
- Add 1BPP bmp drawing.
- 1BPP fonts can be drawn in transparent mode.<br>
- Modify FILL_AREA diver to allow passing multiple pixels at once.
- Font pixels are packed and only drawed when a different color is found.<br>
  This greatly enhances speed, removing a lot of overhead, specially when drawing big fonts.<br>

# Introduction
## What is µGUI?
µGUI is a free and open source graphic library for embedded systems. It is platform-independent
and can be easily ported to almost any microcontroller system. As long as the display is capable
of showing graphics, µGUI is not restricted to a certain display technology. Therefore, display
technologies such as LCD, TFT, E-Paper, LED or OLED are supported.

## µGUI Features
* µGUI supports any color, grayscale or monochrome display
* µGUI supports any display resolution
* µGUI supports multiple different displays
* µGUI supports any touch screen technology (e.g. AR, PCAP)
* µGUI supports windows and objects (e.g. button, textbox)
* µGUI supports platform-specific hardware acceleration
* Custom fonts can be added easily, several included by default, including cyrillic.
* TrueType font converter available: [ttf2uGUI](https://github.com/deividalfa/ttf2ugui)
* integrated and free scalable system console
* basic geometric functions (e.g. line, circle, frame etc.)
* can be easily ported to almost any microcontroller system
* no risky dynamic memory allocation required

## µGUI Requirements
µGUI is platform-independent, so there is no need to use a certain embedded system. In order to
use µGUI, only two requirements are necessary:
* a C-function which is able to control pixels of the target display.
* integer types for the target platform have to be adjusted in ugui_config.h.

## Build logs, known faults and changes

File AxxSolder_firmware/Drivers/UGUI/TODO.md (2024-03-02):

# Todo List

## Components

* Add Radio Group
* Add Slider
* Add Menu Bar
* Add Scroll Bar
* Add Listbox
* Add rounded borders capabilities to all components

## Functionality

* Add FrameBuffer
    * Add dirty pages function, draw only changed pages
* Add support for more BMP formats
* Generalize functions, too much repeated code
* Create components by size, currenlty you need to give coordinates
* Allow a component to have components, like a Frame
* Allow better window management(Currently, you can't delete an active window)

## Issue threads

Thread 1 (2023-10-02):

Add BOM with component cost

AxxAxx, 2023-10-02:

AxxAxx, 2023-10-03:
Solved with commit e5a98a49e9020199b92ceb11a6f21cf830e13e3f

Closed 2023-10-03.

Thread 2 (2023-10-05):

Replace expensive DC/DC to cheaper alternative

AxxAxx, 2023-10-05:
Replace expensive TRACO Power TSR 2-2450 DC/DC to cheaper alternative.

Perhaps on-board DC/DC solution designed around the TPS54302DDCT
https://www.ti.com/product/TPS54302/part-details/TPS54302DDCT

Closed 2023-10-06.

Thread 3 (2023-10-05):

Remove unused ambient temperature sensor

AxxAxx, 2023-10-05:
The ambient temperature sensor TMP236AQDBZRQ1 is unused and could be removed from PCB to reduce cost and complexity.
Firmware needs to be updated to not show ambient temperature anymore

AxxAxx, 2023-10-07:
The temp sensor and capacitors are cheap (0.73 Euro), better leave it on PCB. It might come handy to have in the future.

AxxAxx, 2023-10-07:
closed

wfkbsse, 2023-11-08:
LTC4440A-5 is too expensive. Can you exchange it for a cheaper one

?

Closed 2023-10-07.

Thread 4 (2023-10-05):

Utilize current measurement for "no-tip-detection"

AxxAxx, 2023-10-05:
The board is equipped with a current shunt. The voltage over the shunt is amplified with the on-board OP-amp and measured with the STM32 ADC.

By measuring the current it should be possible to detect if a tip is missing and/or broken. This requires some clever timing and measurement during the high-phase of the PWM.

At the moment the actual temp shows ~567 deg C when no tip is attached. It would be nice if AxxSolder detected a "no-tip" status.

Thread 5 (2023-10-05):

Enable stand-by/sleep with buttonpress

AxxAxx, 2023-10-05:
Especially for the portable version, it would be nice to have the iron cool down with a press on the encoder. The iron could heat up again from the next press. It would act like toggling sleep mode which can now only be done by resting the iron on the AxxSolder.

AxxAxx, 2023-10-09:
Solved with e4a5cdaa7cb3eda2c4c0b2f66ff122b722759787

Closed 2023-10-09.

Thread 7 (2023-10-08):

Implement automatic detection of handle T210/T245

AxxAxx, 2023-10-08:
This can be done as the T210 has pin 5 and 6 connected internally in the handle connector.

Use one of the inputs.

Now the tipchanger and stand has one input each. That is not necessary.

AxxAxx, 2023-10-09:
Solved with 784f87159bda4c6acbb9f1e3f80c7e201c178e74

Closed 2023-10-09.

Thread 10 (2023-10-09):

Implement READ/WRITE to EEPROM

AxxAxx, 2023-10-09:
By utilizing EEPROM one could for example:
- **Remember SET Temperature** - Save the current _SET Temperature_ and automatically use that same value next time AxxSolder is powered on.
- **Adjust EMERGENCY_SLEEP_TIME** - Set the time for when AxxSolder will automatically go into sleep mode, currently set to 30 min.
- **Set tuning parameters** - allow the user to calibrate the temperature of AxxSolder and save the settings.

AxxAxx, 2023-11-18:
Closed - solved

Closed 2023-11-18.

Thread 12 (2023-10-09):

Power via USB-C PD

AxxAxx, 2023-10-09:
Implement a USB-C Power delivery negotiation circuit.
Today USB-C PD can deliver up to 100W, whis is enough for C210 cartridges which draw up to ~60W.
C245 cartridges on the other hand draw ~120W and can not be powered of such a solution (as of today).

AxxAxx, 2023-11-21:
Move to AxxSolder_fw repo as this is a hardware related issue.

Closed 2023-11-21.

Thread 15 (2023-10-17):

Connect tip of soldering iron to protective earth (PE). This reduces the risk of ESD damage

AxxAxx, 2023-10-17:

AxxAxx, 2023-11-21:
Move to AxxSolder_fw repo as this is a hardware related issue.

Closed 2023-11-21.

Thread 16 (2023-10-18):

Replace big automotive fuse with something smaller and SMD

AxxAxx, 2023-10-18:
For example: https://www.littelfuse.com/products/fuse-blocks-fuseholders-and-fuse-accessories/fuse-blocks/154.aspx

AxxAxx, 2023-11-21:
Move to AxxSolder_fw repo as this is a hardware related issue.

Closed 2023-11-21.

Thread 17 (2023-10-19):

Stand temperature instead of full cooldown

blackfield3k, 2023-10-19:
First of all, thank you for this awesome project and the support you provided via email. First station is done and working!

I noticed that the iron fully cools down in the stand. As i remember the JBC stations just reduce the temperature to 150°C or something. Someone told me that would reduce the stress and oxidation of the tips. I can´t confirm that but it sounds plausible.

After 10-15 minutes the JBCs shut off the heaters completly.

AxxAxx, 2023-10-20:
Nice! Thanks! You are the first one I know to have built one, nice with some user-input!

Yes!
JBC calls this  "Sleep & Hibernation" and write:

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
It prevents the dissolution of the tip’s iron coating into molten solder.
>
>**Hibernation Mode**
>After a configurable period of tool inactivity in the stand (10 min factory default), the tool enters into Hibernation Mode.
It cuts off the power supply making the tip reach room temperature thus preventing oxidation and saving energy.

A graph can be seen here: https://www.jbctools.com/top10.html

I never really thought about shutting off completely as an issue, I underatand that elevated temperatures for a long time reduced the lifetime.
Thermal cycling and fatigue is also a thing of course...
But okay, I assume JBS has put a lot of thought into this.

It should be fairly staright forward to implement.

AxxAxx, 2023-10-20:
I added a few lines to the code.
Lets call the ´new mode "STANDBY"
After the iron is placed into the stand the temperature is set to STANDBY_TEMPERATURE (default 150 deg C) for X amount of time (default 10 min). After that the iron goes into sleep mode and switched off heating completely.

I will test the new implementation a bit more before I push it into the main branch.
If you want to test you can find the BINARY here:
https://github.com/AxxAxx/AxxSolder/tree/17-stand-temperature-instead-of-full-cooldown/Software/AxxSolder/Debug

AxxAxx, 2023-10-20:
Dont know if it is a feature or not but now you can get out from STANDBY to SLEEP with a buttonpress:
https://github.com/AxxAxx/AxxSolder/commit/6ba68a1f9d676d600e40142af75eae9afbca315f

You find the new AxxSolder.bin in the same place as before.

Good luck! :)

Closed 2023-10-22.

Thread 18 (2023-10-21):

Filter buttonpress input as handle input and stand input

AxxAxx, 2023-10-21:
Sometimes Axxsolder goes into sleep mode when changing themperature with the knob. This is probably due to noice on the encoder button, this signal should be filtered. Have to look into this

Closed 2023-10-22.

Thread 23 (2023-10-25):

Update enclosure to better fit/hold power connector

AxxAxx, 2023-10-25:
At the moment the PP45 power connector has to be glued with epoxy in place.
This solution should be reworked where mounting and selection of connector is considered.

Closed 2024-02-21.

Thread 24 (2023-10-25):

Rework station enclosure design

AxxAxx, 2023-10-25:
Improvement of station enclosure to have a proper closed enclosure, good locations for screw threads where needed.

f616, 2023-11-12:
Could you provide us with CAD files than can be edited in Fusion360?

f616, 2023-11-12:
This is in what I'm working now.

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

Wasn't yet printed and tested. If anyone finds value on this, and assuming the tests will be OK, please let me know and I can share the Fusion360 files.

AxxAxx, 2023-11-18:
> Could you provide us with CAD files than can be edited in Fusion360?

The CAD designs was all made in SolidWorks. Therefore I do not have any Fusion compatible design files. The best I have for you to build on is .STEP, which are availible at  https://github.com/AxxAxx/AxxSolder/tree/main/CAD

bennymeg, 2024-02-01:
It's also possible to import SolidWorks assemblies and parts directly into Fusion 360 now.

AxxAxx, 2024-03-01:
fixed in AxxSolder 3.0

Closed 2024-03-01.

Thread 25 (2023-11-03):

LCSC.com Part Numbers for v2.1 and v2.2

f616, 2023-11-03:
Hi,

Those are the part numbers for v2.1 and v2.2 from [LCSC](https://lcsc.com)

| Part (v2.1)                                               | Part (v2.2)                                                         | LCSC.com/JLCPCB Part # | Footprint                            | Comment             |
| --------------------------------------------------------- | ------------------------------------------------------------------- | ---------------------- | ------------------------------------ | ------------------- |
| C1, C6, C12, C14, C19                                     | C1, C6, C12, C14, C19                                               | C15850                 | Capacitor_SMD:C_0805_2012Metric      | 10u                 |
| C2, C3, C5, C7, C8, C9, C10, C11, C13, C20, C21, C22, C24 | C2, C3, C5, C7, C8, C9, C10, C11, C13, C20, C21, C22, C24, C28, C29 | C49678                 | Capacitor_SMD:C_0805_2012Metric      | 100n                |
| C4, C17, C18                                              | C4, C25, C27                                                        | C12891                 | Capacitor_SMD:C_1206_3216Metric      | 22u                 |
| \--                                                       | C17, C18                                                            | C6119901               | Capacitor_SMD:C_0805_2012Metric      | 22u                 |
| C25                                                       | \--                                                                 | C45783                 | Capacitor_SMD:C_0805_2012Metric      | 22u                 |
| C15, C16                                                  | C15, C16                                                            | C46653                 | Capacitor_SMD:C_0805_2012Metric      | 1n                  |
| C23                                                       | C23                                                                 | C310841                | EMZR500ARA331MJA0G:CAPAE1030X1050N   | 330u                |
| C26                                                       | C26                                                                 | C113832                | Capacitor_SMD:C_0805_2012Metric      | 75p                 |
| D1, D3, D5, D6, D12                                       | D1, D3, D5, D6, D12                                                 | C916425                | BAT54S,215:SOT95P230X110-3N          | BAT54S              |
| D2                                                        | D2                                                                  | C2687553               | PMEG6020ER,115:PMEG6020ER115         | PMEG6020ER          |
| D4                                                        | D4                                                                  |                        |                                      |                     |
| D7                                                        | D7                                                                  | C503376                | PMEG10030ELPX:SODFL4725X110N         | PMEG10030ELPX       |
| D8                                                        | D8                                                                  | C707996                | SMCJ24CA:DIONM7969X262N              | SMCJ24CA            |
| F1                                                        | F1                                                                  | C352820                | 3557-2:3557-2                        | 10AFuse             |
| IC1                                                       | IC1                                                                 | C688540                | LTC4440AHMS8E-5#PBF:SOP65P490X110-9N | LTC4440AHMS8E-5#PBF |
| IC2                                                       | IC2                                                                 | C529357                | STM32G431KBT6:QFP80P900X900X160-32N  | STM32G431KBT6       |
| L1                                                        | L1                                                                  | C2847543               | INDPM7366X300N                       | SRP7028CC-100M      |
| IC3                                                       | IC3                                                                 | C2869735               | TMP236AQDBZRQ1:SOT95P237X112-3N      | TMP236AQDBZRQ1      |
| IC4                                                       | IC4                                                                 | C882727                | OPA2333AIDRBR:SON65P300X300X100-9N-D | OPA2333AIDRBR       |
| J1                                                        | J1                                                                  |                        |                                      |                     |
| J4                                                        | J4                                                                  |                        |                                      |                     |
| LS1                                                       | LS1                                                                 | C391032                | CMI-9653S-SMT-TR:CMI9653SSMTTR       | CMI-9653S-SMT-TR    |
| PS1                                                       | PS1                                                                 | C115288                | SOT230P700X190-4N                    | LD1117AS33TR        |
| IC6                                                       | IC6                                                                 | C311983                | SOT95P280X110-6N                     | TPS54302DDCR        |
| Q2                                                        | Q2                                                                  | C551416                | 2N7002NXAKR:SOT95P230X110-3N         | 2N7002NXAKR         |
| R1, R5, R6, R17, R25, R26                                 | R1, R5, R6, R17, R25, R26                                           | C17673                 | Resistor_SMD:R_0805_2012Metric       | 4k7                 |
| R2                                                        | R2                                                                  | C17713                 | Resistor_SMD:R_0805_2012Metric       | 47k                 |
| R3                                                        | R3                                                                  | C17772                 | Resistor_SMD:R_0805_2012Metric       | 6k8                 |
| R8, R9, R11, R12, R13, R14, R16, R18                      | R8, R9, R11, R12, R13, R14, R16, R18                                | C17414                 | Resistor_SMD:R_0805_2012Metric       | 10k                 |
| R10                                                       | R10                                                                 | C346458                | WSLP25122L500FEA:RESC6432X89N        | 2m                  |
| R15                                                       | R15                                                                 | C17557                 | Resistor_SMD:R_0805_2012Metric       | 220                 |
| R19, R20                                                  | R19, R20                                                            | C4310                  | Resistor_SMD:R_0805_2012Metric       | 1k5                 |
| R21, R22                                                  | R21, R22                                                            | C17709                 | Resistor_SMD:R_0805_2012Metric       | 470k                |
| R23, R24                                                  | R23, R24                                                            | C17556                 | Resistor_SMD:R_0805_2012Metric       | 220k                |
| R27                                                       | R27                                                                 | C17720                 | Resistor_SMD:R_0805_2012Metric       | 49.9                |
| R28                                                       | R28                                                                 | C149504                | Resistor_SMD:R_0805_2012Metric       | 100k                |
| R29                                                       | R29                                                                 | C17446                 | Resistor_SMD:R_0805_2012Metric       | 13k3                |
| U1                                                        | U1                                                                  |                        |                                      |                     |
| U2                                                        | U2                                                                  | C2760081               | BSC014N04LS:BSC014N04LS              | BSC014N04LS         |

I've orders the boards, but please bear in mind I've not tested them yet.

**update**
included the v2.2 components

AxxAxx, 2023-11-18:
Thanks!
This could be useful for people using LCSC.com/JLCPCB !

Andy79881, 2024-02-15:
@f616 Thanks for your work regarding LCSC part numbers. I really appreciate that. Could you check for update to the latest HW release (V2.2)?

f616, 2024-02-17:
@Andy79881 updated the table with the components from v2.2
I've a few pre-popuçated boards v2.1, If you need one, please let me know

Andy79881, 2024-02-18:
@f616 Thanks for the update!

Closed 2024-03-01.

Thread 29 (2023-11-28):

Detect if voltage is too low and do not to switch heater

AxxAxx, 2023-11-28:

Closed 2024-02-21.

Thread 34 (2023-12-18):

Individual tip calibrations

wildstar87, 2023-12-18:
One of the things that is great about the custom firmware for the STM32 T12/C245 stations, is the ability to save individual tip calibrations, since even with genuine JBC tips, different versions/models have varying temperatures, with the clone tips even more so.  I have both Unisolder and Aixun T3A, neither offers this capability, so if you have cartridges that don't match the built-in tip profiles, you are out of luck.  With Unisolder these profiles can only be modified through firmware change, if you understand the code, and how the author coded it.  With the Aixun T3A, you can change the calibration profile through a number of temperature steps, but it has two problems.  First, it is not tip specific, Two even though it saves the value, this is change is never displayed to the user, so when you go back into the menu, all setting show with no changes.

AxxAxx, 2023-12-19:
Good input.
How would you name each of the tips? with their JBC number?

Or would it make sense to have one "default" configuration and then the user can add "custom conf 1", "custom conf 2" and so on.

And then maybe you can select the default start-up configuration in a settings menue?

wildstar87, 2023-12-19:
Given the number of variations in JBC tip numbers, putting in a pre-populated list might be troublesome, in addition to the number not being immediately descriptive, but I don't know how much memory space that would take up, if you put in all the possible tip model numbers.  The other thing is the clone tips often use a different numbering scheme that they came up with.  Unfortunately I've only see pictures on the STM32 T12/C245 stations, and I think that they are pre-populated tip numbers for the T12 at least, not sure if they have all of them, or just the popular ones.  Maybe having a limited character field, like 8-10 characters, where you can specify the name, using the encoder to scroll letter/numbers.

The custom firmware made by DavidAlfa, I think does have a base/default tip profile, then you can base other tips off that profile to start, but each tip has it's own parameters that can be modified, that can be done through just temperature calibration points.

Not sure how many entries you would need.  Maybe look at his code to see what he's doing?

AxxAxx, 2024-10-08:
I will look into this in coming fw updates. Thanks for your ideas!

Closed 2024-10-08.

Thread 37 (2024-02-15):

Schedule for V3.0

Andy79881, 2024-02-15:
Is there any rough schedule available for V3.0 release? I think about waiting for the V3.0 release.

AxxAxx, 2024-02-16:
Hi!

I have went through a "alpha" version of AxxSolder 3.0 now for a while. If works well except that there could in some cases be high voltage spikes due to cable inductance while hot-plugging AxxSolder that could eventually kill the DC-DC controller.

I have ordered new PCBs with an updated DC-DC converter that should be able to handle a the high transient voltage when hot-plugging.

I hope these PCBs arrive within 2 weeks and I can do the final testing and then release 3.0

Closed 2024-03-01.

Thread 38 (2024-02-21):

Maybe u can change CMI-9653S-SMT-TR for something more popular and available? Ordering it from mouser doesnt make sensie for me and i cant find it anywhere else.

AxxAxx, 2024-02-21:
Maybe u can change CMI-9653S-SMT-TR for something more popular and available? Ordering it from mouser doesnt make sensie for me and i cant find it anywhere else.

_Originally posted by @Froglol in https://github.com/AxxAxx/AxxSolder/issues/26#issuecomment-1956450665_

AxxAxx, 2024-02-21:
DigiKey, Mouser, RS Components all have these in very large quentities.
https://www.digikey.se/en/products/detail/cui-devices/CMI-9653S-SMT-TR/6012408
https://eu.mouser.com/ProductDetail/CUI-Devices/CMI-9653S-SMT-TR?qs=qCxwlXJ4fnz7UpLQu8UKbg%3D%3D
https://se.rs-online.com/web/p/piezo-buzzers/2596214

I would say this is a quite common buzzer.

But do you have any replacement part in mind? If you can find one with the same size and resonance freq. I can add that as a "Alternative Part" to the schematic.

If not, this is not a critical part and yhou could easyly replace it with a buzzer with similar resonance freq and similar footprint. Doesn't have to be exact.

Froglol, 2024-02-21:
I just found something similar on alliexpress. Buying from Digi RS or Mouser doesnt make sense for me because the shipping costs as much as 10 od these. Ordering all parts from them also doesnt make sense also because on alliexpress u can get them in better prices(especialy resistors and capacitors when buying a sample book). For nów I will wait for 3 revision. Thanks for your work!

f616, 2024-03-01:
I've used a compatible from lcsc.com. please check issue #25

Closed 2024-02-24.

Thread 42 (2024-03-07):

Sometimes miss current measurement

AxxAxx, 2024-03-07:
AxxSolder seems to miss current measurement and shows " --- " as temperature for approximately 0.25 s every 10 minutes.

It basically blinks " --- " very fast and then back to showing actual temperature.

This is probably due to the ADC not being read at the correct time at some points.

Does not effect the thermal performance.

Closed 2024-03-26.

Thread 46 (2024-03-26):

Implement a clamping anti-windup method

AxxAxx, 2024-03-26:
The current anti-windup limits the I-part but does not stop integration.
A better anti-windup scheme would be like the "clamping" method used in the simulink PID block:
https://se.mathworks.com/help/simulink/slref/pidcontroller.html

**clamping**
_Integration stops when the sum of the block components exceeds the output limits and the integrator output and block input have the same sign. Integration resumes when the sum of the block components exceeds the output limits and the integrator output and block input have opposite sign. Clamping is sometimes referred to as conditional integration._

Closed 2024-03-28.

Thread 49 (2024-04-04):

Automatically detect USB-PD supply capability and limit power

AxxAxx, 2024-04-04:
Automatically ask USB-PD supply of it's power capability with the STUSB4500 negotiation chip and limit the output power based on the capability.

There is currently no such check and if you power AxxSolder with a 65W capable USB-PD source and try to use a C245 cartridge (which will draw 120W) AxxSolder turns off as the supply voltage can not be kept by the supply.

c0d3z3r0, 2024-04-26:
AP33772S might be a good replacement for STUSB4500 to add EPR support (240W). It requires a few more external components, though.
https://www.diodes.com/part/view/AP33772S?BackID=10099

AxxAxx, 2024-04-27:
Nice, they are finally arriving, the PD3.1 sink controllers!
Seems like one has to wait a bit more to get the hands on the AP33772S IC's though. Not availible anywhere for now what I can see?

I assume more IC manufacturers will release PD3.1 sink controllers too in the near future.

c0d3z3r0, 2024-04-27:
Oh oops, didn't check availability and just assumed it is :D There one ftom Hynetek as well, but also not available anywhere.

Yeah, maybe even G4931 with 512KB. Shouldn't need too much code change.

Hmmm, weird. Datasheet says PD spec 3.0 only o.O UCPD page lists G4 series

AxxAxx, 2024-04-27:
OK, haven't digged into it too much but [here](https://www.st.com/content/st_com/en/ecosystems/stm32-usb-c.html#stm32typec-why-use-usb-c) it says:

STM32 UCPD MCUs are compliant with the latest USB PD r3.1 specifications and support:
- SPR messages (standard power range up to 100 W)
- EPR messages (extended power range up to 240 W)
- PPS (programming power supply)
- AM (alternate mode)

And lists STM32G4 series to have one UCPD interface
Don't know.. :)

c0d3z3r0, 2024-04-27:
Yeah, maybe it only depends on the sw stack or the datasheet is outdated, no idea

c0d3z3r0, 2024-04-27:
At home again, so I could have another look....
- The UCPD marketing site says what you cited already (EPR, VBUS 48V, 240W) https://www.st.com/content/st_com/en/ecosystems/stm32-usb-c.html
- STM32G4* are named explicitly but datasheets mention PD 3.0 only
- Their UCPD wiki does only mention PD up to 100W, no EPR at all https://wiki.st.com/stm32mcu/index.php?title=Introduction_to_USB_Power_Delivery_with_STM32
- The protection chips TCPP* only support VBUS up to 22V and PD 3.0, max. 100W
- CubeMonUCPD only supports PD 3.0 https://www.st.com/en/development-tools/stm32cubemonucpd.html
- *X-CUBE-TCPP does support PD 3.1 EPR** https://github.com/STMicroelectronics/x-cube-tcpp

W....T....F....

AxxAxx, 2024-04-28:
Thanks for summarizing your finds!
Indeed the information is a bit all over the place.

Maybe it will clear out with time as PD3.1 EPR is getting more mature

NightHawk32, 2024-05-27:
Power negotiation and dynamic power limiting is handled in #62

Closed 2024-05-27.

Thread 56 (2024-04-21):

Sometimes the temperature is calculated to be 10 deg too high for ~100 ms, fix this

AxxAxx, 2024-04-21:
Sometimes the temperature is calculated to be 10 deg too high for ~20 ms.

This is probably due to some sync issue with when the temperature is read.
In ordet to trouble shoot this, use one DAC channel on the MCU to measure and trigger a abnormal temperature measurement with an external oscilloscope.

Closed 2024-04-24.

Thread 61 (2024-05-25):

Read board version at startup

AxxAxx, 2024-05-25:
Read the bits USR_1,2,3 at startup and save the board version these bits represent.

AxxAxx, 2024-05-27:
fixed with https://github.com/AxxAxx/AxxSolder/commit/9df98b3c672e88228af7e279bcf0f670c1de0c36

Closed 2024-05-27.

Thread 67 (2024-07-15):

Is support for tweezers possible, such as the AN115?

F10F4F9, 2024-07-15:
As mentioned in the title, this would be a standout feature that many are probably waiting for.

Thanks
Marco

AxxAxx, 2024-07-17:
It COULD for sure be added. But that is to an increased BOM cost. What would people be willing to pay extra for tweezer support? I estimate it to increase the BOM cost with 20 Euro or so and some added "complexity" for the user when connecting and sensing.

I think it it still better to have tweezer support in the AxxSolder and not create a separate hardware only for tweezers. Do you agree?

Everything is there in terms of software and hardware (for one heating circuit). It is a bit of work to implement in a new hardware in the future but not too much. What I have to look into is how the user would connect either tweezers, iron or dual iron (now when we would have two heating circuits) and how the tip sensing would work. Haven't figured that out yet.

The JBC tweezer is also designed to be heated with AC current. There are two diodes inside allowing one tip to heat up during the positive phase of the AC and the other during the negative phase. Either one removes the diodes and modify the tweezers to be heated from two DC sources or implement a H-bridge drive...

F10F4F9, 2024-07-22:
Yes, I agree with you; it should be integrated into the existing hardware and not create additional hardware just for the tweezers. Personally, I would avoid modifying the tweezers, even if it's a minor change. I believe compatibility should be maintained.

If you are looking for a tester and feedback, I could support that.

AxxAxx, 2024-07-24:
Sure! I will look into this and the different possibilities. It seems now that to drive the JBC tweezers you need a controllable AC current which could be achieved with a H-bridge drive. But thats a totally different topology than used now. I'll look more into it and see how it can be done and if it can give some other benefits.

I'll close this issue for now.

Closed 2024-07-24.

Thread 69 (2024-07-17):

DFU Fails

BB-BenBridges, 2024-07-17:
Hi there

I'm having an issue updating firmware over DFU. I connect the device to my Mac whilst holding the right most button. CubeProgrammer will detect the device for 5-6 seconds and then nothing. This obviously does not leave enough time to upload the firmware. I do not have an STLink programmer to test with.

Any suggestions? I assume I don't have to keep the button held?

AxxAxx, 2024-07-17:
Hi!

No you do not need to hold down the button all the time. Only during the boot sequence.

Can you try
- a different cable
- Power up the AxxSolder from a DC source while pressing the button, then connect USB to your Mac. Do this without any handle connected.

//
Axel Johansson

AxxAxx, 2024-07-17:
Hi!

No you do not need to hold down the button all the time. Only during the boot sequence.

Can you try
- a different cable
- Power up the AxxSolder from a DC source while pressing the button, then connect USB to your Mac. Do this without any handle connected.

//
Axel Johansson

BB-BenBridges, 2024-07-17:
Same problem! Tried 3 different cables, and multiple ports on my Mac. CubeProgrammer detects it for a few seconds and then it's gone again. I'll try a Windows machine tonight incase it's a Mac issue

AxxAxx, 2024-07-24:
Did you find any solution to this?

It is difficult to help you with this as I can not replicate this problem on my machine..

AxxAxx, 2024-08-17:
Hi!
I know what the proeblem is now!
There is a bug in the newest ST programmer software (2.17):
Download version 2.15 instead and it should not throw the error.
The Readme is updated:
https://github.com/AxxAxx/AxxSolder?tab=readme-ov-file#firmware-update

BB-BenBridges, 2024-08-19:
@AxxAxx Amazing! Thanks for heads up. Update worked perfectly now.

BB-BenBridges, 2025-06-05:
Correct, the latest version (2.19) worked fine. You can remove the instruction to use version 2.15

Closed 2024-08-10.

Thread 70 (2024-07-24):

Hirose RPC1-12RB-6P(71) Obsolete

shakey2k, 2024-07-24:
Hi.  I stumbled upon your this and wanted to build a AxxSolder Portable.  I was in the process of ordering Hirose RPC1-12RB-6P(71) from mouser and it's now listed as obsolete.  I also tried some other electronics stores like digikey and they are also listing it as obsolete.  Do you know of an alternative for this connector end?

AxxAxx, 2024-07-24:
Hi!
Yes I know it can be difficult to source. But RS components have it as well as Farnell. I also have a bunch of them if you want to buy from me.

But as fas as other alternatives I have not found any. JBC use them and I am curious to know how they will handle it if the connectors are really going to get retired in the future and impossible to source.

Tell me if you find alternatives! :)

shakey2k, 2024-07-24:
I will consider buying one or two from you when your populated AxxSolder
PCB is available for sale.  When will it be available?   Depending on when
your populated AxxSolder PCB will be available, I might consider buying
your unpopulated AxxSolder PCB and do the soldering myself.  If I go that
route how do I purchase a Hirose RPC1-12RB-6P(71) from you also?

On Wed, Jul 24, 2024 at 3:28 AM Axel Johansson ***@***.***>
wrote:

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

AxxAxx, 2024-07-24:
The populated boards will be available again when Im back from vacation in one week. Then it will be the AxxSolder 3.1 hardware. (There are no big difference to the 3.0 version) Just better hardware RC filter on the buttons and encoder. There is no difference in performance. Just done in a nicer "proper" way.

So I'll update the Tindie store in one week with this update.

To buy just the connector I would suggest that you send me an email and pay me with PayPal. That will also be earliest in one week when Im back.

shakey2k, 2024-07-24:
How much for one connector and shipped to the US (zip code: 29445)?

On Wed, Jul 24, 2024 at 10:23 AM Axel Johansson ***@***.***>
wrote:

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

AxxAxx, 2024-07-24:
Its 14 Euro for shipping to the US and connector

shakey2k, 2024-07-24:
Awesome.  Please send me a Paypal invoice ***@***.***) for two and
I'll pay.

I'll wait for you to have the AxxSolder version 3.1 populated board in
stock and will purchase that once your back from your vacation.

One quick side note.  I'm going to build an AxxSolder portable to use with
the JBC NT115 Nano Handle.  The portable case has an area for an aluminum
insert so that you can rest the collar of a JBC soldering iron on it to
activate sleep mode, but for the Nando Handle, the metallic portion is not
part of the collar and more in the rear of the handle.  How do you envision
using placing the Nano Handle on the AxxSolder portable to place it into
sleep?

On Wed, Jul 24, 2024 at 11:27 AM Axel Johansson ***@***.***>
wrote:

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

AxxAxx, 2024-07-24:
GitHub removes the email adress. Email me.

You have my email here: https://github.com/AxxAxx

AxxAxx, 2024-07-25:
And regarding the nano handle and sleep:
I usually rest the cartridge on to the aluminium plate. Not the collar necessarily. I believe this will work with the NT115 handle too.

Closed 2024-08-10.

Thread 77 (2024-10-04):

Diode leakage current

electroniceel, 2024-10-04:
Your project looks interesting to me, especially the mobile version. Thanks for working on it and publishing it.

Before building my own I did take a look at the schematics. There was one thing that I noticed that could be an issue: diode leakage.

- D7 is used as protection diode for VBUS_IN. It is a BAT54S. I have used this diode type as protection for ADCs before too, and noticed considerable errors due to reverse leakage current of these diodes. Since then I switched to BAS70-04 which offer similar protection, but have much lower leakage.

- There are D5, D6, D8 that are also BAT54S on an analog input. In these places a bit of offset isn't that critical. But it would probably make sense to also switch them if you introduce one BAS70 to not increase the number of different BOM items.

- D10, between Blue and Red. It is a PMEG6020ER. I guess this is also used as protection diode, but I'm not 100% sure of it's function. For the C115 and C210 cartridges it looks to me like this diode is in the path of the thermocouple and leakage through this diode would create an offset in the tc voltage. To suggest a better alternative I'd have to be sure I understand all of it's functions.

Because diode leakage varies very much with temperature, these leakages are hard to calibrate out and make the device behave differently with temperature.

Please note: this issue is solely based on looking at the schematics. I have not done any measurements on an actual device. So it could very well be that this is no problem and the leakage doesn't pose an issue in practice.

AxxAxx, 2024-10-04:
Thanks!
Good points, all three of them. Here are my thoughts:

I understand your concerns about the BAT54S. In the early prototypes almost a year ago I started of with BAT54S at all locations as protection diodes. This is probably what JBC does in their stations. This is not confirmed by me but according to the great reverse engineering by johnmx at EEVBlogForum it is like this: https://www.eevblog.com/forum/testgear/jbc-soldering-station-cd-2bc-complete-schematic-analysis/

However, I know the BAT54S has problems with reverse leakage current and therefore these were changed to the BAV199  which has a very low typical leakage current of 3 pA. There are now two BAV199 at the thermocouple op-amps. The inputs for handle/stand sense signals and input voltage are not sensitive to this type of leakage current and it does not really matter - thus the BAT54S stayed. One could maybe change these to BAV199 to reduce the BOM lenght...

The idea with D10 has indeed been protection from inductive loads. Now I am not sure if it is strictly needed. And the leakage current of this could have an impact yes. I do not know exacltly how much. I have never seen any temperature drift of the AxxSolder from "cold start" at ~24 deg C to maybe a few degrees hotter after  using it a low in a warm day. I do not think it makes a difference in practise. But I see your point on paper. Maybe I'll look into this more in a coming version.

electroniceel, 2024-10-04:
Thanks for looking at this.

I have seen the BAV199 on the opamps. The Opamp inputs are usually specced with 10 mA current through the protection diodes, so the higher forward voltage of the BAV199 is fine there. So the BAV199 are an excellent choice for this location.

But the STM32 inputs don't allow 10 mA, there Vss - 0.3V is the lower limit. So a BAV199 would be a bit of a questionable choice there. The BAS70 is a bit of a middle ground there with more leakage than the BAV199, but it is still a Schottky with lower forward voltage.

Regarding D10 I was a bit irritated by the diode current capability. I wouldn't expect a constant current anywhere near 2 A there unless you have a serious inductor in the path. So maybe a BAV199 would work there too? It allows 160 mA continuous and 500 mA repetitive peak.

electroniceel, 2024-10-05:
If you think the BAV199 is a bit too flimsy to replace D10, maybe the SMF4L24AT1G you already use would be another good choice for lower leakage. In case of overvoltage due to inductance it would be used forward, which is a bit unusual for a TVS, but I don't see an issue with that in this case. It is specced at 100 nA max leakage at 24V, but when you sense the thermocouple you'd have much lower voltage, so even lower leakage. This is about 2 orders of magnitude better than the PMEG6020ER.

AxxAxx, 2024-10-05:
That is a great suggestion. I think for this design it is no major issue. But why not look into and implement this improvement in the next hw revision.
I am anyway going to look into how to do "open thermocouple detection" (https://www.ni.com/en/support/documentation/supplemental/10/overview-of-open-thermocouple-detection.html) in a better way to detect when there is no cartridge in the handle. This is now done by looking if there is a sudden impossible change in temperature and at the same time the current through the heater can be probed and if there is no current flowing the cartridge is faulty OR removed.

I will experiment with adding a 10 Mohm resistor between RED and 3.3V. this will drive the op-amp high and can be better detected by the MCU. Now the input "float" (D10 and a 5 mohm shunt is between RED and GND) when there is no cartridge detected.

By doing this I will have to re-calibrate all cartridges so perhaps changing the diode at the same time could be good.

electroniceel, 2024-10-05:
> I will experiment with adding a 10 Mohm resistor between RED and 3.3V. this will drive the op-amp high and can be better detected by the MCU. Now the input "float" (D10 and a 5 mohm shunt is between RED and GND) when there is no cartridge detected.

Good idea for detecting thermocouple problems. Maybe make the 3V3 through the 10M resistor switchable by hooking it to a GPIO pin that you could switch between input (=floating) and push/pull high? So you could toggle it and compare the results with/without. Making it switchable would remove any influence on the TC measurement.

AxxAxx, 2024-10-05:
Thats a great idea. I'll go on vacation now a couple of weeks but I'll look into this for the next hardware release. Thanks for the input and ideas!

AxxAxx, 2024-10-08:
I will close this issue and bring it to my to-do list for upcoming hardware revision!

Closed 2024-10-08.

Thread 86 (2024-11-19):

Add Displayed temperature filter length a user setting

AxxAxx, 2024-11-19:
The displayed termperature can be filtered by a moving average filter.
It can be nice to have this temperature filtered in order to reduce the small displayed temperature fluctuations during operations.
But it can in some cases be useful to have no or very little filtering e.g. when tuning the PID.

This could be a user setting. The user setting could be the lenght of the moving average filter.

AxxAxx, 2024-11-20:
solved with https://github.com/AxxAxx/AxxSolder/pull/88

Closed 2024-11-20.

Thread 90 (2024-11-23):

Individual tip parameters

AxxAxx, 2024-11-23:
The base [calibration](https://github.com/AxxAxx/AxxSolder?tab=readme-ov-file#temperature-calibration) I have done with polynomial fittings for each tip-series (NT115, T210 and T245) works in my experience good. They are fitted during tests with "common" tip geometries.

Of course, JBC has a lot of non-common tips for the e.g. T245 series: https://www.jbctools.com/c245-cartridge-range-long-life-tip-product-19-design-iron.html

It is unfeasible to have a temperature calibration for all these tips.
Tthere will however be a temperature difference at the tip of say C245171 and C245771 that is for sure. Is the tip-temperature even constant for the "tip" on C245792? probably not.

That said. If the tip temperature is very critical for a certain job, the user has to do a calibration for that specific tip before use. That would require a [JBC TID-B]( https://eleshop.eu/jbc-tid-b-digital-soldering-tip-thermometer.html) or similar device and the user would need to go through the 6-step temperature calibration.

There has been some requests on having a few "favorite tips" with individual settings. Maybe the user can save a couple of tuned temperature profiles and name them. Even to save PID parameters for specific tips. I feel like that is a future feature and would require the user setting menu to be a bit developed. If someone would like to improve the menu system on AxxSolder I would highly appreciate it. Otherwise it is on my to-do list for later.

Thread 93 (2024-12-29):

3-button mode

AxxAxx, 2024-12-29:
Under the rotary encoder there is a footprint for a third tactile button, exactly the same at the other two.
The idea of this was to make a version with three buttons and no encoder.
That would make sense for cases when you want AxxSolder to be really portable and fit in a pocket!
Today the rotary encoder is rather big and pokes out quite a lot in the portable verison.

A user setting would make AxxSolder work in 3-button mode and temperature could be changed up/down with two buttons instead of the rotary encoder.

AxxAxx, 2024-12-29:
Implemented in [Implement 3-button mode](https://github.com/AxxAxx/AxxSolder/commit/388e023fe33f9bc103bfacf1cac2bf72a5dfe8c2)

Closed 2024-12-29.

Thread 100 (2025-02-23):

Long-press encoder button to go into SETTINGS

AxxAxx, 2025-02-23:
As the title says:
Long-press encoder button to go into SETTINGS menu instead of having to restart the AxxSolder

Thanks to https://www.youtube.com/@sdgelectronics for this idea!

AxxAxx, 2025-03-13:
Solved with:
[Implement long-press SW_1 to go to main menu](https://github.com/AxxAxx/AxxSolder/commit/d2db616e140d06d11e8bd84e84a28fd3682c9550)

Closed 2025-03-13.

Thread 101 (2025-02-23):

BEEP at set temp

AxxAxx, 2025-02-23:
Implement a setting (ON/OFF) that is called "Beep at set temp"
If enabled AxxSolder makes a short beep sound when the target set temp is reached from STANDBY or SLEEP.

With this setting you do not need to look at the display and see if the temp is reached.

Thanks to Marin @ Discord!

AxxAxx, 2025-03-13:
Solved with:
[Implement beep-at-set-temperature function](https://github.com/AxxAxx/AxxSolder/commit/ca0e59f171aacfeeafa7728dec7eac52f06fa8b3)

Closed 2025-03-13.

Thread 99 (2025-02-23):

Long-press to set new preset temperature

AxxAxx, 2025-02-23:
Make it possible to long-press one of the two preset buttons and make the current "Set temp" the new saved preset temperature.

Thanks to https://www.youtube.com/@sdgelectronics for this idea!

AxxAxx, 2025-03-13:
solved with:
[Implement long-press SW_2 and SW_3 to set current set temp to new preset temperature](https://github.com/AxxAxx/AxxSolder/commit/55ab171f49f3b3ce0268ec68234ab7ec1aaacd49)

Closed 2025-03-13.

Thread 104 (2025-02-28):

common problems

mdbetancourt, 2025-02-28:
Is common to station which uses the C245 cartridge to experience problems like voltage/current leakeage and error when circuit is grounded like [https://www.youtube.com/watch?v=B7jLpHgR7fI](aixun T3A) does this solder has any of these problems?

AxxAxx, 2025-02-28:
Hi!
good question.
Tony himself (who did the video in your link) asked this recently on the Discord server.
https://discord.com/channels/1177970799697727548/1177970799697727551/1344310961024143401
You can read there so i do not have to write everything again.

But to summarize:
As long as you use a SELV (Floating output) power supply and provide a connection between mains protective earth (PE) and AxxSolder there is a galvanic connection between PE and the tip. By doing this there is no leak voltage on the tip.

If you power AxxSolder from USB PD with no grounding there will be leak voltage on the tip

Closed 2025-03-10.

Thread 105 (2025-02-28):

Why is used STUSB4500

mdbetancourt, 2025-02-28:
From the documentation the STM32G431CB supports usb PD 3.0 same as STUSB4500 there is any reason to use that chip?

AxxAxx, 2025-03-01:
Yes it does,
two reasons it uses a external USB PD att the moment:
1. The USB PD software does not fit the MCU at the moment, it is wuite big in size.
2. I have used the STUSB4500 a lot in the past and had code for it already.

With that said, I would like to go away from the STUSB4500 and use the internal in the future, but that requires changing the MCU

mede-erik, 2025-03-12:
To solve point number 1 I would recommend switching to a STM32G491CE/STM32G491CC, this could allow you to remove the STUSB4500 and gain space on the board

AxxAxx, 2025-03-12:
Yes, for the next version I plan to use the STM32G491CCU6

Closed 2025-03-10.

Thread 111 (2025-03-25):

problem with firmware 3.4

onatskiy-sergey, 2025-03-25:
There is no link to download the latest firmware 3.4 from March 19th.

also a small request, can you add a long hold on the button to save presets, thereby without going into the settings.

AxxAxx, 2025-03-25:
Hi!
The 3.4 is still in beta testing.
These are some of the new features in 3.4:

- Including a setting to turn on a short beep when the set temperature is reached @Marin
- Enter the settings menu from long-pressing the encoder button
- Update the preset temperature by long-pressing the specific preset button

You can find the link to the firmware here on the Discord forum:
https://discord.com/channels/1177970799697727548/1177970799697727551/1351951530064089149

onatskiy-sergey, 2025-03-26:
Unfortunately I don't have access, it says not available in discord. Well, I'll wait, I hope it will appear here soon too.

AxxAxx, 2025-03-26:
Hi!
Now the latest firmware is availible in releases!

Closed 2025-03-26.

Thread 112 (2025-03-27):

48V power input

doxygen-spammer, 2025-03-27:
Is it possible to accept up to 60V input by changing just a few parts (buck controller, capacitors, diodes, power switch)?

If so, should the firmware and voltage divider be adjusted, so they can measure up to 60V?

But most interesting: can the power switch and the firmware handle the required lower duty cycles?

Context: I would like to upgrade the JBC CD-2BQF soldering station with an AxxSolder.
The CD-2BQF brings a very sturdy case (heat resistant, drop resistant, ...), but the original firmware has a severe issue: sometimes the station freezes with the heating element turned on, which seems quite dangerous.
Another issue is that the CD-2BQF is very demanding on the AC supply.
While the public power grid works fine, solar inverters cause frequent freezes and error messages.

The 60V input would allow to use a 48V solar battery as power supply.
(End-of-charge voltage is 58.8V.)
The current 9–24V input only allows for 12V solar batteries or 18V power tool batteries, which isn’t that bad already. :)

chillymattster, 2025-04-07:
Hi there,
I really like this project and have been monitoring it for a while now. Great work!

I like the proposal not just because it offers mire flexibility in terms of power supply, it also would enable the use of T470 handle. In my opinion that would boost AxxSolder to the ultimate soldering station replacement by offering the greatest possible freedom in terms of choosing the handle and cartridges. Especially, as T470 handle can take C470 as well as C245 cartridges.

Cheers

AxxAxx, 2025-06-09:
I will see what I can allow in the next hardware. I think 60V is rather high and would rexuire more expensive and larger components for only a few users who need it.

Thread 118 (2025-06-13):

BAV199WQ schematic lib is missing

Matthias32, 2025-06-13:
HI,

when I run the ERC it said the BAV199WQ schematic symbol is missing. And indeed I can't find it in the 3rd-parties-libraries folder. Also in the standard KiCad lib I can't find it.

BR
Matthias

Closed 2025-06-17.

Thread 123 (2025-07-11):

three suggestions

chum998, 2025-07-11:
1. Does it support 28V, because USB-C supports 28V? [Important]
2. Can lvgl be used to create a beautiful UI? [nice-to-have]
3. The current detection function should not only detect the maximum current, but should also be capable of detecting real-time current. [unimportant]

chum998, 2025-07-14:
Thanks
theoretical power derived from duty cycle control and the measured dynamic power may   be different    , while real-time current measurements enable dynamic power calculations

AxxAxx, 2025-07-15:
Yes it can vary. Real-time current measurements are continously taken and is just not shown in the UI.
I think the bar-graph of power shows more useful information than a current of "3.4A" for example.
I understand that the power graph based on duty cycle is not exact but as an indication is it fine.

Closed 2025-07-18.

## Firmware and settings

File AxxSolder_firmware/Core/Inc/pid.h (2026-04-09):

#ifndef INC_PID_H
#define INC_PID_H

/* Include */
#include <stdint.h>
#include <string.h>
#include "main.h"
#include "stm32g4xx_hal.h"       /* Import HAL library */
#include <math.h>

#define DEFAULT_SAMPLE_TIME_MS 100
#define DEFAULT_PWM_MAX 100

/* PID Mode */
typedef enum{
	_PID_MODE_MANUAL    = 0,
	_PID_MODE_AUTOMATIC = 1
}PIDMode_TypeDef;

/* PID Control direction */
typedef enum{
	_PID_CD_DIRECT  = 0,
	_PID_CD_REVERSE = 1
}PIDCD_TypeDef;

/* PID Structure */
typedef struct{

	PIDMode_TypeDef InAuto;
	PIDCD_TypeDef   ControllerDirection;

	uint32_t        LastTime;
	uint32_t        SampleTime;

	uint32_t        updateOnEveryCall;

	float          DispKp;
	float          DispKi;
	float          DispKd;

	float          Kp;
	float          Ki;
	float          Kd;

	float          DispKp_part;
	float          DispKi_part;
	float          DispKd_part;

	volatile float *MyInput;
	volatile float *MyOutput;
	volatile float *MySetpoint;

	float          OutputSum;
	float          LastInput;

	float          OutMin;
	float          OutMax;

	float          IMin;
	float          IMax;

	float			IminError;

	float			NegativeErrorIgainMultiplier;
	float			NegativeErrorIgainBias;

}PID_TypeDef;

/* Init */
void PID_Init(PID_TypeDef *uPID);

void PID(PID_TypeDef *uPID, volatile float *Input, volatile float *Output, volatile float *Setpoint, float Kp, float Ki, float Kd, PIDCD_TypeDef ControllerDirection);

/* Function to clamp d between the limits min and max */
float float_clamp(float d, float min, float max);

/* Function to check if clamping will occur */
uint8_t check_clamping(float d, float min, float max);

/* Computing */
uint8_t PID_Compute(PID_TypeDef *uPID);

/* PID Limits */
void PID_SetOutputLimits(PID_TypeDef *uPID, float Min, float Max);

/* PID I-windup Limits */
void PID_SetILimits(PID_TypeDef *uPID, float Min, float Max);

/* Minimum error where I is added */
void PID_SetIminError(PID_TypeDef *uPID, float IminError);

/* Set the I gain multiplier for negative error*/
void PID_SetNegativeErrorIgainMult(PID_TypeDef *uPID, float NegativeErrorIgainMultiplier, float NegativeErrorIgainBias);

/* PID Tunings */
void PID_SetTunings(PID_TypeDef *uPID, float Kp, float Ki, float Kd);

/* PID Direction */
void          PID_SetControllerDirection(PID_TypeDef *uPID, PIDCD_TypeDef Direction);
PIDCD_TypeDef PID_GetDirection(PID_TypeDef *uPID);

/* PID Sampling */
void PID_SetSampleTime(PID_TypeDef *uPID, int32_t NewSampleTime, int32_t updateOnCall);

void PID_SetMode(PID_TypeDef *uPID, PIDMode_TypeDef Mode);

/* Get Tunings Param */
float PID_GetKp(PID_TypeDef *uPID);
float PID_GetKi(PID_TypeDef *uPID);
float PID_GetKd(PID_TypeDef *uPID);

/* Get current contributions */
float PID_GetPpart(PID_TypeDef *uPID);
float PID_GetIpart(PID_TypeDef *uPID);
float PID_GetDpart(PID_TypeDef *uPID);

#endif

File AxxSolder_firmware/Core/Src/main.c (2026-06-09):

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
/* Includes ------------------------------------------------------------------*/
#include "main.h"

/* USER CODE BEGIN Includes */
#include "lcd.h"
#include "gui.h"
#include "string.h"
#include "pid.h"
#include "moving_average.h"
#include "hysteresis.h"
#include "type_packers.h"
#include "storage.h"
#include "tip_profile.h"
#include "menu_profiles.h"
#include "buzzer.h"
#include "debug.h"
#include "menu_settings.h"
#include "sensors.h"
#include "heater.h"
#include "handle.h"
#include "encoder.h"
#include "buttons.h"
#include "stand.h"
#include "settings.h"
#include "telemetry.h"
#include "power_source.h"
#include "display_app.h"
#include "controller.h"
#include <math.h>
#include <stdio.h>
#include <float.h>
#include "graph.h"
//#include "usbd_cdc_if.h"
/* USER CODE END Includes */

/* USER CODE BEGIN PTD */
/* PID_TUNING build switch lives in controller.h (its #ifdef consumer is in controller.c) */

uint32_t previous_measure_current_update = 0;
uint32_t interval_measure_current = 250;

uint32_t previous_sensor_update_high_update = 0;
uint32_t interval_sensor_update_high_update = 10;

uint32_t previous_sensor_update_low_update = 0;
uint32_t interval_sensor_update_low_update = 100;

/* Flag to indicate that startup sequence is done */
uint8_t startup_done = 0;

/* Struct to hold sensor values */
struct sensor_values_struct {
	float set_temperature;
	float thermocouple_temperature;
	float thermocouple_temperature_previous;
	float thermocouple_temperature_filtered;
	float requested_power;
	float requested_power_filtered;
	float bus_voltage;
	float heater_current;
	uint16_t leak_current;
	float mcu_temperature;
	float in_stand;
	float handle1_sense;
	float handle2_sense;
	mainstates current_state;
	mainstates previous_state;
	float max_power_watt;
	float USB_PD_power_limit;
};

/* Struct to hold sensor values */
volatile sensor_values_struct sensor_values = {
    .set_temperature = 0.0f,
    .thermocouple_temperature = 0.0f,
    .thermocouple_temperature_previous = 0.0f,
    .thermocouple_temperature_filtered = 0.0f,
    .requested_power = 0.0f,
    .requested_power_filtered = 0.0f,
    .bus_voltage = 0.0f,
    .heater_current = 0.0f,
    .leak_current = 0,
    .mcu_temperature = 0.0f,
    .in_stand = 0.0f,
    .handle1_sense = 0.0f,
    .handle2_sense = 0.0f,
    .current_state = SLEEP,
    .previous_state = SLEEP,
    .max_power_watt = 0.0f,
    .USB_PD_power_limit = FLT_MAX
};
/* USER CODE END PTD */

ADC_HandleTypeDef hadc1;
ADC_HandleTypeDef hadc2;
DMA_HandleTypeDef hdma_adc1;
DMA_HandleTypeDef hdma_adc2;

CRC_HandleTypeDef hcrc;

I2C_HandleTypeDef hi2c1;

SPI_HandleTypeDef hspi2;
DMA_HandleTypeDef hdma_spi2_tx;

TIM_HandleTypeDef htim1;
TIM_HandleTypeDef htim2;
TIM_HandleTypeDef htim4;
TIM_HandleTypeDef htim6;
TIM_HandleTypeDef htim7;
TIM_HandleTypeDef htim8;
TIM_HandleTypeDef htim16;
TIM_HandleTypeDef htim17;

UART_HandleTypeDef huart1;
DMA_HandleTypeDef hdma_usart1_tx;

void SystemClock_Config(void);
static void MX_GPIO_Init(void);
static void MX_DMA_Init(void);
static void MX_ADC1_Init(void);
static void MX_ADC2_Init(void);
static void MX_CRC_Init(void);
static void MX_TIM1_Init(void);
static void MX_TIM2_Init(void);
static void MX_TIM4_Init(void);
static void MX_SPI2_Init(void);
static void MX_I2C1_Init(void);
static void MX_USART1_UART_Init(void);
static void MX_TIM7_Init(void);
static void MX_TIM8_Init(void);
static void MX_TIM6_Init(void);
static void MX_TIM16_Init(void);
static void MX_TIM17_Init(void);
/* USER CODE BEGIN 0 */

void HAL_GPIO_EXTI_Callback(uint16_t GPIO_Pin) {
    buttons_isr_exti(GPIO_Pin);
}

void HAL_TIM_IC_CaptureCallback(TIM_HandleTypeDef *htim) {
    if ((htim->Channel == HAL_TIM_ACTIVE_CHANNEL_1) || (htim->Channel == HAL_TIM_ACTIVE_CHANNEL_2)) {
        encoder_isr_capture();
    }
}

/* Timer Callbacks */
void HAL_TIM_PWM_PulseFinishedCallback(TIM_HandleTypeDef *htim){
    if (htim->Instance == TIM1 && htim->Channel == HAL_TIM_ACTIVE_CHANNEL_1) {
        heater_isr_pwm_ch1_pulse_finished();
    }
}

void HAL_TIM_PeriodElapsedCallback(TIM_HandleTypeDef *htim) {
    /* Dispatch by timer instance. */
    if      (htim == &htim6)  sensors_isr_thermocouple_window_start();
    else if (htim == &htim7)  sensors_start_adc_sample();
    else if (htim == &htim17) buzzer_isr_beep_done();
    else if (htim == &htim16) buttons_isr_debounce_tick();
}
/* ADC conversion completed Callbacks */
void HAL_ADC_ConvCpltCallback(ADC_HandleTypeDef *hadc) {
    if      (hadc->Instance == ADC1) sensors_isr_thermocouple_complete();
    else if (hadc->Instance == ADC2) heater_isr_current_complete();
}

/* ADC analog watchdog: ground-fault detection on the iron tip */
void HAL_ADC_LevelOutOfWindowCallback(ADC_HandleTypeDef *hadc __unused) {
    LCD_draw_earth_fault_popup();
}

// For DEBUG
//HAL_GPIO_WritePin(USR_1_GPIO_Port, USR_1_Pin, GPIO_PIN_SET);
//HAL_GPIO_WritePin(GPIOB, USR_2_Pin, GPIO_PIN_RESET);
//HAL_GPIO_WritePin(GPIOB, USR_3_Pin, GPIO_PIN_RESET);
//HAL_GPIO_WritePin(GPIOB, USR_4_Pin, GPIO_PIN_RESET);

/* USER CODE END 0 */

/**
  * @brief  The application entry point.
  * @retval int
  */
int main(void)
{

  /* MCU Configuration--------------------------------------------------------*/

  /* Reset of all peripherals, Initializes the Flash interface and the Systick. */
  HAL_Init();

  /* Configure the system clock */
  SystemClock_Config();

  /* Initialize all configured peripherals */
  MX_GPIO_Init();
  MX_DMA_Init();
  MX_ADC1_Init();
  MX_ADC2_Init();
  MX_CRC_Init();
  MX_TIM1_Init();
  MX_TIM2_Init();
  MX_TIM4_Init();
  MX_SPI2_Init();
  MX_I2C1_Init();
  MX_USART1_UART_Init();
  MX_TIM7_Init();
  MX_TIM8_Init();
  MX_TIM6_Init();
  MX_TIM16_Init();
  MX_TIM17_Init();
  /* USER CODE BEGIN 2 */

	heater_set_duty(0);		//Set heater duty to zero to ensure zero startup current
	HAL_TIMEx_PWMN_Start_IT(&htim1, TIM_CHANNEL_3);

	HAL_TIM_Encoder_Start_IT(&htim2, TIM_CHANNEL_ALL);
	HAL_TIM_PWM_Start_IT(&htim1, TIM_CHANNEL_1);
	__HAL_TIM_SET_COMPARE(&htim4, TIM_CHANNEL_2, 50); //Set BUZZER duty to 50%
	HAL_TIM_Base_Start_IT(&htim6);

	__HAL_TIM_ENABLE_IT(&htim7, TIM_IT_UPDATE);

	HAL_ADCEx_Calibration_Start(&hadc2, ADC_SINGLE_ENDED);

	HAL_ADCEx_Calibration_Start(&hadc1, ADC_SINGLE_ENDED);
	HAL_ADC_Start_DMA(&hadc1, sensors_adc1_buf(), sensors_adc1_buf_len());	//Start ADC DMA mode

  /* USER CODE END 2 */

  /* Infinite loop */
  /* USER CODE BEGIN WHILE */
	HAL_Delay(200);

	/* Check if user data in flash is valid, if not - write default parameters */
	settings_init();

	/* Load tip profiles from storage */
	tip_profiles_init(STORAGE_PROFILES_DRIVER);

	/* Initiate display */
	LCD_init();

	LCD_SetRotation(flash_values.screen_rotation);

	/* Apply encoder direction setting */
	if(flash_values.change_enc_dir == 1){
		MX_TIM2_Init();
	}

	/* Set startup state */

	/* Set initial encoder timer value (used directly as temperature in
	   3-button mode) and seed the set temperature (normal rotary mode reads
	   the encoder as a relative delta, so it needs an explicit start value). */
	TIM2->CNT = flash_values.startup_temperature;
	sensor_values.set_temperature = flash_values.startup_temperature;

	/* initialize moving average functions */
	Moving_Average_Init(&thermocouple_temperature_filter_struct,(uint32_t)2);
	Moving_Average_Init(&thermocouple_temperature_filtered_filter_struct,(uint32_t)flash_values.displayed_temp_filter*10);
	Moving_Average_Init(&requested_power_filtered_filter_struct,(uint32_t)20);
	Moving_Average_Init(&mcu_temperature_filter_struct,(uint32_t)100);
	Moving_Average_Init(&input_voltage_filterStruct,(uint32_t)25);
	Moving_Average_Init(&current_filterStruct,(uint32_t)2);
	Moving_Average_Init(&stand_sense_filterStruct,(uint32_t)20);
	Moving_Average_Init(&handle1_sense_filterStruct,(uint32_t)20);
	Moving_Average_Init(&handle2_sense_filterStruct,(uint32_t)20);

	/* initialize hysteresis functions */
	Hysteresis_Init(&thermocouple_temperature_filtered_hysteresis, 0.5f);

	/* Init and fill filter structures with initial values */
	for (int i = 0; i<200;i++){
		sensors_get_bus_voltage(); // Function to retrieve the filtered bus voltage
		sensors_get_heater_current(); // Function to retrieve the filtered heater current
		sensors_get_mcu_temp(); // Function to retrieve the MCU temperature
		sensors_get_thermocouple_temperature(); // Get thermocouple temperature
		handle_detect(); // Get the handle type attached
		handle_apply_settings(); // Function to set heating values depending on the detected handle
		stand_update(); // Get handle stand status to activate SLEEP
		buttons_handle(); // Function to get button status
		handle_check_cartridge(); // Function to monitor cartridge presence
	}

	/* Initiate PID controller */
	controller_init();

	/* check STUSB4500 */
	power_source_init();

	/* Draw the main screen decoration */
	if (flash_values.display_graph == 0){
		LCD_draw_main_screen();
	}
	else{
		//UG_FillScreen(background);
		draw_graph_init();
	}
	HAL_Delay(250);

	/* Set beep tone */
	switch((int)flash_values.beep_tone){
		case 0: {
			set_tone(1500, 10);
			break;
		}
		case 1: {
			set_tone(1500, 50);
			break;
		}
		case 2: {
			set_tone(800, 10);
			break;
		}
		case 3: {
			set_tone(800, 50);
			break;
		}
	}

    /* Start-up beep */
	beep_double(flash_values.startup_beep);

	//Flag to indicate that the startup sequence is done
	startup_done = 1;
	sensor_values.thermocouple_temperature_previous = sensor_values.thermocouple_temperature;

	/* "Heat at startup": preheat to the standby temperature on power-on.
	   Deferred until a tip is detected (see the one-shot in the main loop) -
	   doing it here would be immediately overridden by handle_check_cartridge,
	   which forces EMERGENCY_SLEEP until the first current measurement proves a
	   tip is present (heater_current starts at 0). */
	uint8_t heat_at_startup_pending = (flash_values.heat_at_startup == 1);

	/* Initiate the PID controller to zero*/
	//PID_Init_Zero();

	while (1){

		if(HAL_GetTick() - previous_sensor_update_high_update >= interval_sensor_update_high_update){
			stand_update();
			handle_detect();
			handle_apply_settings();
			encoder_read_set_temperature();
			buttons_handle();
			handle_emergency_shutdown();
			handle_check_cartridge();
			/* One-shot preheat: once a tip is confirmed present, enter STANDBY
			   if "heat at startup" is enabled. Deferred to here so the cartridge
			   check above (which forces EMERGENCY_SLEEP while heater_current < 1)
			   doesn't immediately clobber it. */
			if(heat_at_startup_pending && (cartridge_state == ATTACHED)){
				change_state(STANDBY);
				previous_millis_standby = HAL_GetTick();
				heat_at_startup_pending = 0;
			}
			previous_sensor_update_high_update = HAL_GetTick();
		}

		if(HAL_GetTick() - previous_sensor_update_low_update >= interval_sensor_update_low_update){
			sensors_get_bus_voltage();
			sensors_get_heater_current();
			sensors_get_mcu_temp();
			beep_at_set_temp();
			previous_sensor_update_low_update = HAL_GetTick();
		}

		/* Compute PID + switch + PID Tuning manual control */
		controller_tick();

		/* Send debug information */
		telemetry_tick();

		/* Detect if a tip is present by sending a short voltage pulse and sense current */
		if (flash_values.current_measurement == 1){

			if (HAL_GetTick() - previous_measure_current_update >= interval_measure_current) {
				// Perform current measurement only if thermocouple measurement is not in progress.
				if (sensors_thermocouple_sampling_idle()) {
					heater_start_current_measurement();
					previous_measure_current_update = HAL_GetTick();
				}
			}
		}
		else{
			sensor_values.heater_current = 1; // If the current is not measured, apply a dummy value to heater_current
		}

		/* Update display (popup dwell + periodic render inside display_app_tick) */
		display_app_tick();
    /* USER CODE END WHILE */

    /* USER CODE BEGIN 3 */
  }
  /* USER CODE END 3 */
}

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


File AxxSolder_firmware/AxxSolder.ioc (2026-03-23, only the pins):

Mcu.UserName=STM32G431CBTx
PA0.GPIO_Label=ENC_A
PA0.Signal=S_TIM2_CH1
PA1.GPIO_Label=I_LEAK
PA1.Signal=ADC2_IN2
PA10.Signal=USART1_RX
PA13.Signal=SYS_JTMS-SWDIO
PA14.Signal=SYS_JTCK-SWCLK
PA15.Signal=I2C1_SCL
PA2.GPIO_Label=VBUS
PA2.Signal=ADC1_IN3
PA3.GPIO_Label=THERMOCOUPLE
PA3.Signal=ADC1_IN4
PA4.GPIO_Label=HANDLE_INP_1
PA4.Signal=GPIO_Input
PA5.GPIO_Label=HANDLE_INP_2
PA5.Signal=GPIO_Input
PA6.GPIO_Label=STAND_INP
PA6.Signal=GPIO_Input
PA7.GPIO_Label=SW_2
PA7.Signal=GPXTI7
PA8.GPIO_Label=USR_1
PA8.Signal=GPIO_Output
PA9.Signal=USART1_TX
PB0.GPIO_Label=USR_2
PB0.Signal=GPIO_Output
PB1.GPIO_Label=USR_3
PB1.Signal=GPIO_Output
PB10.GPIO_Label=SPI2_SD_CS
PB10.Signal=GPIO_Output
PB11.GPIO_Label=SPI2_DC
PB11.Signal=GPIO_Output
PB12.GPIO_Label=SPI2_RST
PB12.Signal=GPIO_Output
PB13.Signal=SPI2_SCK
PB14.GPIO_Label=SPI2_CS
PB14.Signal=GPIO_Output
PB15.Signal=SPI2_MOSI
PB2.GPIO_Label=USR_4
PB2.Signal=GPIO_Output
PB3.GPIO_Label=ENC_B
PB3.Signal=S_TIM2_CH2
PB5.GPIO_Label=SW_1
PB5.Signal=GPXTI5
PB7.GPIO_Label=BUZZER
PB7.Signal=S_TIM4_CH2
PB8-BOOT0.GPIO_Label=SW_3
PB8-BOOT0.Signal=GPXTI8
PB9.Signal=I2C1_SDA
PC13.GPIO_Label=VERSION_BIT_1
PC13.Signal=GPIO_Input
PC14-OSC32_IN.GPIO_Label=VERSION_BIT_2
PC14-OSC32_IN.Signal=GPIO_Input
PC15-OSC32_OUT.GPIO_Label=VERSION_BIT_3
PC15-OSC32_OUT.Signal=GPIO_Input
PF0-OSC_IN.GPIO_Label=HEATER
PF0-OSC_IN.Signal=TIM1_CH3N
PF1-OSC_OUT.GPIO_Label=CURRENT
PF1-OSC_OUT.Signal=ADC2_IN10

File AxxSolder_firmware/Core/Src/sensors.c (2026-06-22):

#include "sensors.h"
#include "heater.h"           // current_raw, heater_off, heater_update_pwm
#include "handle.h"           // enum handles, attached_handle
#include "state_machine.h"    // handle_delta_temperature (called from ADC1 complete)
#include "moving_average.h"   // Moving_Average_Compute / _Set_Value
#include "hysteresis.h"       // Hysteresis_Add
#include "tip_profile.h"      // tip_profiles_get_cal
#include "main.h"             // sensor_values, flash_values, GPIO macros
#include "util.h"             // clamp
#include <math.h>             // fabsf

extern TIM_HandleTypeDef htim6;
extern TIM_HandleTypeDef htim7;
extern ADC_HandleTypeDef hadc1;

/* --- Thermocouple state --- */
static float    TC_temp = 0;                  /* post-outlier-filter, post-moving-average raw value */
static float    TC_temp_from_ADC = 0;
static float    TC_temp_from_ADC_previous = 0;
static float    TC_temp_from_ADC_diff = 0;
static uint16_t TC_outliers_detected = 0;

/* --- Thermocouple sample-coordination flag ---
 * Set to 0 when TIM6 fires (window opens); set to 1 when the ADC1
 * conversion completes. main.c reads it via sensors_thermocouple_sampling_idle()
 * to gate the heater current-measurement pulse so the two ADCs don't
 * fire on top of each other. */
static volatile uint8_t thermocouple_measurement_done = 1;

/* --- Moving-average filters (file-scope; main.c initializes them) --- */
FilterTypeDef thermocouple_temperature_filter_struct;
FilterTypeDef thermocouple_temperature_filtered_filter_struct;
FilterTypeDef mcu_temperature_filter_struct;
FilterTypeDef input_voltage_filterStruct;
FilterTypeDef current_filterStruct;

/* --- Hysteresis filter --- */
Hysteresis_FilterTypeDef thermocouple_temperature_filtered_hysteresis;

/* --- TC compensation polynomials (per handle family) --- */
#define TC_OUTLIERS_THRESHOLD 300

#define TC_COMPENSATION_X2_T210 (4.223931712905644e-06f)
#define TC_COMPENSATION_X1_T210 0.31863796444354214f
#define TC_COMPENSATION_X0_T210 20.968033870812942f

#define TC_COMPENSATION_X2_T245 (-4.735112838956741e-07f)
#define TC_COMPENSATION_X1_T245 0.11936452029674384f
#define TC_COMPENSATION_X0_T245 23.777399955382318f

#define TC_COMPENSATION_X2_NT115 (5.1026665462522864e-05f)
#define TC_COMPENSATION_X1_NT115 0.42050803230712813f
#define TC_COMPENSATION_X0_NT115 20.14538589052425f

/* --- ADC scaling constants --- */
#define VOLTAGE_COMPENSATION 0.00840442388f
#define CURRENT_COMPENSATION 0.002864f

/* MCU internal temperature sensor */
#define V30        0.76f             /* from datasheet */
#define VSENSE     (3.3f / 4096.0f)
#define Avg_Slope  0.0025f           /* 2.5 mV / °C from datasheet */

/* --- ADC1 DMA buffer (3 channels, 19 samples each, interleaved) --- */
#define ADC1_BUF_LEN 57   /* 3 * 19 */
static uint16_t ADC1_BUF[ADC1_BUF_LEN];

/* ADC1 DMA buffer accessors (used by main.c to start the DMA). */
uint32_t * sensors_adc1_buf(void)   { return (uint32_t*)ADC1_BUF; }
uint32_t   sensors_adc1_buf_len(void) { return (uint32_t)ADC1_BUF_LEN; }

/**
 * @brief Returns the average value of 100 readings at index + 3*n in the ADC_buffer vector.
 * It is assumed that ADC1_BUF contains data from 3 channels, collected sequentially.
 * For example, if index == 0, elements 0, 3, 6, ... are used;
 * if index == 1, then 1, 4, 7, ... and so on.
 * @param index Channel index (0, 1, or 2)
 * @return Average value for that channel
 */
static float get_mean_ADC_reading_indexed(uint8_t index){
    if (index > 2) return 0.0f;  // Incorrect Index Protection

    float ADC_filter_mean = 0.0f;
    int count = 0;

    for (int n = index; n < ADC1_BUF_LEN; n += 3) {
        ADC_filter_mean += ADC1_BUF[n];
        count++;
    }

    return (count > 0) ? (ADC_filter_mean / (float)count) : 0.0f;
}

void sensors_get_thermocouple_temperature(){
	/* --- Step 1: Outlier filter on raw ADC data --- */
	TC_temp_from_ADC_previous = TC_temp_from_ADC;
	TC_temp_from_ADC = get_mean_ADC_reading_indexed(1);
	TC_temp_from_ADC_diff = fabsf(TC_temp_from_ADC_previous - TC_temp_from_ADC);

	if((TC_temp_from_ADC_diff > TC_OUTLIERS_THRESHOLD) && (TC_outliers_detected < 2)){
		TC_outliers_detected++;
		if(TC_outliers_detected < 2){
			TC_temp_from_ADC = TC_temp_from_ADC_previous;
		}
	}
	else{
		TC_outliers_detected = 0;
	}

	/* --- Step 2: Moving average filter --- */
	TC_temp = Moving_Average_Compute(TC_temp_from_ADC, &thermocouple_temperature_filter_struct); /* Moving average */

	/* --- Step 3: Apply handle-specific compensation polynomial --- */
	if(attached_handle == T210){
		sensor_values.thermocouple_temperature = TC_temp*TC_temp*TC_COMPENSATION_X2_T210 + TC_temp*TC_COMPENSATION_X1_T210 + TC_COMPENSATION_X0_T210;
	}
	else if(attached_handle == T245){
		sensor_values.thermocouple_temperature = TC_temp*TC_temp*TC_COMPENSATION_X2_T245 + TC_temp*TC_COMPENSATION_X1_T245 + TC_COMPENSATION_X0_T245;
	}
	else if(attached_handle == NT115){
		sensor_values.thermocouple_temperature = TC_temp*TC_temp*TC_COMPENSATION_X2_NT115 + TC_temp*TC_COMPENSATION_X1_NT115 + TC_COMPENSATION_X0_NT115;
	}
	else{
		/* Unknown handle - report temperature as setpoint so PID output is zero (heater off) */
		sensor_values.thermocouple_temperature = sensor_values.set_temperature;
	}

	/* --- Step 4: Adjust measured temperature to fit calibrated values from active tip profile */
	float cal_100 = tip_profiles_get_cal(attached_handle, 0);
	float cal_200 = tip_profiles_get_cal(attached_handle, 1);
	float cal_300 = tip_profiles_get_cal(attached_handle, 2);
	float cal_350 = tip_profiles_get_cal(attached_handle, 3);
	float cal_400 = tip_profiles_get_cal(attached_handle, 4);
	float cal_450 = tip_profiles_get_cal(attached_handle, 5);

	if(sensor_values.thermocouple_temperature < 100){
		sensor_values.thermocouple_temperature = sensor_values.thermocouple_temperature*(cal_100)/100.0f;
		}
	else if(sensor_values.thermocouple_temperature < 200){
		sensor_values.thermocouple_temperature = (sensor_values.thermocouple_temperature - 100.0f)*(cal_200-cal_100)/100.0f + cal_100;
		}
	else if(sensor_values.thermocouple_temperature < 300){
		sensor_values.thermocouple_temperature = (sensor_values.thermocouple_temperature - 200.0f)*(cal_300-cal_200)/100.0f + cal_200;
	}
	else if(sensor_values.thermocouple_temperature < 350){
		sensor_values.thermocouple_temperature = (sensor_values.thermocouple_temperature - 300.0f)*(cal_350-cal_300)/50.0f + cal_300;
		}
	else if(sensor_values.thermocouple_temperature < 400){
		sensor_values.thermocouple_temperature = (sensor_values.thermocouple_temperature - 350.0f)*(cal_400-cal_350)/50.0f + cal_350;
		}
	else{
		sensor_values.thermocouple_temperature = (sensor_values.thermocouple_temperature - 400.0f)*(cal_450-cal_400)/50.0f + cal_400;
		}
	// Add temperature offset value
	sensor_values.thermocouple_temperature += flash_values.temperature_offset;
	// Clamp
	sensor_values.thermocouple_temperature = clamp(sensor_values.thermocouple_temperature ,0 ,500);
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

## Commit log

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2023-10-03 Add AxxSolder V2.0 BOM with cost
    [BOM_AxxSolder_V2_0.xlsx]
2023-10-03 update BOM_AxxSolder_V2_0-xlsx with cleaner links
    [BOM_AxxSolder_V2_0.xlsx]
2023-10-06 Change to new, more cost effective VCC->5V DC/DC solution, update to AxxSolder V2.1
    [AxxSolder-B_Cu.gbr, AxxSolder-B_Mask.gbr, AxxSolder-B_Paste.gbr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]
2023-10-06 Clean and structure schematic and update to AxxSolder V2.1
    [AxxSolder.kicad_sch]
2023-10-06 Clean and structure PCB Layout and update to AxxSolder V2.1
    [AxxSolder.kicad_pcb, AxxSolder.kicad_sch]
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2023-10-07 Change silkscreen to Input: 9-24V and optimize board layout
    [AxxSolder-B_Cu.gbr, AxxSolder-B_Mask.gbr, AxxSolder-B_Paste.gbr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]
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2023-10-08 Update schematic to reflect new naming of inputs, Stand_inp and Handle_inp
    [AxxSolder.kicad_sch]
2023-10-09 Add screws and fuse to BOM
    [BOM_AxxSolder_V2_1.xlsx]
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2023-10-09 Update schematic with proper connections
    [AxxSolder.kicad_sch]
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2023-10-10 Add software filter to handle EMI noise due to switching frequency
    [main.c]
2023-10-10 Add EMERGENCY_CLEEP if the temperature is too high and clean up code
    [AxxSolder.ioc, main.c]
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2023-10-14 Fix output voltage from DC/DC by switching values of R28 and R27. Also change value of C24
    [AxxSolder.kicad_pcb, AxxSolder.kicad_sch, BOM_AxxSolder_V2_1.xlsx]
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2023-10-15 Improve PCB layout slightly and update gerbers with cu-filled GND layer
    [AxxSolder-B_Cu.gbr, AxxSolder-B_Mask.gbr, AxxSolder-B_Paste.gbr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]
2023-10-16 Update BOM with C25 to be a 0805 Capacitor
    [BOM_AxxSolder_V2_1.xlsx]
2023-10-18 Update PCB design to V2.2 - correct fault in 5V DC/DC and change the VDD tVS diode to a 600W instead of 1.5kW and small PCB improvements
    [AxxSolder-B_Cu.gbr, AxxSolder-B_Mask.gbr, AxxSolder-B_Paste.gbr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]
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2023-10-21 Update schematic to have show correct intenrnal connestions of JBC cartridges according to https://www.eevblog.com/forum/projects/axxsolder-jbc-soldering-controller/msg5124267/#msg5124267
2023-10-21 update CAD and add portable CAD without place for stand
    [AxxSolder_Portable_bottom.STL, AxxSolder_Portable_top_without_stand.STL, AxxSolder_Portable_without_stand.STEP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]
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2023-11-19 Fix bug related to writing flash values to struct
    [main.c]
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2023-11-19 Revert "remove PCB from main repository"
    This reverts commit d0cf19f25690a61a5ed670c7fa3116f226ceb6ca.
    [AxxSolder-B_Cu.gbr, AxxSolder-B_Mask.gbr, AxxSolder-B_Paste.gbr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]
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2023-11-23 Fix bug in ADC indexing and optimize flash_data struct
    [main.c, main.h]
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2023-11-27 Fix issue with temperature clamping
    [main.c]
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2024-01-07 Update README.md - fix /bom URL
2024-01-09 update many files to align with AxxSolder V3 hardware
    [Anderson_PowerPole.SLDASM, AxxSolder_Portable.STEP, AxxSolder_Portable_bottom.STL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]
2024-01-09 update pin definitions and migrate STM32G4 to STM32F3
    [Encolsure_JBC-AD-SF.SLDPRT]
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2024-02-16 Updates on hardware, new DC-DC step down driver, new LDO, new ESD protection for USB, new Capacitor selection on input
    [AxxSolder.kicad_pcb, AxxSolder.kicad_sch, EMZR350ARA151MF80G.stp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]
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2024-02-16 Update enclosure design to better fit new AxxSolder 3.0 hardware
    [Encolsure_JBC-AD-SF.SLDPRT]
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2024-02-20 Final changes after sending AxxSolder 3.0 for manufacturing
    [AxxSolder-B_Cu.gbr, AxxSolder-B_Mask.gbr, AxxSolder-B_Paste.gbr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]
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2024-02-21 go into emergency sleep if bus voltage is too low
    [main.c]
2024-02-23 Update to new fuse and add alternative buzzer
    [AxxSolder.kicad_pcb, AxxSolder.kicad_sch, BOM_AxxSolder_V3_0.csv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]
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2024-02-25 Implement ADC watchdog for I-leak and DMA for current measurement
    [AxxSolder.ioc, main.c, main.h]
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2024-02-29 Update CAD with minor tolerance adjustments
    [AxxSolder_Encolsure_Portable_Bottom.STEP, AxxSolder_Encolsure_Portable_Bottom.STL, AxxSolder_Encolsure_Portable_Top.STEP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]
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2024-02-29 update current sense resistor to 100m ohm from 560m ohm
    [AxxSolder.kicad_pcb, AxxSolder.kicad_sch, BOM_AxxSolder_V3_0.csv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]
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2024-03-25 remove beep after error message
    [main.c]
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2024-03-28 Update and add data for backside manufacturing and assembly
    [AxxSolder.kicad_sch, AxxSolder_manufacturing_BOM.csv]
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2024-04-02 fix problem with reading flash incorrectly
    [main.c]
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2024-04-09 Fix the most obvious flaws that trigger lotsa warnings.
    [lcd.c, main.c, pid.h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]
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2024-04-25 Change -SAVE AND EXIT- To -EXIT AND REBOOT- and reboot after new settings are stored to flash
    [main.c]
2024-04-25 Minor updates on PCB layout such as silkscreen placement and trace alignment
    [AxxSolder-B_Cu.gbr, AxxSolder-B_Mask.gbr, AxxSolder-B_Paste.gbr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]
2024-05-20 Add model of the two brackerts combined into one part with breakaway separators
    [Mounting_Bracket_combined.SLDPRT, Mounting_Bracket_combined.STEP, Mounting_Bracket_combined.STL]
2024-05-20 Update position of Display standoffs and minor PCB layout improvements
    [AxxSolder-B_Cu.gbr, AxxSolder-B_Mask.gbr, AxxSolder-B_Paste.gbr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]
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2024-05-20 Fix bug in binary selection in settings
    [main.c]
2024-05-20 Fix bug in screen rotation settings
    [main.c]
2024-05-20 Fix bug in neagtive temp offset values
    [main.c]
2024-05-20 Fix Version text x-position
    [main.c]
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2024-05-23 updated display layout and now showing power source correctly
    [main.c]
2024-05-25 some code cleanup in STUSB4500 driver, fixed compile warnings
    [main.c, stusb4500.c]
2024-05-27 added fix for SW1 glitch when turning the encoder
    [main.c]
2024-05-27 Add series resistance to button RC filters on schematic and board layout
    [AxxSolder.kicad_pcb, AxxSolder.kicad_sch]
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2024-05-27 Fix power limiting updates to respect a USB PD power limit set at startup
    [main.c]
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2024-05-29 Show max power at correct position on screen for 2 and 3 digit values
    [main.c]
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2024-06-08 Update BOM to correctly color code station and portable parts
    [BOM_AxxSolder_V3_0.xlsx]
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2024-06-15 Update hardware files to match correctly with current version
    [AxxSolder.kicad_pcb, AxxSolder.kicad_sch, AxxSolder_manufacturing_BOM.csv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]
2024-06-15 Update hw design with button filters, optimized traces and better silkscreen
    [AxxSolder-B_Cu.gbr, AxxSolder-B_Mask.gbr, AxxSolder-B_Paste.gbr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]
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2024-06-16 Update red,blue,green labels with correct colors
    [AxxSolder.kicad_sch]
2024-06-20 Updates on schematic and board layout to hw3_1, optimizations and improvement on layout
    [AxxSolder-B_Cu.gbr, AxxSolder-B_Mask.gbr, AxxSolder-B_Paste.gbr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]
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2024-09-06 Add function to check for large delta temperatures
    [Encolsure_Portable.SLDPRT]
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2024-09-06 Break out buzzer functions to a separate file
    [main.c]
2024-09-06 Add heater_off() to Error_handler()
    [main.c]
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2024-09-11 Update tolerances and structure of CAD
    [AxxSolder_Encolsure_Portable_Bottom.STEP, AxxSolder_Encolsure_Portable_Bottom.STL, AxxSolder_Encolsure_Portable_Top.STEP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]
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2024-09-19 Use shorter moving average filter window before PID to minimize lag
    [main.c]
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2024-09-21 Update thickness of stand bracket from 3mm to 2.5mm
    [AxxSolder_Encolsure_Portable_Top_Earth_Stand.STEP, AxxSolder_Encolsure_Portable_Top_Earth_Stand.STL, AxxSolder_Encolsure_Portable_Top_Earth_Stand_RockerSwitch.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]
2024-09-24 Correct typo in BOM
    [BOM_AxxSolder_V3_1.xlsx]
2024-09-24 Add Hardware (screws) and update tolerances
    [90236A105_Zinc-Plated Steel Torx Flat Head Screws.SLDPRT, 91292A010_18-8 Stainless Steel Socket Head Screw.SLDPRT, 91292A019_18-8 Stainless Steel Socket Head S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]
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2024-11-01 Update footprint name of STL9P3LLH6 to be correct
    [AxxSolder.kicad_pcb, AxxSolder.kicad_sch, BOM_AxxSolder_V3_1.xlsx]
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2024-11-03 Add CAD file of JBC-ADS stand with separate top plate for printability
    [Encolsure_JBC-AD-SF_SEPARATED_TOP_bottom.STEP, Encolsure_JBC-AD-SF_SEPARATED_TOP_bottom.STL, Encolsure_JBC-AD-SF_SEPARATED_TOP_top.STEP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]
2024-11-03 Update cutting line position of front panel separation of JBC-ADS stand
    [Encolsure_JBC-AD-SF_SEPARATED_TOP_bottom.STEP, Encolsure_JBC-AD-SF_SEPARATED_TOP_bottom.STL, Encolsure_JBC-AD-SF_SEPARATED_TOP_top.STEP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]
2024-11-04 Add function PID_SetIminError which adds the functionality of only adding Integral part when error is smaller than a certain value
    [main.c, pid.h]
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2024-11-06 Implement separate I gain multiplier for negative error and adjust PID values
    [main.c, pid.h]
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2024-11-08 Make sure equations in PID controller are calculated as floats and fix bug in PID controller
    [main.c, pid.h]
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2024-11-18 Update thickness of stand plate from 3 to 2 millimeter
    [AxxSolder_Encolsure_Portable_Top_Earth_Stand.STEP, AxxSolder_Encolsure_Portable_Top_Earth_Stand_RockerSwitch.STEP, Encolsure_Portable.SLDPRT]
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2024-11-21 Update 0 W location on main screen and add clamp to prevent float miscalculaton
    [main.c]
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2024-12-02 Fix off-by-one bug with max selectable value introduced in last two commits
    [main.c]
2024-12-26 Redefine GPIO to output and set to low in Error_Handler
    [main.c]
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2024-12-26 Update Error_Handler to re-define Heater PWM GPIO to output and pull it low at error
    [main.c]
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2025-03-18 Update hardware to 3.2 with changes in layout and addition of series resistors on op-amp outputs
    [AxxSolder-B_Cu.gbr, AxxSolder-B_Mask.gbr, AxxSolder-B_Paste.gbr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]
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2025-05-20 Fix bug which turned on heating to max if going into the main menu while in RUN mode heating the cartrige
    [main.c]
2025-06-02 Add fix to GUI bug when in landscape mode
    [lcd.c]
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2025-06-09 Update BOM to 3.2 and small layout fix
    [AxxSolder-B_Cu.gbr, AxxSolder-B_Mask.gbr, AxxSolder-B_Paste.gbr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]
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2025-06-22 Fix bug that cases random characters when long-pressing buttons in menu
    [main.c]
2025-07-12 Add buzzer tone adjustment and fix bug in settings menu, bump firmware to 3.4.3
    [buzzer.c, main.c]
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2025-07-13 Initial add of an enclosure for the Geeboon stand.
    - Geeboon sells a fiber-reinforced plastic and Silicone stand which
    vaguely provides the functionality of the JBC ADS stand.
    [Geeboon_Stand.FCStd]
2025-07-13 Add CAD files for Geeboon SDC02 Stand Enclosure.
    - This enclosure matches up with the Geeboon SDC02 Handpiece Stand.
    [Anderson Power Pole.FCStd, Anderson_PowerPole.step, AxxSolder-PCB.FCStd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]
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2025-07-18 Add STEP file of AxxSolder and update location of TFT in KiCad
    [AxxSolder.kicad_pcb]
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2025-07-29 Fix screen rotation setting
    [lcd.c, main.c]
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2025-07-29 Fix minor bug in redraw_menu_screen flag declaration
    [menu_settings.c]
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2025-07-31 Align text on schematic and update Schematic image
    [AxxSolder.kicad_sch]
2025-07-31 Update some comments and linker-file to resolve LOAD segment with RWX permissions warning
    [main.c]
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2025-08-10 Fix bug in NT115 detection
    [main.c]
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2026-03-17 Fix bug in menu grouping
    [menu_settings.c]
2026-03-17 Fix alignment of status box in graph mode
    [main.c, menu_settings.c]
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2026-03-23 Fix bug in cleaning sleep delay field
    [main.c]
2026-03-25 Minor bux fix in function declaration
    [main.c]
2026-04-07 Fix bug with redrawing screen and buttons not working in menu
    [main.c, menu_settings.c]
2026-04-09 Fix divide by 0 in pid.c
2026-04-09 Fix attached_handle == No_name bug
    [main.c]
2026-04-09 Fix bug with number formating
    [main.c]
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2026-04-09 minor bug in pid.c
2026-04-09 minor bug in lcd.c
    [lcd.c]
2026-04-09 minor bug in overtemp function
    [main.c]
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2026-04-11 perf: replace double literals and functions with float equivalents
    All floating-point constants now carry the f suffix (0.5 -> 0.5f),
    fabs/fmod/round replaced with fabsf/fmodf/roundf throughout Core/Src.
    This eliminates the soft-double library (~3.6 KB) from the binary:
    Release Flash drops from 90,064 B to 86,316 B (65.85% of 128 KB).
    [main.c, menu_settings.c, stusb4500.c]
2026-04-11 build: add -Wdouble-promotion warning
    Any implicit float→double promotion will now produce a compiler warning,
    preventing accidental regression of the soft-double elimination.
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2026-04-12 refactor: split LCD driver by controller into separate headers
    - lcd_st7789.h: geometry, MADCTL rotation table, init sequence for ST7789
    - lcd_st7735.h: geometry, MADCTL rotation table, init sequence for ST7735
    - lcd.h: hardware config, error guards, controller header selection
    - CMakeLists.txt: LCD_CONTROLLER / LCD_SIZE / LCD_ROTATION options
    (defaults: ST7789 / 240X320 / 2 — unchanged from before)
    - LCD_SetRotation() simplified via lcd_rotation_cmds[] table
    [lcd.c]
2026-04-12 fix: add missing stdio.h include in debug.c for sprintf
    [debug.c]
2026-04-14 feat: add tip profiles system with flash storage and menu UI
    - Add pluggable StorageDriver abstraction (flash backend, build-time selection)
    - Add dedicated PROFILES/SETTINGS flash sections in linker script (2 KB each)
    - Add TipProfile CRUD with per-handle active profile tracking
    - Add profiles menu UI: list, editor, name editor, quick-select popup
    - Refactor settings menu: MI_ enum with step-100 ranges, remove flash.c/h
    - Move calibration and power limits into per-profile settings
    - Add PROFILES.md documentation with screenshots
    Fixes applied:
    - Fix off-by-one in flash page erase calculation (could corrupt adjacent page)
    - Protect CRC peripheral access with __disable_irq in flash_read/flas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
    [main.c, main.h, menu_profiles.c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]
2026-04-15 fix: address review issues in tip profiles system
    - storage_flash: add erase.Banks = FLASH_BANK_1 to prevent undefined
    erase behavior on STM32G4
    - storage_flash: protect CRC calculation in flash_write with
    __disable_irq/__enable_irq to match flash_read/flash_verify
    - menu_profiles: disable heater (requested_power = 0) while popup
    blocks the main loop to prevent uncontrolled heating
    - menu_profiles: add 5-second timeout to profiles_popup to prevent
    indefinite main loop blockage; resets on user interaction
    - menu_profiles: skip redundant flash write in single-match popup
    when the profile is already active
    - menu_profiles: only save profile on Back if actually modified
    (memcmp check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
    [menu_profiles.c, menu_settings.c, storage_flash.c]
2026-04-17 fix: make 'Profile on tip chg' reachable and refine popup UX
    - Move MI_PROFILE_ON_TIP_CHG into the Mode group so the toggle is
    reachable in Settings (the Profiles group delegates to profiles_menu
    and never rendered the item).
    - Suppress the profile popup during boot by gating it on startup_done,
    so the filter warm-up loop can't trigger a popup with an uninitialized
    attached_handle.
    - Show the popup even when only one profile matches the handle, and
    pre-select the currently active profile for that handle.
    - Repaint the main screen after the popup closes to clear overlay
    residue.
    [main.c, menu_profiles.c, menu_settings.c]
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2026-04-20 fix delete default profiles, add load defaults, add prefix handle type for profile name
    [menu_profiles.c, menu_settings.c]
2026-04-20 Add encoder direction setting and fix Tip preset seletor at tip change
    [main.c, main.h, menu_profiles.c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]
2026-04-20 Fix bug in profile changing popup showing at every boot and at handle change, not tip change
    [main.c, menu_profiles.c]
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2026-04-29 Fix LCD color handling: compile-time BRG565 definitions and STM32G4 SPI data size register
    [lcd.c, main.c, main.h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]
2026-05-16 Fix spelling in comments
    [main.c]
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2026-06-09 Restore original display colours after SPI byte-order fix
    [display_app.c, menu_profiles.c, menu_settings.c]
2026-06-09 Fix PID_TUNING build switch scope and restore heater PWM equivalence
    [heater.c, main.c]
2026-06-09 Fix dead encoder in momentary-stand sleep/standby
    [buttons.c]
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2026-06-09 Fix encoder step size bug
    [encoder.c, main.c]
2026-06-10 fix hw version display
    [menu_settings.c, version.c]
2026-06-10 Fix non-ASCII character bug
    [display_app.c, menu_settings.c]
2026-06-22 Fix USB-PD: single clean 20V negotiation + prime voltage display
    [power_source.c, sensors.c]
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2026-06-23 Fix USB-PD negotiation for max charger power
    [power_source.c, stusb4500.c]
2026-09-06 Addition of the Axxsolder SDC02 stand CAD files and instructions.
    [faceplate.stl, main_body.stl, tray.stl]

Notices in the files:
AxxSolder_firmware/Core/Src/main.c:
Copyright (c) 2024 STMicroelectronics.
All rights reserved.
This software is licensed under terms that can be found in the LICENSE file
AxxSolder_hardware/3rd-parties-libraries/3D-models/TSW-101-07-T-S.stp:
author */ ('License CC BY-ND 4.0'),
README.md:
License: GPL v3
